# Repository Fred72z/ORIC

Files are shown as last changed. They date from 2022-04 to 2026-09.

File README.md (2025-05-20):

# BUS ORIC

Ensemble de platines pouvant se connecter sur un boitier principal connecté au port EXPANSION de l'oric.

# EXP CARTOUCHE
Extension permettant de remplacer la ROM interne par une cartouche ROM externe

# TELESTRAT II et TELESTRAT III

Nouvelles machines TELESTRAT.
(Dans la série si vous ne pouvez pas la trouver, faites la vous-même :)).

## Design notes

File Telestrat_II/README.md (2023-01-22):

# TELESTRAT II

Le TELESTRAT II est un TELESTRAT au format mini-ITX qui prend place dans un boîtier HTPC.
En plus des caractéristiques du TELESTRAT, la machine dispose en interne d'une horloge RTC, de 512Ko de ROM et de 144Ko de RAM et d'un lecteur GOTEK.
La machine est un mix entre l'ORIC ATMOS et le TELESTRAT. Elle dispose de 8 modes de fonctionnement allant de l'ORIC1 au TELESTRAT.
Elle est parfaitement compatible avec ses prédécesseurs ORIC1/ATMOS et microdisc.

Mode ORIC1
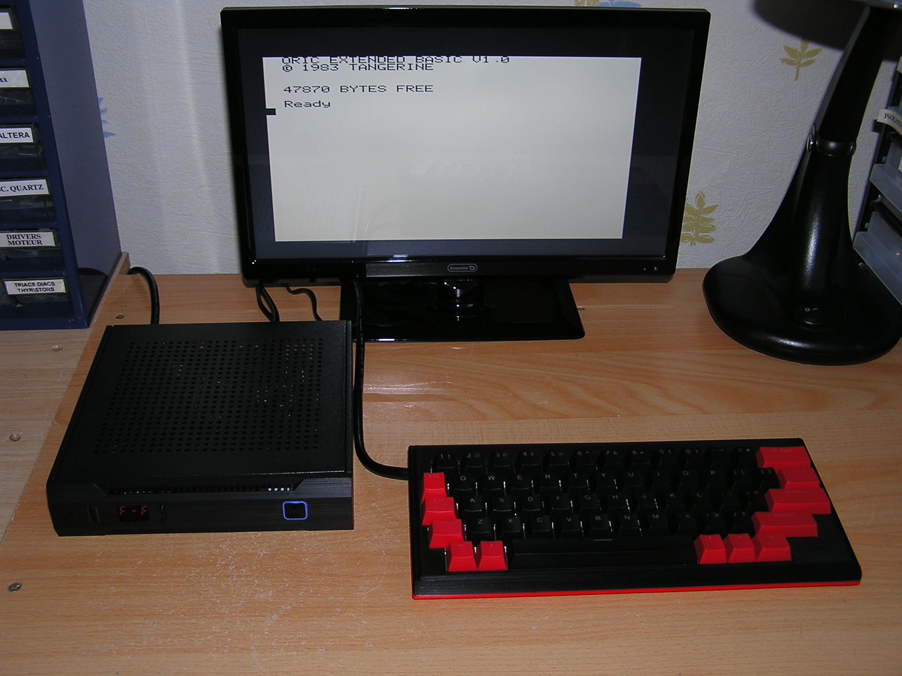
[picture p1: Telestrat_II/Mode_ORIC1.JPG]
Mode ORIC1 Optional Title


Mode ORIC ATMOS avec SEDORIC
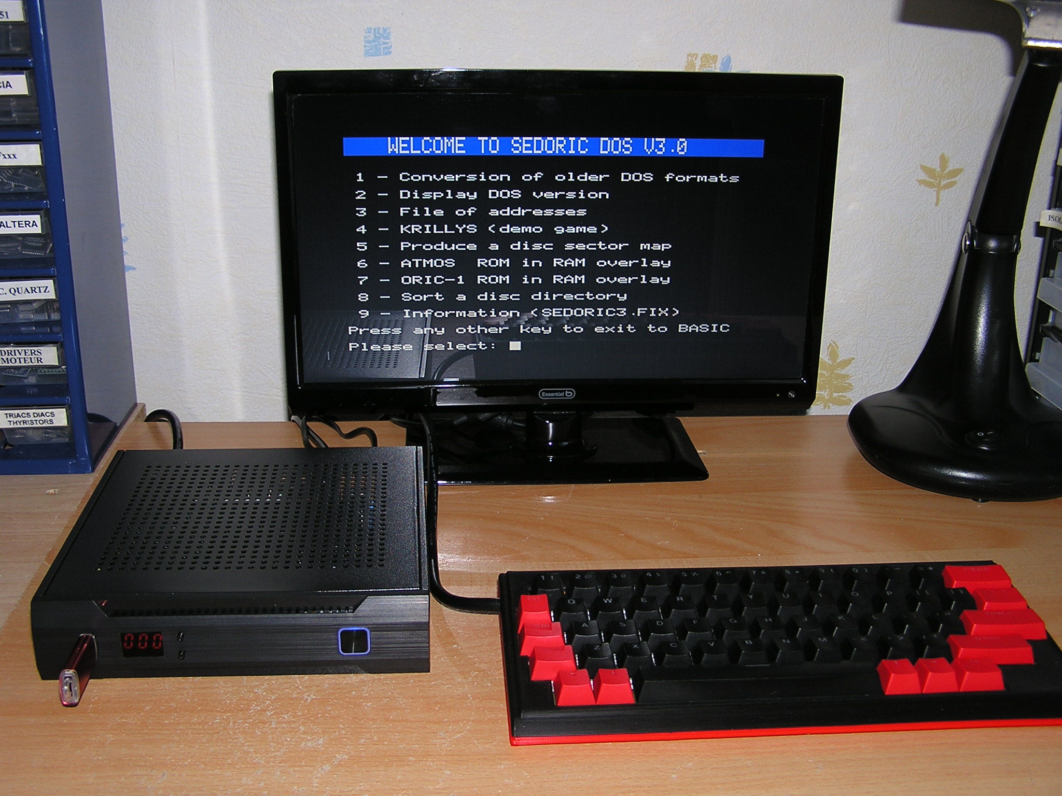
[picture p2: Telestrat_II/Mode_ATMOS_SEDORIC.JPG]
Mode ATMOS SEDORIC Optional Title


Mode TELESTRAT HYPERBASIC
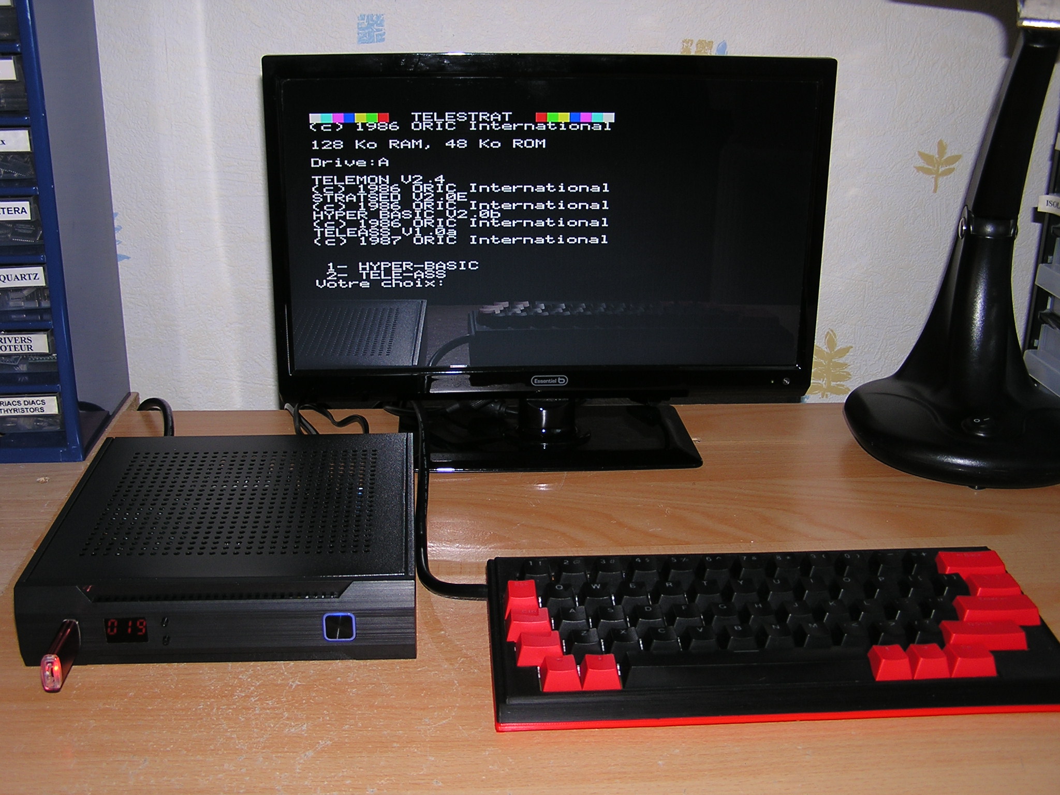
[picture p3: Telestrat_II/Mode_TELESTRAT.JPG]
Mode TELESTRAT HYPERBASIC Optional Title


Intérieur de la boîte
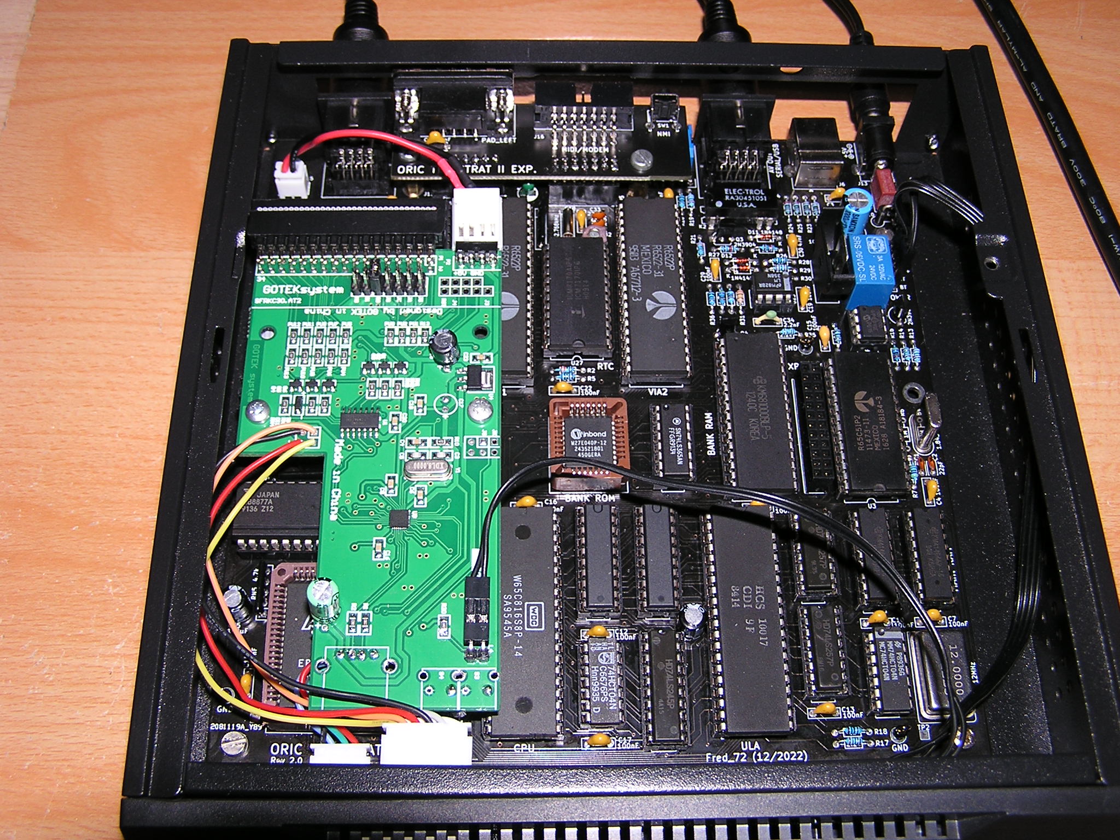
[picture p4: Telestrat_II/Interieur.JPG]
Intérieur Optional Title


Platine principale seule
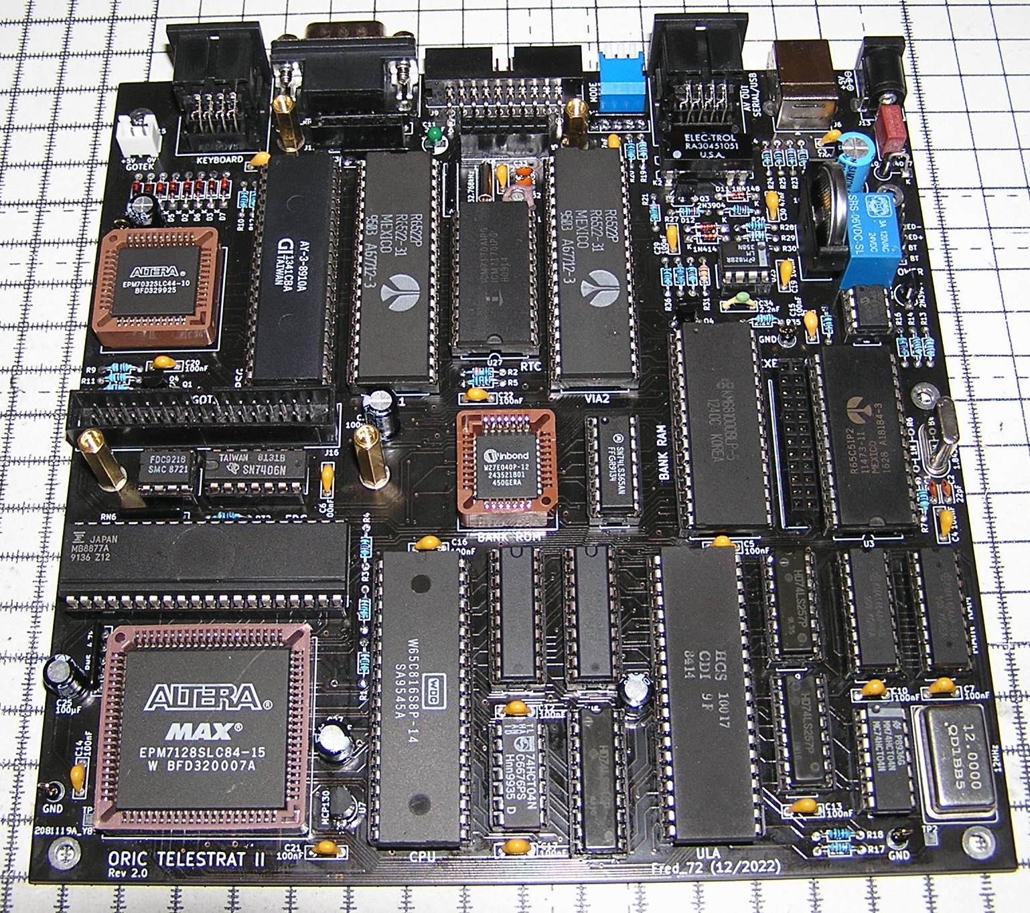
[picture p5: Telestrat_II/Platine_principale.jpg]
Platine principale Optional Title


# Connecteurs

Les connecteurs sont tous disposés à l'arrière de la machine à l'exception du port d'extension placé sur la carte mère.
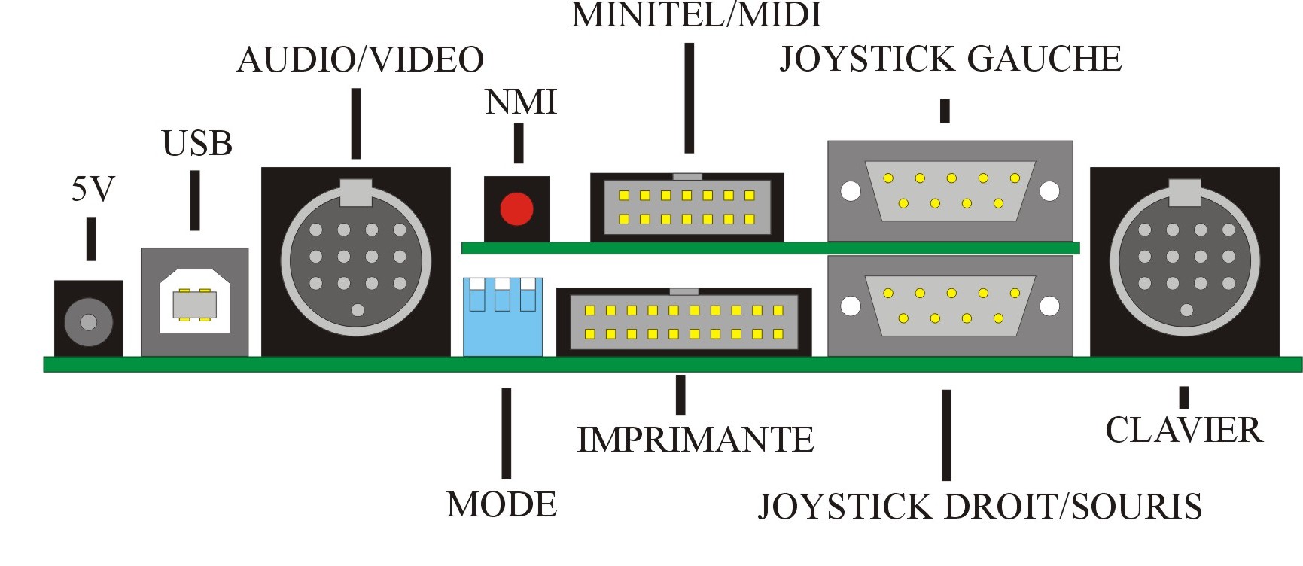
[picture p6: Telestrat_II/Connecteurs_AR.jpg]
Connecteurs Optional Title


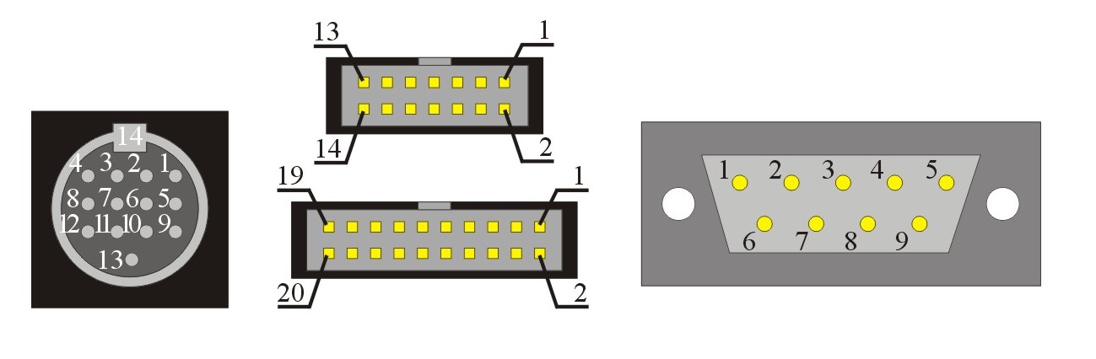
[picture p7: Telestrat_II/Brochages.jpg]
Brochages Optional Title


**AUDIO/VIDEO**

- 1 : REMOTE 
- 2 : +5V
- 3 : REMOTE 
- 4 : K7 IN
- 5 : K7 OUT
- 6 : NC
- 7 : SYNC
- 8 : ROUGE
- 9 : SOUND OUT
- 10 : GND
- 11 : VERT
- 12 : BLEU
- 13 : GND
- SHIELD : GND

**MINITEL/MIDI**

- 1  : GND
- 2  : BAUD_RATE
- 3  : PA3
- 4  : MINITEL_DATA_OUT
- 5  : PA6
- 6  : MINITEL_DATA_IN
- 7  : CB2
- 8  : CARRIER
- 9  : NC
- 10 : NC
- 11 : CA1
- 12 : CB1
- 13 : +5V
- 14 : GND

**IMPRIMANTE**

- 1  : /STB
- 3  : D0
- 5  : D1
 -7  : D2
 -9  : D3
- 11 : D4
- 13 : D5
- 15 : D6
- 17 : D7
- 19 : /ACK
- 2,4,...,20 : GND

**CLAVIER**

- 1  : COL0
- 2  : COL1
- 3  : COL2
- 4  : COL3
- 5  : COL7
- 6  : KBD2
- 7  : KBD1
- 8  : KBD0
- 9  : COL6
- 10 : COL5
- 11 : COL4
- 12 : KB
- 13 : +5V
- SHIELD : GND

**JOYSTICK GAUCHE**

- 1 : HAUT
- 2 : BAS
- 3 : GAUCHE
- 4 : DROIT
- 5 : NC
- 6 : TIR
- 7 : +5V
- 8 : GND
- 9 : NC

**JOYSTICK DROIT**

- 1 : HAUT
- 2 : BAS
- 3 : GAUCHE
- 4 : DROIT
- 5 : TIR2
- 6 : TIR
- 7 : +5V
- 8 : GND
- 9 : TIR3

**EXPANSION**
Un port d'extension est placé sur la carte principale. Il permet d'ajouter des périphériques en page 3 uniquement. Son brochage est le suivant:
[à venir]

# Modes de fonctionnement

Le Telestrat II dispose de 8 modes différents permettant de reproduire le fonctionnement de l'ORIC1, l'oric ATMOS ou l'oric TELESTRAT. Ces modes sont sélectionnés grace à 3 micro-interrupteurs "piano" accessibles à l'arrière de la machine.

4 modes sont réservés aux ORIC1/ATMOS et 4 modes sont réservés au TELESTRAT.

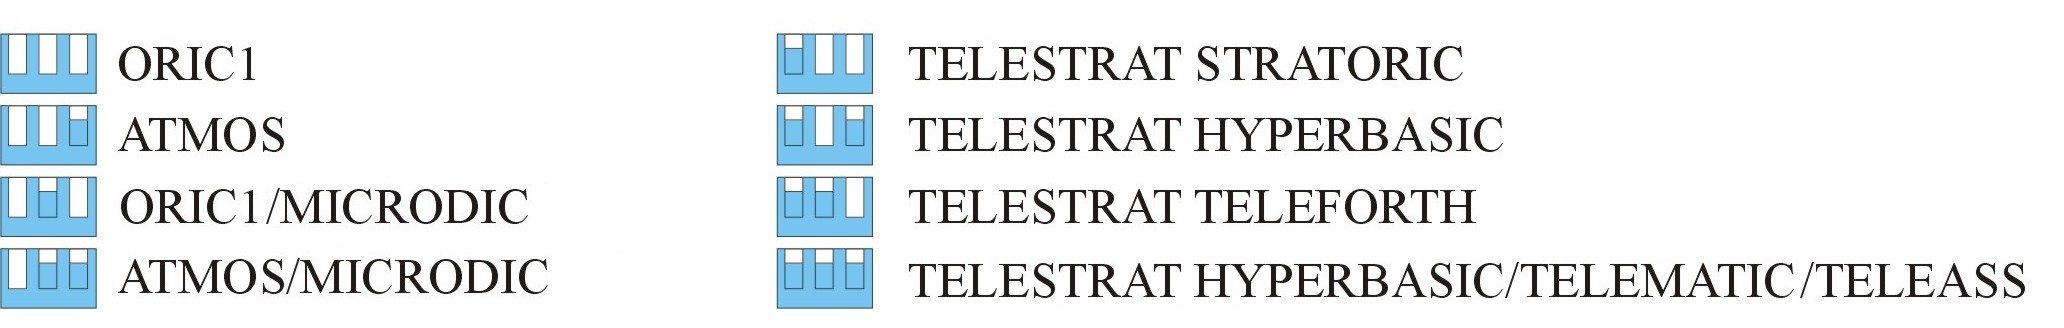
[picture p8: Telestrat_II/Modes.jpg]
Modes Optional Title


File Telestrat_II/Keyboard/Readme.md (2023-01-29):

# CLAVIER TELESTRAT II

[En attendant de trouver une solution plus élégante avc un mini clavier PC.]

Le clavier est constitué d'un circuit imprimé recevant des touches GATERON (rouge) avec des cabochons noirs et rouges (style ORIC oblige).
La barre d'espace reçoit 2 touches afin de l'équilibrer (une seule touche sur les photos). Les autres touches sont uniques.
Le boîtier est imprimé en 3D.

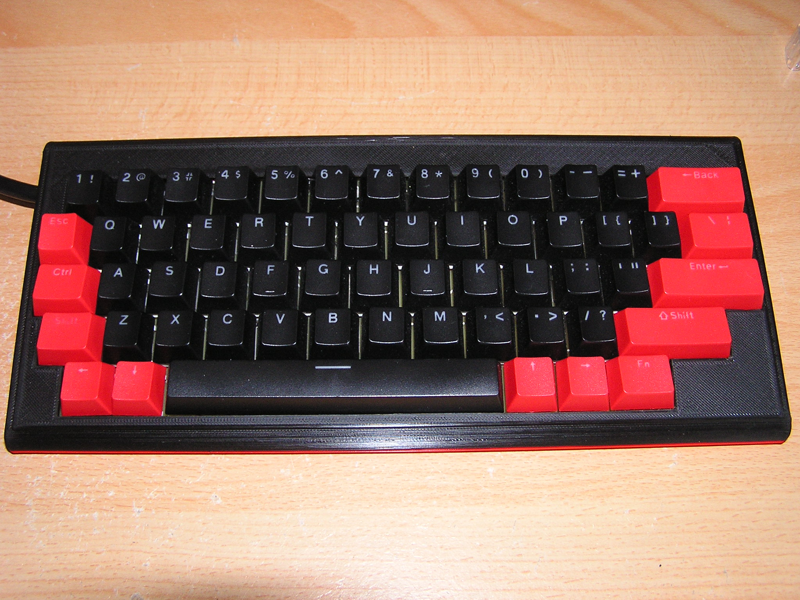
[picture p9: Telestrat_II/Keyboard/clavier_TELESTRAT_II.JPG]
Clavier TELESTRAT II Optional Title


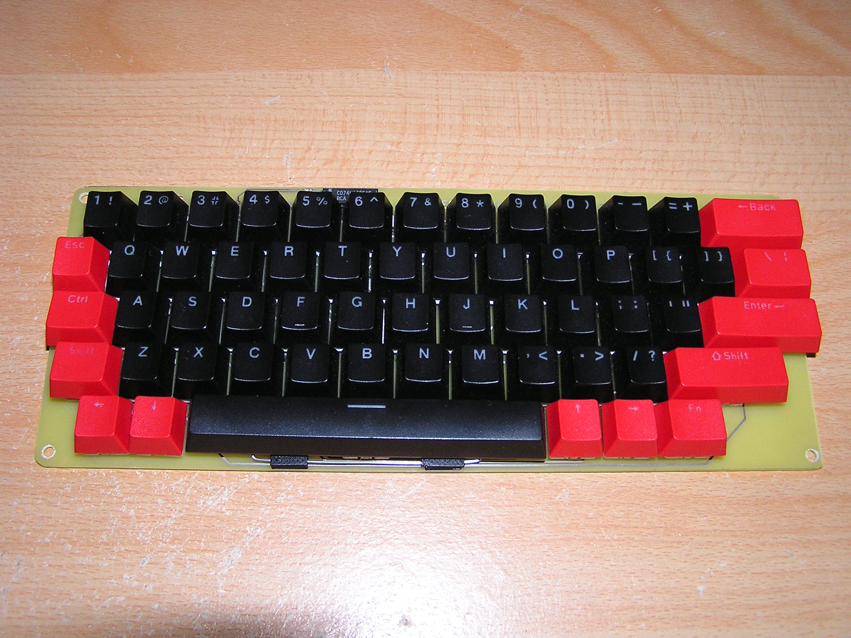
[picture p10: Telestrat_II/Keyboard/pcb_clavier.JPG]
Pcb Clavier Optional Title


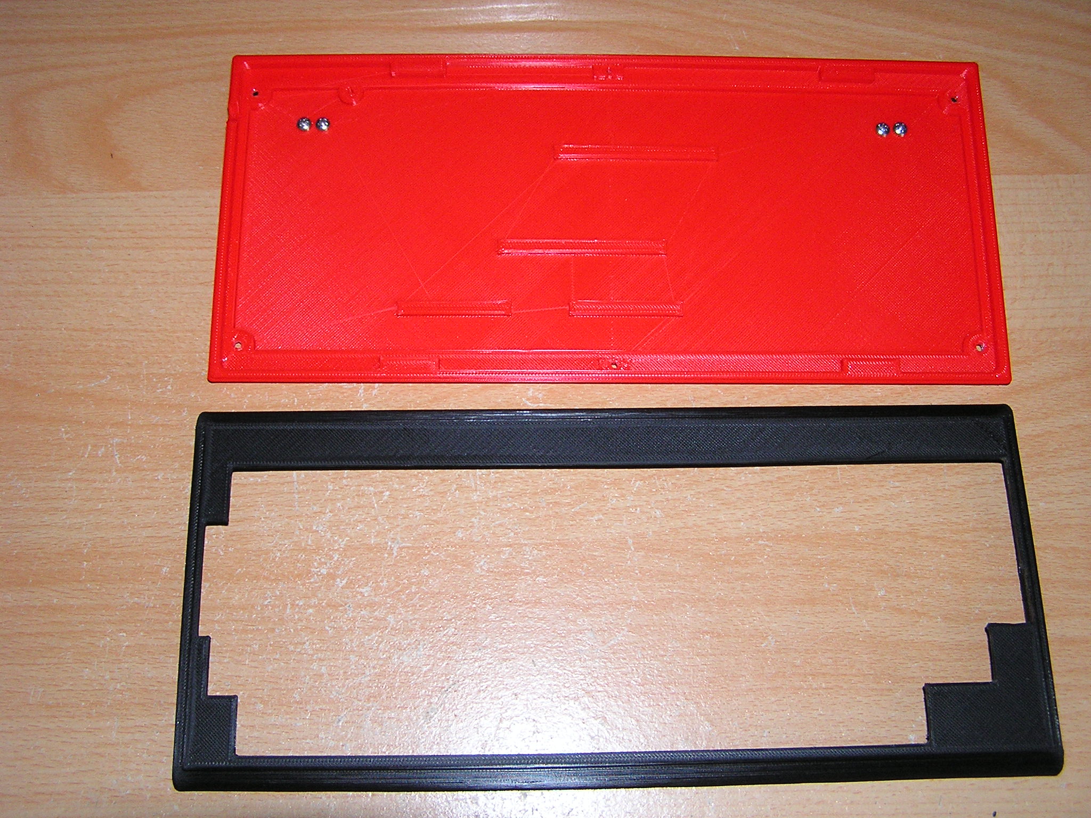
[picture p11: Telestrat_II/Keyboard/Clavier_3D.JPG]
Boîter 3D Optional Title


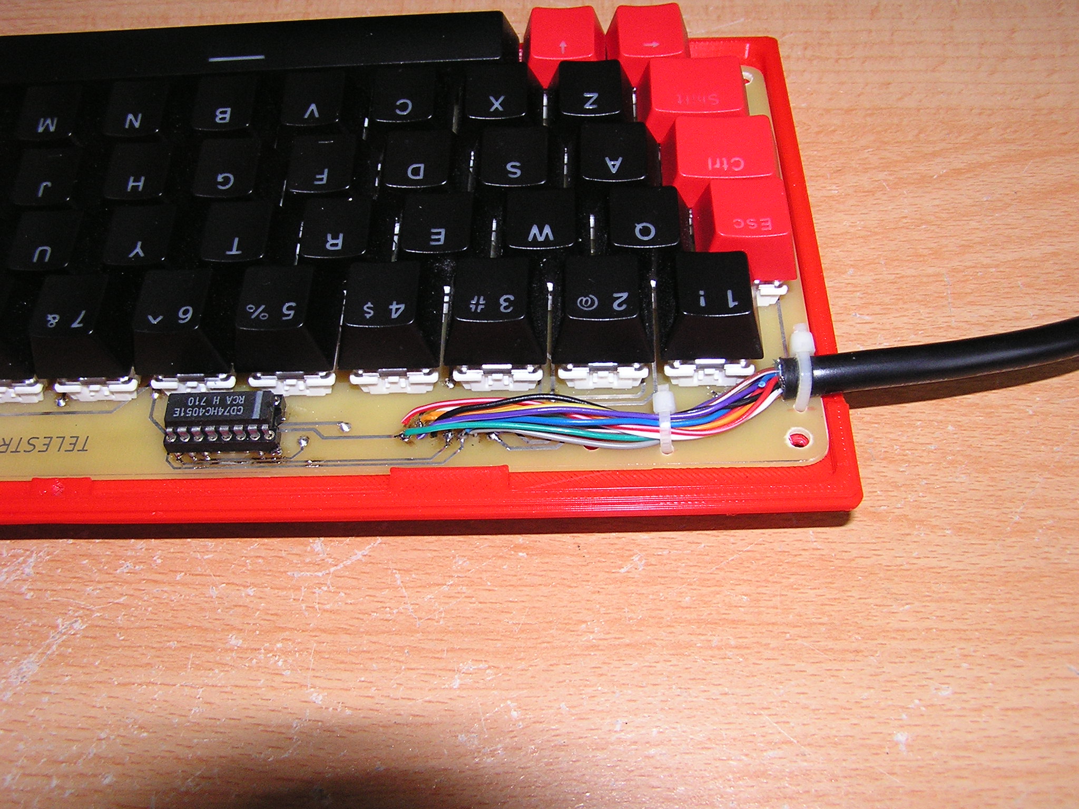
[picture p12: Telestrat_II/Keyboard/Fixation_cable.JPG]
Passage câble Optional Title


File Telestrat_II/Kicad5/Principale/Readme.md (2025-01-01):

# Platine principale

La dernière révision 2.2 adopte un circuit reset indépendant du CPLD et un connecteur IDC14 pour le clavier.
C'est la dernière version, il n'y en aura pas d'autres.

La platine connecteurs a été légérement modifiée et doit correspondre à cette version.
Le code CPLD est identique à la version 2.1.

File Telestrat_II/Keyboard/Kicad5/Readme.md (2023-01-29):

# CLAVIER TELESTRAT II

Les touches du clavier sont des CHERRY ou GATERON (rouge).
La barre d'espace reçoit 2 touches (préférable) ou une seule touche (ajout d'une barre pour l'équilibrer).
La vue 3D du PCB montre 3 touches pour la barre d'espace mais il ne faut en mettre qu'une ou deux.

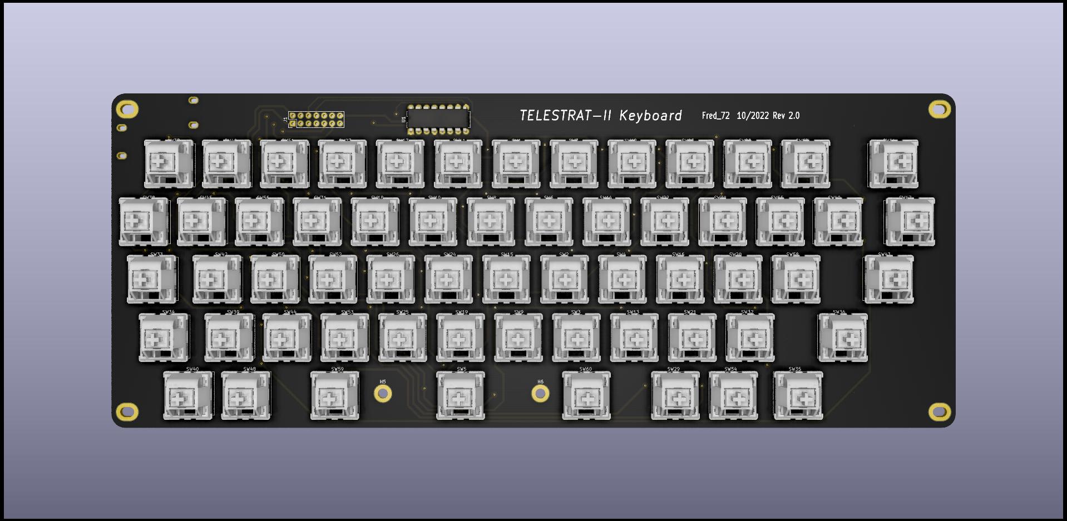
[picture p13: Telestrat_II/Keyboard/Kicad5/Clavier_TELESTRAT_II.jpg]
Clavier TELESTRAT II Optional Title


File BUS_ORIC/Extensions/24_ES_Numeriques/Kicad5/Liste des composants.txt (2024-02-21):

Liste des composants Carte E/S pour Oric

U1 : GAL 16V8
U2 : 82C55 ou 8255
C1 : 47µF /16V radial
C2 : 100nF pas 5mm
J1 : Connecteur IDC mâle 34 broches 90°
J2 : Connecteur IDC mâle 30 broches 90°

1x Support CI 40 broches/15.24mm
1x Support CI 20 broches/7.62mm

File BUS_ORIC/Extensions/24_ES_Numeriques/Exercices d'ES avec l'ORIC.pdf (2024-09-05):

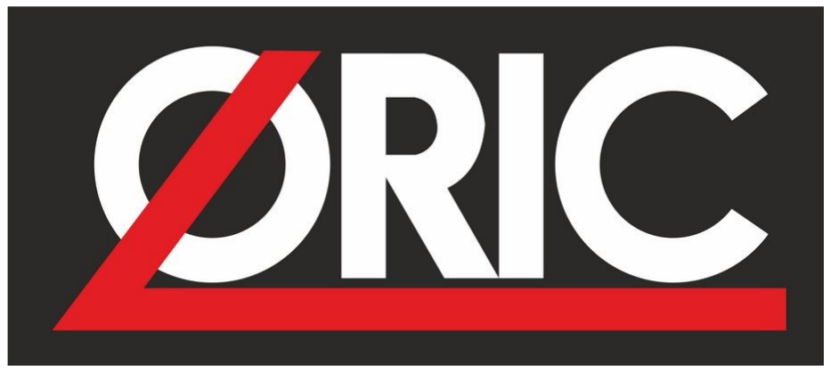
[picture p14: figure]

# ENTRÉES/SORTIES NUMÉRIQUES POUR ORIC

# EXERCICES APPLIQUÉS

Fred_72 | Version du 05/09/2024

## Sommaire

### Introduction

Ce document propose de vous initier à l’utilisation des entrées-sorties numériques avec votre ordinateur ORIC 1 ou ORIC ATMOS.
Vous serez guidé au fil des exemples d’application tout d’abord en BASIC puis progressivement en ASSEMBLEUR en commençant par des programmes simples puis de plus en plus compliqués vous permettant d’envisager des applications domotiques pilotées par votre ordinateur ORIC.
Ce document utilise l’extension 24 Entrées/Sorties pour ORIC présentée sur le forum system-cfg. Cette extension ajoute 24 E/S numériques [0V ou 5V] réparties sur 3 ports de 8 bits.
La correction des principaux exercices est dans le fichier « Exercice.dsk » associé.

### Brochage du connecteur E/S

La Figure 1 rappelle le brochage du connecteur IDC30 de cette extension.

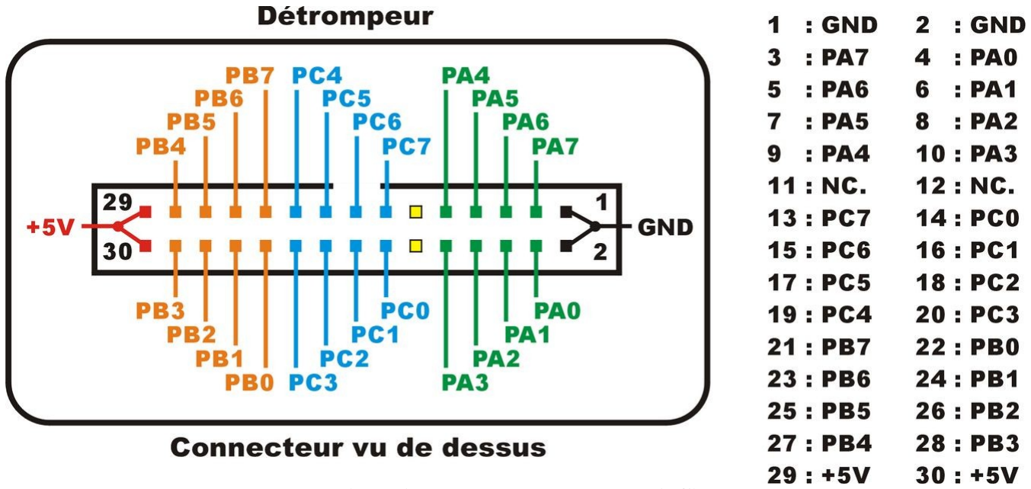
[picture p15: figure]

### Programmation

L’extension est accessible dans la mémoire principale de l’ORIC en page 3 [#300-#3FF] aux adresses #3FA à #3FD. Le circuit 8255 dispose de 4 registres accessibles aux adresses suivantes :

Adresse (hexadécimal) | Registre
#3FA | PORT A

#3FB | PORT B

#3FC | PORT C

#3FD | CONTROL

Tableau 1: Adresses des registres du circuit 8255

Figure 1: Brochage du connecteur d'E/S

### Registre de contrôle (#3FD)

Le registre de contrôle permet de définir le sens de fonctionnement des ports (entrée ou sortie). Il doit être défini au début du programme avant toute action sur les registres des ports.

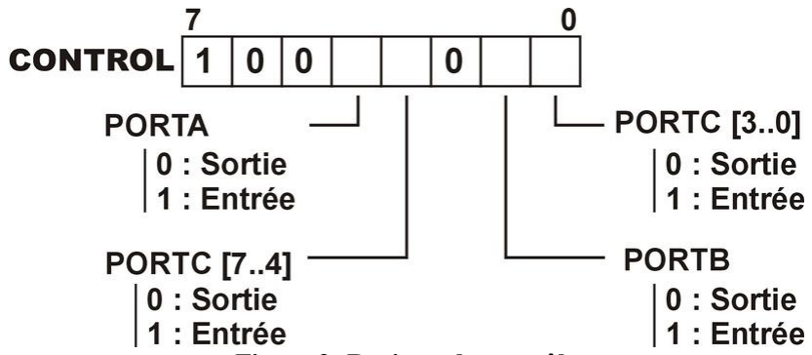
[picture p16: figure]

Le port C est coupé en deux blocs de 4 bits, le sens de fonctionnement des 4 bits de poids faibles et des bits de poids forts peut être défini indépendamment. Les autres ports peuvent seulement être tout en entrée ou tout en sortie.

Le Tableau 2 donne les valeurs du registre de configuration selon la direction des différents ports.

PORT A | PORT B | PORT C [7..4] | PORT C [3..0] | CONFIG (Hexa) | CONFIG (Décimal)
E | E | E | E | 9B | 155
E | E | E | S | 9A | 154
E | E | S | E | 93 | 147
E | E | S | S | 92 | 149
E | S | E | E | 99 | 153
E | S | E | S | 98 | 152
E | S | S | E | 91 | 148
E | S | S | S | 90 | 147
S | E | E | E | 8B | 139
S | E | E | S | 8A | 138
S | E | S | E | 83 | 131
S | E | S | S | 82 | 130
S | S | E | E | 89 | 137
S | S | E | S | 88 | 136
S | S | S | E | 81 | 129
S | S | S | S | 80 | 128

Tableau 2: Les différentes configurations possibles

Figure 2: Registre de contrôle

### Contrôle des ports

Le contrôle des ports d’entrées-sorties se fait à l’aide du code binaire traduisant les états ‘0’ ou ‘1’ de chaque bit de l’octet.

Chaque case (8 pour former un octet) correspond à un bit et le numéro placé au dessus indique sa position dans l’octet, c’est à dire sa pondération (2n
). Ainsi PA0 correspond au bit 0 du PORTA et PA7 au bit 7. Pour former une valeur numérique décimale plus compréhensible, il suffit d’ajouter toutes les valeurs des bits à 1 associées à leur pondération.

Valeur= PA0. 2 +PA1. 2 ⁰
1

+PA2. 2²

+PA3. 2³

+PA4. 2⁴

+PA5. 2⁵

+PA6 2⁶

+PA7. 2⁷
, soit en valeur
numérique : Valeur= PA0. 1 +PA1. 2 +PA2. 4 +PA3. 8 +PA4. 16 +PA5. 32 +PA6 64 +PA7. 128 Ce qui donne une plage de variation de 0 (tous les bits à 0) à 255 (tous les bits à 1).

Ainsi la valeur représentée sur la Figure 3 est : 1.1+1.2+1.16+1.64= 83 en décimal.

Figure 3: Octet en binaire

### Exercice 1 (Led)

But : Faire clignoter deux leds
Les 2 leds sont connectées sur les broches PA0 et PA1 du PORTA selon les branchements de la Figure 4 (la patte la plus longue de la led est le +). Une résistance de limitation de 220 ohms est câblée en série avec chaque led. Elle est indispensable pour ne pas endommager les leds.

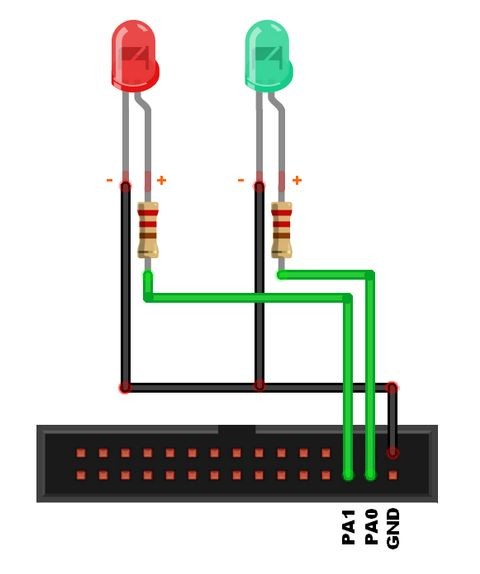
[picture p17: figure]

Ce Programme BASIC permet de faire clignoter les 2 leds simultanément.

### 10 CLS 20 PRINT "COMMANDE DES LEDS DU PORT A" 30 POKE #3FD,139 40 POKE #3FA,3 50 GOSUB 100 60 POKE #3FA,0 70 GOSUB 100 80 GOTO 40

100 REM TEMPORISATION
110 FOR I=1 TO 400
120 NEXT I
130 RETURN

Figure 4: Leds clignotantes

La ligne 30 place le PORTA en sortie. Les PORTB et PORTC sont laissés en entrée. La valeur 139 est obtenue à l’aide du Tableau 2.
La ligne 40 met les bits PA0 et PA1 à 1, les autres (PA2 à PA7) sont à 0. Cela allume les 2 leds.
La ligne 60 met tous les bits du PORTA à 0 et éteint les 2 leds.

La temporisation appelée par les lignes 50 et 70 permet de ralentir le rythme du clignotement.

### Modification

Le programme précédent fait clignoter les leds simultanément. En modifiant les valeurs écrites sur le PORTA (lignes 40 et 60), il est possible de faire clignoter les leds alternativement.

Les nouvelles lignes sont :

### 40 POKE #3FA,1 60 POKE #3FA,2

Cela correspond aux nouvelles valeurs binaires suivantes :

Question

Comment faut-il modifier le programme pour accélérer ou ralentir le rythme du clignotement ?

Figure 5: Allumage/Extinction des leds

Figure 6: Clignotement alterné des LEDs

### Exercice 2 (Led et BP)

But : Commander l’allumage des leds avec un bouton poussoir
Comme l’exercice précédent, les 2 leds sont connectées sur les broches PA0 et PA1 du PORTA selon les branchements de la Figure 7. Elles sont accompagnées d’un bouton poussoir et d’une résistance de 4.7 kilo-ohms connectés sur la broche PB0.

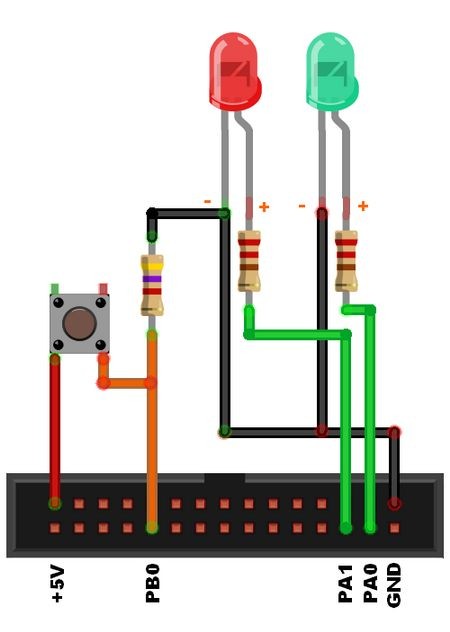
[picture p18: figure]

La résistance de 4.7 kilo-ohms permet de maintenir un état ‘0’ lorsque le bouton poussoir est relâché. Sans cette résistance, la tension sur la broche PB0 est flottante ce qui se traduit par une lecture aléatoire de ‘1’ et de ‘0’ sur cette entrée.
Ce programme BASIC permet d’allumer la led verte lorsque le bouton poussoir est appuyé et la led rouge lorsqu’il est relâché.

### 10 CLS 20 PRINT "COMMANDE PAR BP DES LEDS DU PORT A" 30 POKE #3FD,139 40 A=2 50 IF (PEEK(#3FB) AND 1) <>0 THEN A=1 60 POKE #3FA,A 70 GOTO 40

L’écriture des valeurs vers le PORTA se fait de la même façon que précédemment avec les valeurs 1 et 2 permettant d’allumer la seule led verte ou la seule led rouge.
La lecture fait appel à la commande PEEK(#3FB) permettant au BASIC de récupérer la valeur lue sur le PORTB.
Le bouton poussoir n’est raccordé qu’à la broche PB0, il convient donc de filtrer la valeur lue pour n’avoir que l’information relative à l’état logique du bouton poussoir (bit 0).

Figure 7: Commande par BP

Pour cela le programme utilise l’opérateur AND (ET logique). Cet opérateur binaire agit de la façon suivante (A et B sont les valeurs d’entrées, S est la sortie) :

A | B | S
0 | 0 | 0
0 | 1 | 0
1 | 0 | 0
1 | 1 | 1

Tableau 3: Opérateur AND
Pour obtenir un 1 logique, il faut que les 2 entrées A et B soient à 1.
Dans le programme, la même opération est effectuée pour chaque bit de l’octet. Cela conduit à :

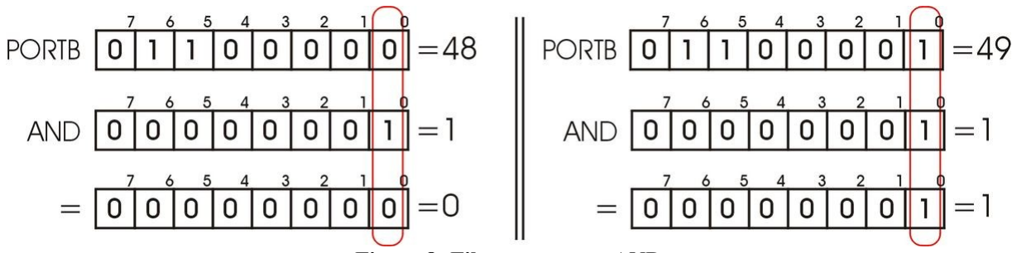
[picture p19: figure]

Sur cette figure, les bits 5 et 6 sont à 1 traduisant des états indésirables ou issus d’autres boutons poussoirs. Le masque associé à l’opérateur AND vaut 1 ce qui permet de ne sélectionner que le bit PB0 du PORTB. Il en ressort une valeur numérique qui vaut soit 0 (BP relâché) soit 1 (BP appuyé). Le programme fait cette opération en ligne 50 puis modifie ou non la valeur contenue dans A en fonction de l’état logique du bouton poussoir. Il ne reste plus qu’à écrire la valeur A sur le PORTA pour allumer la led correspondante.

Figure 8: Filtrage avec un AND

S=A AND B

### Modification

On ajoute un 2ème bouton poussoir connecté à PB1.

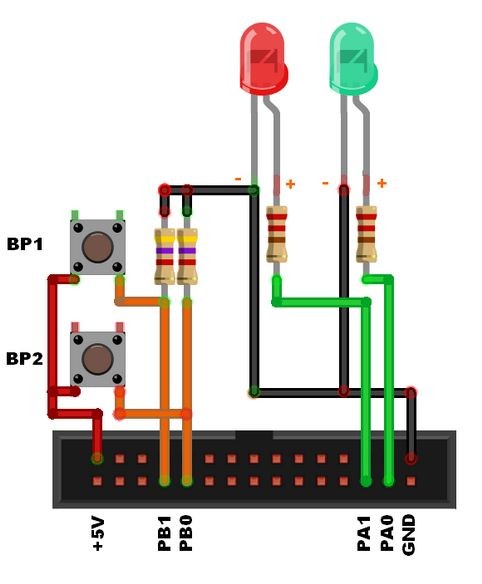
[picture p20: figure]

Ce nouveau programme BASIC permet d’allumer la led rouge lorsque le bouton poussoir BP1 est appuyé et la led verte lorsque le bouton poussoir BP2 est appuyé. Enfin, les 2 leds sont allumées si les 2 boutons poussoirs sont appuyés simultanément.

### 10 CLS 20 PRINT "COMMANDE PAR 2 BPS DES LEDS DU PORT A" 30 POKE #3FD,139 40 A=0 50 IF (PEEK(#3FB) AND 1) <>0 THEN A=1 60 B=0 70 IF (PEEK(#3FB) AND 2) <>0 THEN B=2 80 POKE #3FA, A OR B 90 GOTO 40

La lecture fait toujours appel à la routine READ suivie de la commande PEEK associée à l’opérateur AND, mais cette fois les valeurs 1 et 2 sont utilisées pour tester les 2 boutons poussoirs.

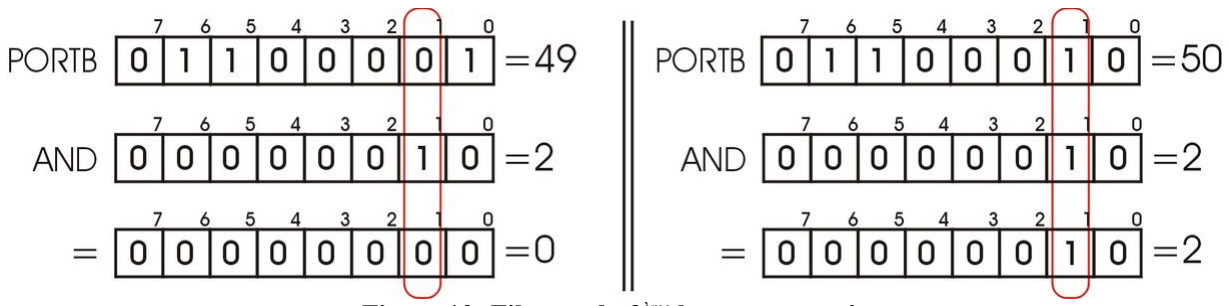
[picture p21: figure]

Pour BP2, le résultat de l’opération vaut 0 ou 2. C’est la raison pour laquelle le programme utilise le test <> 0 plutôt qu’un test d’égalité.

Figure 9: Commande par 2 BPs

Figure 10: Filtrage du 2ème bouton poussoir

Le programme utilise 2 variables A et B pour avoir 2 valeurs de commande du PORTA. La modification du port se fait par une écriture unique qui va combiner les 2 variables pour former une seule valeur finale à l’aide de l’opérateur OR (OU logique).

Cet opérateur binaire agit de la façon suivante (A et B sont les valeurs d’entrées, S est la sortie) :

A | B | S
0 | 0 | 0
0 | 1 | 1
1 | 0 | 1
1 | 1 | 1

Tableau 4: Opérateur OR
Pour obtenir un 1 logique, il suffit qu’une des 2 entrées (A ou B) soit à 1.
Dans le programme, cette opération est utilisée avec les variables A et B. Cela conduit à :

Remarque : Il est possible d’utiliser l’opérateur addition (+) pour arriver au même résultat dans le cas de variables distinctes (c’est à dire qui n’utilise pas les mêmes bits). C’est le cas ici car A utilise le bit 0 tandis que B utilise le bit 1 (c’est pour cela que dans le programme il est écrit B=2).

Question
Comment faut-il modifier le programme si BP2 est connecté sur la broche PB4 ?

S=A OR B

Figure 11: Association des variables A et B du programme

### Exercice 3 (Led et LDR)

But : Commander l’allumage de la led selon la luminosité
La led est associée à une photorésistance (LDR). La photorésistance est un composant dont la résistance varie selon la lumière. Une résistance de 15 kilo-ohms forme un diviseur de tension avec la photorésistance afin d’obtenir une tension dépendant de la luminosité. Si le composant est exposé à une lumière vive, sa résistance est faible et la tension en PB1 est élevée (proche de 5V). Si le composant est maintenu dans l’obscurité, sa résistance est grande et la tension en PB1 est faible (proche de 0V). L’entrée PB1 ne peut pas directement mesurer une tension (il faudrait un convertisseur analogique/numérique pour cela) mais elle réagit à partir d’un certain niveau (environ 2V) au dessus duquel elle voit un niveau ‘1’ sinon elle voit un niveau ‘0’.

Question

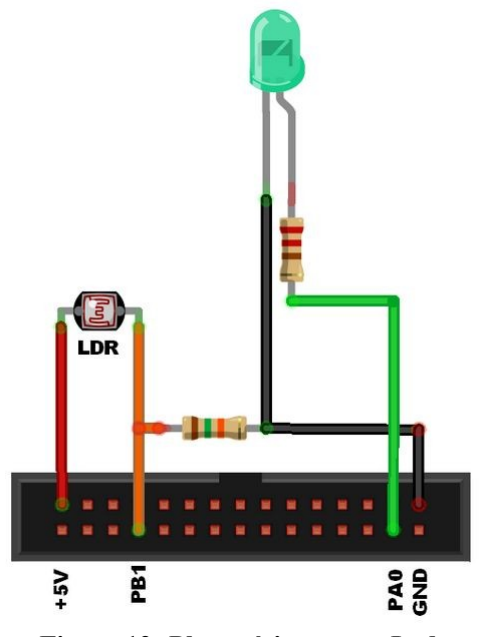
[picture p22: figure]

Le but est ici de créer un interrupteur crépusculaire. Le jour (lorsque le capteur est éclairé), la led est éteinte et la nuit (lorsque le capteur est dans l’obscurité), la led est allumée. Comment faut-il modifier le programme de l’exercice précédent pour obtenir le fonctionnement désiré ?

Figure 12: Photorésistance et Led

### Modification

On ajoute à présent un détecteur de mouvement (PIR) sur l’entrée PB0.

Question

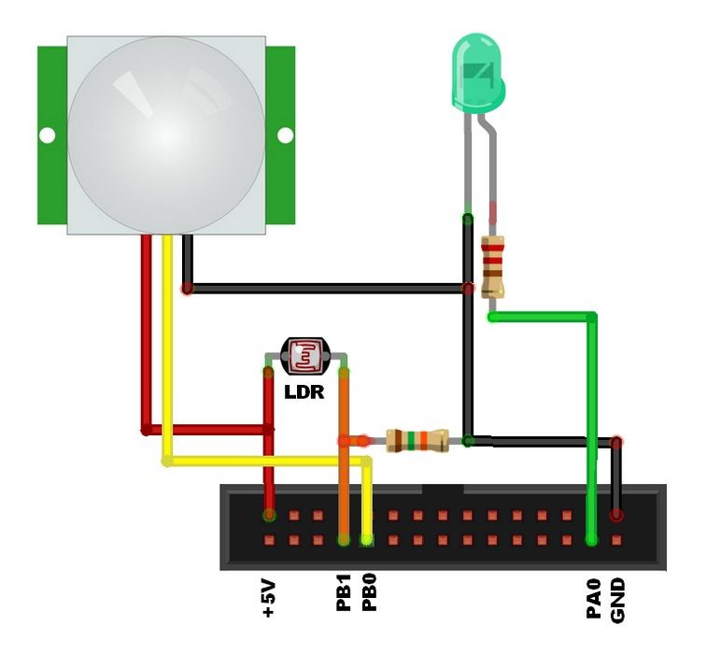
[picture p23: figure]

Le but est maintenant de créer un interrupteur crépusculaire à détection de mouvement. Le jour, lorsque le capteur est éclairé, la led est éteinte et la nuit, lorsque le capteur est dans l’obscurité et qu’un mouvement est détecté, la led s’allume pendant 10 secondes. Comment faut-il modifier le programme pour obtenir le fonctionnement désiré ?

Figure 13: Interrupteur crépusculaire 2

### Exercice 4 (Chenillard à Leds)

But : Faire un chenillard avec 8 leds
Les 8 leds sont connectées sur les broches PA0 à PA7 du PORTA selon les branchements de la Figure 14. Une seule led est allumée à la fois dans une séquence de défilement de la droite vers la gauche ou de la gauche vers la droite.

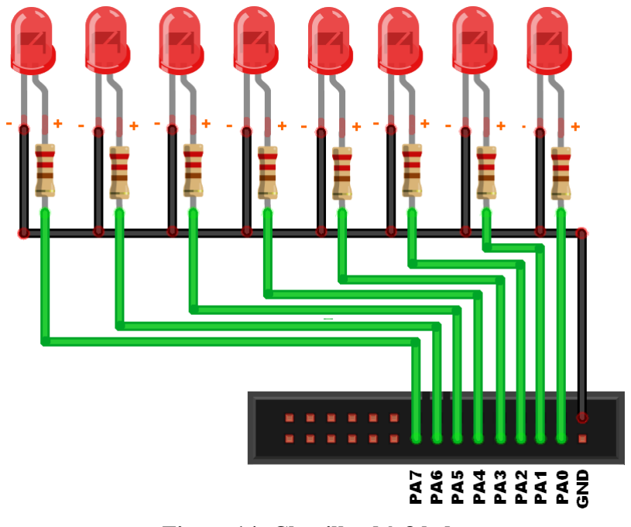
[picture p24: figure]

Ce programme BASIC permet de faire défiler une led allumée parmi les 8 en la faisant glisser de la droite vers la gauche au rythme de la temporisation.

### 10 CLS 20 PRINT "CHENILLARD SUR LE PORT A" 30 POKE #3FD,139 40 A=1 50 FOR K=1 TO 8 60 POKE #3FA, A 70 GOSUB 200 80 A=A*2 90 NEXT K 95 GOTO 40

200 REM TEMPORISATION
210 FOR I=1 TO 200
220 NEXT I
230 RETURN

### Modifications

Comment faut-il modifier le programme pour obtenir un défilement de la gauche vers la droite ? Comment faut-il modifier le programme pour obtenir un défilement dans les 2 sens (style K2000) ?

Figure 14: Chenillard à 8 leds

### Exercice 5 (7 segments)

But : Commander un afficheur 7 segments
Cet exercice fait appel à un afficheur 7 segments pour afficher les chiffres de 0 à 9. Dans cet exercice l’afficheur utilisé est un HS-5161A à cathodes communes. Il est bien sûr possible d’utiliser n’importe quel afficheur à cathodes communes mais il faudra adapter le câblage selon son brochage. Le terme cathodes communes signifie que la cathode (le -) des leds constituant les 7 segments de l’afficheur sont raccordées ensemble à l’intérieur de l’afficheur. Cela permet de réduire le nombre de broches nécessaires à seulement 9 pour 7 segments + le point décimal.
Pour allumer un segment, il faut mettre à ‘1’ (+5V) la broche concernée. Comme pour les exercices précédents, le courant dans les leds doit être limité par une résistance de 470 ohms en série avec chaque led.


Figure 15: Commande d'un afficheur 7 segments

### Codage des chiffres

L’afficheur est constitué de 7 segments (le point décimal n’est pas utilisé) placés judicieusement pour former un chiffre. Les segments sont nommés ‘A’ à ‘G’ selon la disposition de la figure.
Pour avoir un affichage cohérent, il faut coder l’information numérique (0 à 9) en une valeur permettant d’allumer les segments pour former un chiffre sur l’afficheur. Ce codage est réalisé par le programme à l’aide d’un tableau de 10 cases contenant les valeurs de commande de l’afficheur. Il suffit d’indexer le tableau avec la valeur numérique pour obtenir la valeur de commande de l’afficheur. Le Tableau 5 donne le codage des chiffres de 0 à 9.


Chiffre | G | F | E | D | C | B | A | Valeur décimale
0 | 0 | 1 | 1 | 1 | 1 | 1 | 1 | 63
1 | 0 | 0 | 0 | 0 | 1 | 1 | 0 | 6
2 | 1 | 0 | 1 | 1 | 0 | 1 | 1 | 91
3 | 1 | 0 | 0 | 1 | 1 | 1 | 1 | 79
4 | 1 | 1 | 0 | 0 | 1 | 1 | 0 | 102
5 | 1 | 1 | 0 | 1 | 1 | 0 | 1 | 109
6 | 1 | 1 | 1 | 1 | 1 | 0 | 1 | 125
7 | 0 | 0 | 0 | 0 | 1 | 1 | 1 | 7
8 | 1 | 1 | 1 | 1 | 1 | 1 | 1 | 127
9 | 1 | 1 | 0 | 1 | 1 | 1 | 1 | 111

Tableau 5: Codage des chiffres sur un afficheur 7 segments

Ce Programme BASIC permet de compter de 0 à 9 sur l’afficheur.

### 10 CLS 15 GOSUB 1000 20 PRINT "COMPTAGE SUR UN AFFICHEUR" 30 POKE #3FD,139 40 FOR N=0 TO 9 50 POKE #3FA, A (N) 60 GOSUB 100 70 NEXT N 80 GOTO 40

100 REM TEMPORISATION
110 FOR I=1 TO 400
120 NEXT I
130 RETURN

1000 REM CHARGEMENT DES CODES 7 SEGMENTS 1010 DIM A(10)
1020 FOR I=0 TO 9
1030 READ A(I)
1040 NEXT I
1050 RETURN
1060 DATA 63,6,91,79,102,109,125,7,127,111

La 1ère partie du programme appelle le sous-programme placé à partir de la ligne 1000 pour remplir les cases du tableau A avec les 10 valeurs permettant de visualiser des chiffres compréhensibles sur l’afficheur 7 segments (valeurs placées dans la ligne DATA en 1060).
Les lignes 40 à 70 mettent en place une boucle de comptage FOR-NEXT durant laquelle N parcourt les valeurs 0 à 9.
La ligne 50 envoie sur le PORTA la valeur correspondant au chiffre N en utilisant le tableau A pour transformer cette valeur numérique en code ‘7 segments’.
Le sous-programme placé à partir de la ligne 100 est une temporisation permettant de ralentir le programme.

### Exercice 6 (7 segments + 4511)

But : Commander un afficheur 7 segments avec un CI décodeur

Cet exercice fait toujours appel à un afficheur 7 segments pour afficher les chiffres de 0 à 9 mais cette fois utilise un circuit intégré décodeur HEF4511. L’utilisation de ce circuit permet de n’utiliser que 4 bits de commande et permet de se passer du programme de codage.
Il suffit d’envoyer la valeur numérique sur la partie basse du port (PA[0..3]) pour obtenir l’affichage du chiffre souhaité. Toutefois le CI décodeur ne peut afficher que les chiffres de 0 à 9.


Ce Programme BASIC permet de compter de 0 à 9 sur l’afficheur.

### 10 CLS 20 PRINT "COMPTAGE SUR UN AFFICHEUR" 30 POKE #3FD,139 40 FOR N=0 TO 9 50 POKE #3FA, N 60 GOSUB 100 70 NEXT N 80 GOTO 40

100 REM TEMPORISATION
110 FOR I=1 TO 400
120 NEXT I
130 RETURN

Figure 16: Commande d'un afficheur 7 segments avec un CI décodeur

### Exercice 7 (7 segments + Clavier)


But : Lire un clavier à matrice
Cet exercice fait appel à un afficheur 7 segments et un clavier à 16 touches. Le but de l’exercice est de visualiser la touche appuyée sur l’afficheur 7 segments.

### Clavier

Le clavier est constitué de 16 touches réparties en 4 colonnes de 4 rangées (soit 4x4 touches). Cette façon de faire économise des fils mais nécessite une lecture active du clavier.

Figure 17: Clavier et afficheur 7 segments

Figure 18: Matrice du clavier 16 touches

Pour lire le clavier, il faut disposer de 4 entrées et 4 sorties. Le principe consiste à alimenter une seule rangée à la fois puis à lire les 4 colonnes. La lecture du clavier nécessite donc 4 cycles. Il reste ensuite à identifier la touche pressée.
Sur le schéma, il y a des résistances de tirage à ‘0’ (4.7kilo-ohms) et des diodes (1N4148). Les résistances permettent de maintenir un état ‘0’ en l’absence d’action sur les touches du clavier (même principe que pour un bouton poussoir). Les diodes permettent de séparer les sorties. Si 2 touches sont appuyées simultanément, 2 sorties peuvent être en court-circuit (l’une est à ‘1’ et l’autre à ‘0’). Les diodes ne laissant passer le courant que dans un seul sens interdisent ce cas de figure. Elles ne sont pas nécessaires si l’utilisateur appuie sur une seule touche à la fois.
Sur le clavier, les caractères # et * sont remplacés par les lettres ‘E’ et ‘F’.

### Codage des lettres

Les chiffres ont déjà été codés dans l’exercice 5 mais il reste les lettres ‘A’ à ‘F’. Le Tableau 6 donne les valeurs associées à ces nouveaux caractères.

Caractère | G | F | E | D | C | B | A | Valeur décimale
A | 1 | 1 | 1 | 0 | 1 | 1 | 1 | 119
B | 1 | 1 | 1 | 1 | 1 | 0 | 0 | 124
C | 0 | 1 | 1 | 1 | 0 | 0 | 1 | 57
D | 1 | 0 | 1 | 1 | 1 | 1 | 0 | 94
E | 1 | 1 | 1 | 1 | 0 | 0 | 1 | 121
F | 1 | 1 | 1 | 0 | 0 | 0 | 1 | 113

Tableau 6: Codage des caractères supplémentaires

Ce programme BASIC permet de lire le clavier et d’afficher le caractère de la touche pressée sur l’afficheur. Il est supposé que l’utilisateur appuie sur une seule touche à la fois.

### 10 CLS 15 GOSUB 1000 20 PRINT "LECTURE CLAVIER 16 TOUCHES" 30 POKE #3FD,131

100 REM PROGRAMME PRINCIPAL
110 GOSUB 200
115 PRINT @2,4;KB;" "
120 IF KB<>255 THEN POKE #3FA,A(KB) 130 IF KB=255 THEN POKE #3FA,0
140 GOTO 110

200 REM LECTURE CLAVIER
210 POKE #3FC,16
220 R1=PEEK(#3FB) AND 15
230 POKE #3FC,32
240 R2=PEEK(#3FB) AND 15
250 POKE #3FC,64
260 R3=PEEK(#3FB) AND 15
270 POKE #3FC,128
280 R4=PEEK(#3FB) AND 15
290 B=0
300 IF R1+R2+R3+R4=0 THEN KB=255:GOTO 350 310 IF R1>0 THEN B=R1:GOSUB 400: KB=C1(B) 320 IF R2>0 THEN B=R2:GOSUB 400: KB=C2(B) 330 IF R3>0 THEN B=R3:GOSUB 400: KB=C3(B) 340 IF R4>0 THEN B=R4:GOSUB 400: KB=C4(B) 350 RETURN

400 REM CONVERSION
410 IF B=4 THEN B=3
420 IF B=8 THEN B=4
430 RETURN

1000 REM VARIABLES POUR LE CLAVIER 1010 DIM A(16),C1(5),C2(5),C3(5),C4(5) 1020 FOR V=0 TO 15
1030 READ A(V)
1040 NEXT V
1050 FOR V=1 TO 4
1060 READ C1(V),C2(V),C3(V),C4(V)
1070 NEXT V
1080 DATA 63,6,91,79,102,109,125,7,127,111,119,124,57,94,121,113 1090 DATA 1,4,7,14,2,5,8,15,3,6,9,0,10,11,12,13
1100 RETURN

Le sous programme à partir de la ligne 1000 initialise le tableau A avec les codes ‘7 segments’ des caractères et les tableaux C1 à C4 avec les valeurs correspondant aux 4 colonnes du clavier.
Le sous-programme placé à partir de la ligne 200 permet de lire le clavier. Pour cela, chaque rangée est mise à ‘1’ à tour de rôle puis les 4 bits correspondants aux 4 rangées sont lus et stockés dans les variables R1 à R4. Les valeurs lues sont filtrées par un opérateur AND afin de ne garder que les 4 bits de poids faible.
Si aucune touche n’est appuyée, les variables R1 à R4 contiennent toutes la valeur 0.
Selon la touche appuyée les valeurs dans les variables R1 à R4 peuvent prendre les valeurs 1, 2, 4 ou 8. Cette valeur est ramenée à 1, 2, 3 ou 4 par le petit sous-programme commençant à la ligne 400 afin d’aligner cette valeur sur les cases des tableaux C1 à C4.

### Question

Comment faut-il modifier le programme pour s’assurer que l’utilisateur n’appuie que sur une seule touche à la fois ?

### Exercice 8 (SR04)

But : Mesurer la distance avec un radar à ultrasons SR04
Cet exercice permet de mesurer la distance d’un objet à l’aide d’un module SR04.

Principe de la mesure


A la réception de l’impulsion de commande TRIG, le module émet une salve d’impulsions sonores (ultrasons à 40kHz). L’onde sonore va se réfléchir sur l’obstacle puis revenir vers le module. La mesure du temps entre l’émission et la réception permet de déduire la distance séparant le module de l’obstacle. Le module ne retourne pas directement la distance mais donne une impulsion dont la durée correspond au temps de vol (c’est à dire le temps nécessaire pour faire l’aller-retour).

Figure 19: Mesure de distance


Figure 20: SR04 - Principe de la mesure

La commande et la mesure nécessitent des temps très brefs, donc cette partie est assurée par un programme assembleur appelé par le programme BASIC à l’aide de la commande CALL.

5 HIMEM #7FFF 10 CLS 20 FOR A=#8000 TO #8050 30 READ V 40 POKE A,V 50 NEXT A 60 DATA 169,139,141,253,3,120,169,1,141,250,3,169,0,169,0,169,0,169,0,169 70 DATA 0,141,250,3,162,0,232,240,50,173,252,3,41,1,240,246,169,0,141 80 DATA 0,129,141,1,129,141,2,129,173,0,129,24,105,1,141,0,129 90 DATA 173,1,129,105,0,141,1,129,173,2,129,105,0,141,2,129 95 DATA 173,252,3,41,1,208,224,88,96

100 PRINT "CONTROLE D'UN SONAR SR04"
110 PRINT "AVEC LA CARTE 24 ENTREES SORTIES"
115 PRINT
120 PRINT "PLACEZ VOTRE MAIN AU DESSUS DU RADAR" 130 CALL #8000
150 D=DEEK(#8100)
160 PRINT @8,8;"DISTANCE= ",D
170 GOTO 130

Le code assembleur contenu dans les lignes DATA est le suivant :

.ORG $8000

; PORTA en sortie, PORTC en entrée
LDA #$8B
STA $3FD
SEI

; envoie une impulsion sur le trigger (13µs) LDA #1
STA $3FA
LDA #0
LDA #0
LDA #0
LDA #0
LDA #0
STA $3FA
LDX #0
; attente du signal à l’état haut WHA
INX
BEQ CDST2 ; Timeout

LDA $3FC
AND #1
BEQ WHA

LDA #0
STA CMPT

STA CMPT+1
STA CMPT+2

; compte le temps
CDST
LDA CMPT
CLC
ADC #1
STA CMPT
LDA CMPT+1
ADC #0
STA CMPT+1
LDA CMPT+2
ADC #0
STA CMPT+2

; attente du signal à l'état bas CDST1
LDA $3FC
AND #1
BNE CDST
CDST2
CLI
RTS

.ORG $8100
CMPT
DB 0,0,0

Le programme commence par réserver la mémoire puis met en place le programme assembleur. Le programme principal situé à partir de la ligne 100 appelle le programme de mesure et affiche le résultat sur l’écran.
La mesure commence par l’envoi d’une impulsion sur la broche TRIG. Le programme attend ensuite que la sortie ECHO passe à ‘1’. Un compteur de timeout permet d’éviter de bloquer le programme si le module ne répond pas. Ensuite un compteur 24 bits compte le temps puis stocke le résultat en mémoire.
Les interruptions sont désactivées pendant la mesure afin de ne pas fausser le comptage. C’est le rôle des instructions SEI (interdit les interruptions) et CLI (autorise les interruptions) placées au début et à la fin du programme.

### Exercice 9 (LCD)

But : Piloter un afficheur LCD
Cet exercice présente la méthode pour contrôler un afficheur LCD (2 lignes de 16 caractères). L’afficheur est connecté au PORTA. Le PORTC permet de piloter les signaux de contrôle de l’afficheur. Une résistance de 100 ohms est placée en série avec l’alimentation du rétroéclairage (broches 15 et 16) et une résistance ajustable de 5 kilo-ohms assure le réglage du contraste.


### Réglage du contraste

A la mise sous tension, la ligne supérieure de l’afficheur doit être intégralement allumée tandis que la ligne inférieure doit être éteinte. Si rien n’est visible, il faut ajuster le contraste pour la faire apparaître en tournant la vis de réglage de la résistance variable. Après la séquence d’initialisation, cette ligne foncée disparaîtra et la luminosité sera homogène sur tout l’afficheur.

Figure 21: Contrôle d'un afficheur LCD

Les signaux de contrôle permettant de piloter l’afficheur sont : RS, R/W et E. Dans cette application, R/W est maintenu à 0 (écriture uniquement).
RS (PC0) permet de sélectionner le registre d’instructions (RS=0) ou le transfert des données vers l’affichage (RS=1).
E (PC1) est le signal d’activation. Les données envoyées sont validées par une impulsion sur cette broche.
Le programme est composé d’une partie en BASIC et d’une partie en assembleur s’occupant du transfert des commandes.

### 5 HIMEM #7FFF 10 CLS 20 PRINT "CONTROLE D'UN AFFICHEUR LCD" 30 GOSUB 1000

100 REM PROGRAMME PRINCIPAL
105 GOSUB 300
110 A$="BONJOUR LE MONDE"
120 B$="ORIC"
125 REM AFFICHAGE LIGNE1
130 POKE #8001,1
135 CALL #8000
140 T$=A$
150 GOSUB 200
155 REM AFFICHAGE LIGNE2
160 POKE #8001,192
165 CALL #8000
170 T$=B$
180 GOSUB 200
190 END

200 REM ENVOI D’UNE CHAINE DE CARACTERES 210 FOR I=1 TO LEN (T$)
220 POKE #8001,ASC(MID$(T$,I,1))
230 CALL #8023
240 NEXT I
250 RETURN

300 REM INIT AFFICHEUR
310 POKE #3FD,138
320 POKE #8001,56
330 CALL #8000
340 POKE #8001,12
350 CALL #8000
360 RETURN

1000 REM ROUTINES LM
1010 FOR I=#8000 TO #802D
1020 READ N
1030 POKE I,N
1040 NEXT I
1050 RETURN
1060 DATA 169,0,141,250,3,169,0,141,252,3,9,2,141,252,3,169,0,141,252,3 1070 DATA 162,255,234,234,202,208,251,162,255,234,234,202,208,251,96 1080 DATA 173,1,128,141,250,3,169,1,76,7,128

Le code assembleur contenu dans les lignes DATA est le suivant :

.ORG $8000

; Envoi d’une commande
Send_Com
LDA #0 ; valeur
STA $3FA
LDA #0

Continue
STA $3FA
ORA #2
STA $3FA
LDA #0
STA $3FA

LDX #$FF
Tempo
NOP
NOP
DEX
BNE Tempo

LDX #$FF
Tempo1
NOP
NOP
DEX
BNE Tempo1
RTS

; Envoi d’un caractère
Send_DATA | ; $8023
LDA $8001
STA $3FA
LDA #1
JMP Continue

Le programme principal commence à la ligne 100. Il permet d’afficher un message sur les 2 lignes de l’afficheur.
Le sous-programme placé à partir de la ligne 200 assure l’envoi caractère par caractère de la chaîne de caractères T$ par le biais de la routine Send_DATA.
Le sous-programme placé à partir de la ligne 300 assure l’initialisation de l’afficheur en le plaçant en mode 8 bits, 2 lignes, affichage ON à l’aide de la routine Send_COM.
Les lignes 130-135 permettent d’effacer l’écran tandis que les lignes 160-165 placent le curseur sur la 2ème ligne.

### Exercice 10 (SERVOMOTEUR)

But : Piloter un servomoteur
Cet exercice présente la méthode pour piloter un servomoteur en faisant varier sa position. La sortie 5V de la carte 24 E/S ne peut pas fournir assez de courant pour alimenter le servomoteur qui devra être alimenté en 5V par une source externe (chargeur USB par exemple).


Le servomoteur est un dispositif électromécanique dont l’axe de sortie peut prendre n’importe quelle position sur un demi cercle (soit une variation totale de 180°). La commande de la position du servomoteur se fait à l’aide d’une impulsion de durée calibrée répétée au rythme de 50 fois par seconde (20ms). La durée de l’impulsion va de 1ms à 2ms. 1ms correspond à un angle de 0° tandis que 2ms correspond à un angle de 180°. La variation est linéaire sur toute la plage d’utilisation.


La commande du servomoteur nécessite des impulsions courtes et précises à intervalle régulier. Le programme va donc utiliser les interruptions déclenchées toutes les 10ms par le VIA de l’Oric. Le vecteur d’interruption est situé dans la mémoire RAM aux adresses $245-246 pour l’ATMOS et $238-239 pour l’ORIC 1. Il sera détourné vers le programme de commande du servomoteur. Ainsi le programme sera exécuté en tâche de fond et le programme BASIC va simplement mettre à jour la

Figure 22: Commande d'un servomoteur

Figure 23: Commande d'un servomoteur analogique valeur de commande située à l’adresse #800D. Ce programme ne fonctionne que sur ORIC ATMOS. La version ORIC 1 est donnée sur la page suivante.

### 1 REM VERSION ORIC ATMOS 5 HIMEM #7FFF 10 CLS 15 GOSUB 1000 20 PRINT "CONTROLE D'UN SERVOMOTEUR" 30 POKE #3FD,139 40 CALL #8000

100 REM PROGRAMME PRINCIPAL
110 INPUT "VALEUR [0-255] :";V 120 POKE #800D,V
130 GOTO 110

1000 REM ROUTINES LM
1010 FOR I=#8000 TO #803A
1020 READ N
1030 POKE I,N
1040 NEXT I
1050 RETURN
1060 DATA 120,169,128,141,70,2,169,14,141,69,2,88,96,0,72,8,138,72,238 1070 DATA 58,128,173,58,128,41,1,240,18,169,1,141,250,3,162,100,202 1080 DATA 208,253,174,13,128,232, 202,234,208,252,169,0,141,250,3,104 1090 DATA 170,40,104,76,34,238,0

Le code assembleur contenu dans les lignes DATA est le suivant :

.ORG $8000

; Détourne les interruptions
Set_INT
SEI
LDA # NewINT/256
STA $246
LDA # NewINT%256
STA $245
CLI
RTS

VAL
.BYTE 0

NewINT
PHA
PHP
TXA
PHA

; Pour exécuter le pgm 1/2 INC FP
LDA FP
AND #1
BEQ FIN

; PA0 à 1 (début de l’impulsion)

LDA #1
STA $3FA
LDX #100 ; valeur#1ms
PTEMPO
DEX
BNE PTEMPO
LDX VAL | ; valeur angle
INX
TEMPO
NOP
DEX
BNE TEMPO

; PA0 à 0 (fin de l’impulsion) FIN
LDA #0
STA $3FA
PLA
TAX
PLP
PLA

; saut routine INT
JMP $EE22 | ; ATMOS
FP
.BYTE 0

La 1ère partie du programme assembleur détourne les interruptions vers la nouvelle routine permettant de générer l’impulsion de commande du servomoteur. Une fois en place, l’ORIC exécute cette routine à chaque appel d’interruption.
La routine commence par sauvegarder les différents registres A, P et X puis incrémente une variable FP. A chaque incrémentation, le bit 0 de FP change d’état, cela permet d’exécuter le programme générateur une fois sur deux, soit toutes les 20ms. La génération de l’impulsion commence par mettre à ‘1’ la sortie PA0. Ensuite une 1ère temporisation de 1ms assure la partie fixe de l’impulsion puis une 2ème temporisation prend en compte la valeur de consigne VAL pour augmenter la durée de l’impulsion jusqu’à 2ms. Enfin la sortie PA0 est remise à ‘0’ puis le programme continue avec la routine initiale de gestion des interruptions.
Remarque : Selon le modèle de servomoteur, il faut ajuster la plage de variation de la largeur de l’impulsion. Le programme est adapté à un servomoteur miniature de type SG90 (0.5 à 2ms).

### Version ORIC1

Pour l’Oric 1, le programme précédent doit être modifié car le vecteur d’interruption est différent. Ces modifications ne concernent que la partie assembleur du programme.
Le code assembleur pour la version ORIC1 est le suivant :

.ORG $8000

; Détourne les interruptions
Set_INT
SEI
LDA # NewINT/256
STA $22A
LDA # NewINT%256
STA $229
CLI
RTS

VAL
.byte 0

NewINT
PHA
PHP
TXA
PHA

; PA0 à 1 (début de l’impulsion) LDA #1
STA $3FA

LDX #197 ; valeur=1ms
PTEMPO
DEX
BNE PTEMPO
LDX VAL | ; valeur angle
INX
TEMPO
NOP
DEX
BNE TEMPO

; PA0 à 0 (fin de l’impulsion) LDA #0
STA $3FA

PLA
TAX
PLP
PLA

; saut routine INT
JMP $EC03 ; ORIC 1

Cela donne les lignes DATA suivantes :

### 1 REM VERSION ORIC 1

…..
1060 DATA 120,169,128,141,42,2,169,14,141,40,2,88,96,0,72,8,138,72,169,1 1070 DATA 141,250,3,162,197,202,208,253,174,13,128,232
1080 DATA 202,234,208,252,169,0,141,250,3,104,170,40,104,76,3,236

### Exercice 11 (MATRICE DE LEDS)

But : Piloter une matrice de leds
Cet exercice présente la méthode pour piloter une matrice de 8x8 leds équipée du circuit MAX7219. Ce module consomme beaucoup de courant, il faut donc faire appel à une source d’alimentation externe (un chargeur USB par exemple).


Figure 24: Contrôle d'une matrice de leds


Figure 25: Signaux de contrôle de la matrice

Le contrôle de l’affichage est assuré par un circuit spécialisé (MAX7219) qui communique à l’aide de 3 fils avec la carte d’E/S. Les chronogrammes de la Figure 25 montrent les signaux à utiliser. La communication se fait en série par blocs de 16 bits, le 1er octet désigne le registre destination tandis que le 2ème octet constitue la donnée.
Le but du programme est d’afficher ‘HELLO’ sur la matrice caractère par caractère. Chaque caractère va être codé puis stocké dans un tableau avant l’affichage.


Le codage de chaque caractère se fait à l’aide de 8 octets (8x8 bits=64 bits soit 64 leds).


Chaque octet contrôle une colonne, chaque bit de l’octet est affecté à une led. La Figure 27 indique le codage de la lettre ‘H’. Les valeurs nécessaires sont donc : 0,255,8,8,8,8,255,0. Il suffit de procéder de la même façon pour coder les autres caractères.
Le programme est composé d’une partie en BASIC et d’une partie en assembleur.

### 5 HIMEM #7FFF 10 DIM C(40) 20 CLS 30 GOSUB 1000 40 PRINT "CONTROLE D'UNE MATRICE 8x8" 50 POKE #3FD,137 60 GOSUB 400 70 GOSUB 300

100 REM PROGRAMME PRINCIPAL 105 K=0
110 FOR J=0 TO 7
115 POKE #8062+J,C(K)
116 K=K+1
120 NEXT J
130 CALL #8033
140 GOSUB 200
145 GOSUB 400
150 IF K<39 THEN 110
160 GOSUB 200
170 GOSUB 200
180 GOTO 105

Figure 26: Message à visualiser

Figure 27: Codage d'un caractère

200 REM TEMPORISATION
210 FOR I=1 TO 500
220 NEXT I
230 RETURN

300 REM INITIALISATION
310 POKE #8060,9: POKE #8061,0: CALL #8000 320 POKE #8060,12: POKE #8061,1: CALL #8000 330 POKE #8060,10: POKE #8061,8: CALL #8000 340 POKE #8060,11: POKE #8061,7: CALL #8000 350 RETURN

400 REM CLS
410 FOR I=0 TO 7
420 POKE #8062+I,0
430 NEXT I
440 CALL #8033
450 RETURN

1000 REM ROUTINES LM
1010 FOR I=#8000 TO #804A
1020 READ N
1030 POKE I,N
1040 NEXT I
1060 DATA 169,0,141,250,3,173,96,128,32,26,128,173,97,128,32,26,128 1070 DATA 169,1,141,250,3,140,250,3,96,162,8,160,0,10,144,1,200 1080 DATA 140,251,3,160,2,140,250,3,160,0,140,250,3,202,208,234 1090 DATA 96,162,1,142,96,128,189,97,128,141,97,128,138,72,32,0 1095 DATA 128,104,170,232,224,9,208,235,96

1100 REM CARACTERES
1110 FOR I=0 TO 39
1120 READ C(I)
1130 NEXT I
1140 DATA 0,255,8,8,8,8,255,0,0,255,137,137,137,137,129 1150 DATA 0,0,255,128,128,128,128,128,0,0,255,128,128,128 1160 DATA 128,128,0,0,126,129,129,129,129,126,0
1170 RETURN

Le programme commence par réserver la mémoire puis appelle le sous programme situé à partir de la ligne 1000 pour mettre en place les routines en assembleur puis remplir le tableau avec les différents caractères du message.
Le programme appelle ensuite un sous-programme (ligne 400) permettant de vider l’affichage (CLS). Enfin le sous-programme situé à partir de la ligne 300 configure les différents registres du circuit intégré d’affichage (MAX7219).
Le programme principal envoie ensuite les valeurs codant les caractères par bloc de 8 en faisant une pause puis efface brièvement l’affichage entre chaque caractère. Une fois la séquence terminée, le programme fait une pause un peu plus longue puis recommence l’affichage.

Le code assembleur contenu dans les lignes DATA est le suivant :

.ORG $8000

; Envoi d’une commande vers le MAX7219
Send_Com
LDA #0
STA $3FA
LDA REG
JSR Send8
LDA DATA
JSR Send8
LDA #1
STA $3FA
STY $3FA
RTS

; envoie 8 bits
Send8
LDX #8
SC1
LDY #0
ASL A
BCC SC2
INY
SC2
STY $3FB
LDY #2
STY $3FA
LDY #0
STY $3FA
DEX

BNE SC1
RTS

; Envoi d’un bloc de 8 octets [REG : 1-8] Send_Bloc
LDX #1
SB1
STX REG
LDA BLOC-1,X
STA DATA
TXA
PHA
JSR Send_Com
PLA
TAX
INX
CPX #9
BNE SB1
RTS

.ORG $8060
REG
.byte 0
DATA
.byte 0
BLOC
.byte 0,0,0,0,0,0,0,0

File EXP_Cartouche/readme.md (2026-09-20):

# Extension cartouche pour ORIC #

Cette extension ajoute un port cartouche à l'Oric.

Chargement de l'Aigle d'Or

Elle utilise des cartouches ROM de 128Ko à 1Mo qui se logent à la place de la ROM interne de l'Oric [$C000-$FFFF]. La mémoire de la cartouche est donc découpée en pages de 16Ko (8 à 64 pages).

Boîtier d'extension

* Tous les signaux du bus sont tamponnés afin d'éviter d'endommager l'Oric en cas de fausse manoeuvre. Un port d'extension placé à l'arrière du boîtier permet de brancher les extensions classiques. Toutefois, les contrôleurs de disques comme Microdisc, LOCI ou l'Erebus sont incompatibles car ils remplacent la ROM interne.
* Une prise JACK d'alimentation placée à l'arrière du boîtier permet d'alimenter tout le système à l'aide d'une source 5V (2A). Dans ce cas, il ne faut pas alimenter l'Oric.
* Enfin, un bouton RESET est placé sur le côté du boîtier.

Les cartouches peuvent recevoir des mémoires de 128K à 1M. la configuration se fait par 2 ponts de soudure. Elle sont équipées en option d'une mémoire EEPROM permettant de sauvegarder les parties pour les jeux d'aventure.

Cartouche

**Utilisation**

L'interface se branche simplement sur le bus d'extension de l'Oric.

*Attention*: Si le boîtier est alimenté (5V/2A), il ne faut pas alimenter l'Oric.

* Sans cartouche, l'Oric démarre normalement sur sa ROM interne.

* Avec une cartouche, la ROM interne de l'Oric est désactivée. Il démarre donc sur la ROM externe avec une version modifiée du BASIC. Au prompt, il suffit de taper START pour lancer le jeux ou le menu de sélection.

*Attention*: les cartouches se branchent et se débranchent ORIC éteint!

**Cartouches**

Pour l'instant, il y a 12 cartouches disponibles pour un total de 41 programmes.

Cartouches disponibles

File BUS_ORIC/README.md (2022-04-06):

# BUS_ORIC
Platine d'extension de bus pour l'ORIC
Cette platine se branche derrière l'ORIC avec une petite nappe et reprend le principe de la carte mère MX4 sur CPC.
Elle permet d'ajouter 4 slots d'extensions à la machine tout en proposant un report du bus à l'arrière pour brancher le contrôleur microdisc.

Platine d'extension Optional Title

Les extensions peuvent être alimentées à partir de l'alimentation de l'ORIC ou à partir d'une alimentation externe. Le choix se fait par un cavalier à 2 positions.
La platine possède un bouton RESET sur le côté.
Les extensions sont placées en page 3 et sont compatibles avec le contrôleur microdisc.
Les extensions à venir sont:

Synthèse vocale à MEA8000

Liaison Série ACIA

8 entrées analogiques

8 E/S numériques

16 E/S PIA

16 E/S VIA

Erebus

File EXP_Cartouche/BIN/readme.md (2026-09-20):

# Liste des cartouches #

- L'aigle d'Or
- Le secret du tombeau
- Le diamant de l’île maudite (*)
- Citadelle (*)
- Tyrann (*)
- Xenon (1, 2 et 3)
- Genius/Kikekankoi : Le manoir du Dr Genius, le retour du Dr Genius, le mystère de Kikekankoi (*)
- Compilation Loriciels : Super Jeep, Doggy, Star, Stanley, Flipper, 3D Munch, Sorvivor, 3D Fongus, Frelon
- Compilation 2 : Super meteors, styx, manic miner, ghost gobbler, acherons rage , zebbie, hopper, centipede, mushroom mania, ultra , le trésor de Tarakunda
- Tansoft : Ultima zone, Defence force, zebbie, welcome to oric, the hobbit, rat splat
- Egypte : Le diamant de Kheops,  , le masque d'or, anubis (*)
- Homebrew : Stormlord, oricium, impossible mission (*)

Les cartouches marquées (*) comportent une petite EEPROM permettant de sauvegarder l'avancée du jeu dans la cartouche pour le reprendre plus tard.

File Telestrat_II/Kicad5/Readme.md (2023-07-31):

# Platine principale

Platine principale Optional Title

# Platine connecteurs

Platine connecteurs Optional Title

# Front USB
Cette platine reprend les composants de l'afficheur du GOTEK et un connecteur USB du boitier. Il reste à ajouter 2 boutons 6x6x8mm.

Front USB Optional Title

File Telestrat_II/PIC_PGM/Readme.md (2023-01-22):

# Commande de l'alimentation

L'alimentation de la machine est obtenue à l'aide du bouton ON/OFF du boîtier. La commande est assurée par un relais piloté par un microcontroleur PIC 10F200.
Cela permet d'utiliser le même bouton pour produire le signal RESET.
* La mise sous tension se fait en appuyant sur le bouton.
* Une pression courte (>0.5s et <2s) produit un RESET.
* Une pression longue (>2s) éteint la machine.

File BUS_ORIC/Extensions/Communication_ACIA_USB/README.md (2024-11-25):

# Carte-ACIA_USB

Cette platine se branche sur la platine d'extension de bus et permet d'ajouter une liaison USB (émulation port série de 50 à 19200 bauds) à l'ORIC. 
Elle occupe les mêmes adresses que l'ACIA du telestrat soit 31C-31F

Platine d'extension Optional Title

# Programme de test

    10 POKE#31F,30:POKE#31E,11
    15 REM EMISSION
    20 A$="HELLO"
    30 FOR I=1 TO LEN(A$)
    40 IF (PEEK(#31D) AND 16)<>16 THEN 40
    50 POKE #31C,ASC(MID$(A$,I,1))
    60 NEXT
    70 REM RECEPTION
    80 IF (PEEK(#31D) AND 8)<>8 THEN 80
    90 PRINT CHR$(PEEK(#31C));
    100 GOTO 80

Ce programme s'utilise avec l'hyperterminal ou la console série Arduino. Les paramètres sont 9600 bauds, 8 bits, 1 bit de stop, pas de parité et sans contrôle de flux.
La partie Emission envoie le message "HELLO" vers le PC.
La partie Reception affiche les caractères envoyés par le PC sur l'écran de l'Oric.

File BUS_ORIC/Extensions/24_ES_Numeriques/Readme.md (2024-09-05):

# 24-E-S-Numeriques
Carte 24 E/S NUM pour ORIC

Cette platine se branche sur la platine d'extension de bus ou sur l'ORIC via une nappe 34 conducteurs et permet d'ajouter 24 entrées/sorties à l'ORIC.
Elle utilise un 82C55 doté de 3 ports de 8 bits.
Elle occupe les adresses 3FA à 3FD.

Platine d'extension Optional Title

__Exemple de programme:__

10 REM Place les PORTS A, B et C en sortie

15 POKE #3FD,128

20 REM envoi 85 sur le PORTA

25 POKE #3FA,85

Un document donne une dizaine d'exercices à faire avec cette carte.

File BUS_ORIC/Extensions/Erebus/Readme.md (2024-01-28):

# Erebus pour ORIC
__Carte EREBUS pour le bus Oric__

Cette platine se branche sur la platine d'extension de bus et permet d'ajouter l'Erebus à l'ORIC.
C'est la version pour Bus ORIC de l'interface conçue par kenneth pour lire des fichiers Tap directement depuis une carte SD.

Platine d'extension Optional Title

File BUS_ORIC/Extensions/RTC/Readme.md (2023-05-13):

# Horloge RTC-pour-ORIC
__Carte RTC pour l'oric__

Cette platine se branche sur la platine d'extension de bus et permet d'ajouter une horloge RTC à l'ORIC.
Elle donne les informations : Heures, Minutes et secondes ainsi que la date.
Elle occupe les adresses 360-371.

Platine d'extension Optional Title

__Utilisation:__

Les registres de l'horloge sont accessibles à l'aide des commandes PEEK et POKE.
Afin d'éviter un décalage lors de la lecture de l'heure, le circuit possède un LATCH qui fige les données lues à la lecture du registre des 1/100e de secondes (adresse 360). Les données contenues dans les autres registres ne changent pas jusqu'à la prochaine lecture de l'adresse 360. Bien entendu cela n'affecte pas l'horloge qui continue son comptage.

**Exemples de programmes**

```
5 REM Ecriture dans l'horloge (dimanche 19/03/2023 à 10h35)
6 REM Arret du comptage
10 POKE#371,4
15 REM Ecriture des valeurs
20 POKE#366,23
30 POKE#367,0
40 POKE#365,19
50 POKE#364,3
60 POKE#361,10
70 POKE#362,35
80 POKE#363,0
90 POKE#360,0
95 REM Reprise du comptage
100 POKE#371,12
```

```
5 REM lecture de l'horloge
6 REM permet de figer les valeurs
10 SC=PEEK(#360)
15 REM lecture des valeurs
20 H=PEEK(#361)
30 M=PEEK(#362)
40 S=PEEK(#363)
50 MO=PEEK(#364)
60 DA=PEEK(#365)
70 AN=PEEK(#366)
80 JO=PEEK(#367)
```

Le répertoire PGM contient des programmes permettant de modifier/lire l'horloge RTC (format tap, dsk et hfe).

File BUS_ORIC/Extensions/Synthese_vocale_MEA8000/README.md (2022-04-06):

# Carte-MEA8000

Cette carte permet d'ajouter la synthèse vocale à l'ORIC. Elle se branche sur la platine d'extension de bus.
La sortie audio se fait sur un jack car le son n'est pas mélangé avec le son de l'ORIC.
La carte est placée aux adresses 3FE-3FF. Elle est compatible avec le logiciel Synthoric et les programmes du livre "Paroles et micro".

Carte MEA8000 Optional Title

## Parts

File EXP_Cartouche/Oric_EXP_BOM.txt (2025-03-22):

Référence		valeur
C1		10µF	CMS 1206
C2,C3	100nF	céramique pas 5mm
R1		100R	CMS 0805
R2,R3	3.3k	CMS 0805
D1		1N4148
Q1		BC847	SOT23
U1,U2	74HCT541	CMS SOIC20W
U3		GAL20V8B	DIP24
U4		74HCT273	DIP20
U5		74HCT08		SOIC14
U6		74LVC1G125	SOT23-5
J1,J3	Connecteur IDC mâle 2x17 90° pas 2.54mm
J2		Connecteur pcb edge 36br pas 2.54mm
J4		Connecteur jack alimentation 2.1mm
SW1		Bouton tactile 90° 6x6x7mm (la tige dépasse de 3.5mm)
H5,H6	2 vis tôle 2.9x9.5mm
1x		Support CI 20br
1x 		Support CI 24br étroit

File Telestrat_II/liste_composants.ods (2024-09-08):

Platine principale
Référence | Qte | Valeur
BT1 | 1 | Support pile CR2032 Vertical + Pile CR2032
C1,C2,C32,C34 | 4 | Condensateur céramique 22pF pas 2.5mm
C11 | 1 | Condensateur électrochimique 2.2µF/25V pas 2.5mm
C15 | 1 | Condensateur 1µF pas 5mm
C23 C25 C26 C27 C28 | 5 | Condensateur électrochimique 100µF/16V pas 2.5mm
C3 C4 C5 C6 C7 C10 C12 C13 C14 C16 C17 C18 C19 C20 C21 C22 C29 C35 C36 | 19 | Condensateur 100nF pas 5mm
C24 C30 | 2 | Condensateur 47nF pas 5mm
C31 | 1 | Condensateur variable 50pF type TZ03F
C34 | 1 | Condensateur 2.2nF pas 5mm
C8 | 1 | Condensateur 10nF pas 5mm
C9 | 1 | Condensateur électrochimique 1000µF/10V pas 2.5mm
D10 | 1 | Diode 1N4007
D1 D2 D3 D4 D5 D6 D7 D8 D9 D11 D12 D13 | 12 | Diode 1N4148
F1 | 1 | Fusible Littelfuse 2A fusion lente (T)
Q1 Q2 Q3 Q4 | 4 | Transistor 2N3904 (TO92)
R13 R19 R29 | 3 | Résistance 1/8W 22kΩ
R15 | 1 | Résistance 1/8W 100 Ω
R16 R30 R32 R34 | 4 | Résistance 1/8W 4.7kΩ
R10 R12 R18 R20 R28 R36 | 6 | Résistance 1/8W 1kΩ
R2 R21 | 2 | Résistance 1/8W 3.3kΩ
R22 R23 R24 R25 | 4 | Résistance 1/8W 220Ω
R4 R5 R26 R27 R33 | 5 | Résistance 1/8W 10kΩ
R1 R3 R14 R17 R35 | 5 | Résistance 1/8W 2.2kΩ
R31 | 1 | Résistance 1/8W 100kΩ
R6 | 1 | Résistance 1/8W 1MΩ
R7 | 1 | Résistance 1/8W 470Ω
R8 R9 R11 | 3 | Résistance 1/8W 47kΩ
RN1 | 1 | Réseau de résistances 10kΩ (4R+C) 5 broches
RN2 | 1 | Réseau de résistances 22kΩ (7R+C) 8 broches
RN3 | 1 | Réseau de résistances 22kΩ (5R+C) 6 broches
RN4 RN5 | 2 | Réseau de résistances 4.7kΩ (4R+C) 5 broches
RN6 | 1 | Réseau de résistances 220Ω (4R+C) 5 broches
SW1 | 1 | Micro interrupteurs DIP 3 voies type piano
U1 U17 | 2 | 74HCT04 (DIP14)
U10 | 1 | EPM7032SLC (PLCC44)
U11 | 1 | AY3-8910A (DIP40)
U13 | 1 | PIC10F200 (DIP8)
U14 | 1 | HCS10017 (ULA ORIC DIP40)
U15 | 1 | 74LS365 (DIP16)
U16 | 1 | EPM7128SLC (PLCC84)
U18 | 1 | 27C040 (PLCC32)
U19 U20 | 2 | 74HCT257 (DIP16)
U21 | 1 | KM681000 (DIP32)
U22 | 1 | 74LS06 (DIP14)
U23 | 1 | LM358 (DIP8)
U24 U25 | 2 | 41464 (DIP18)
U26 | 1 | MB8877A (DIP40)
U27 | 1 | ICM7170 (DIP24)
U28 | 1 | FDC9216B (DIP8)
U3 | 1 | 6551 ou 65C51 (DIP24)
U4 | 1 | W65C816SxP (DIP40)
U5 | 1 | 74LS245 (DIP20)
U2 U6 | 2 | 6522 ou 65C22N (DIP40)
U7 | 1 | MCP130-450D (TO92)
U8 U12 | 2 | 74HCT541 (DIP20)
U9 | 1 | CH340G (SOIC16)
X1 | 1 | Oscillateur 12MHz (DIP14)
Y1 | 1 | Quartz 1.8432MHz HC49U
Y2 | 1 | Quartz horloger 32.768kHz
K1 | 1 | Relais 6V 1T 3A SRS 06VDC
K2 | 1 | Relais REED 5V 1T
J1 J2 J3 J4 | 0 | Point test de mesure (pastille sur la face composants)
J5 | 1 | Barrette femelle 2x7 broches pas 2.54mm
J6 | 1 | Connecteur USB type B
J7 | 1 | Barrette mâle 4 broches pas 2.54mm
J8 | 1 | Socle DIN Femelle 13 broches pour PCB
J9 | 1 | Connecteur IDC 2x10 broches mâle 90°coudé
J10 | 1 | Barrette femelle 2x12 broches pas 2.54mm
J11 | 1 | Barrette femelle 7 broches pas 2.54mm
J12 | 1 | DSUB E 9 broches mâle PCB
J13 | 1 | Jack alimentation 5.5x2.5mm ou 5.5x2.1mm
J14 | 1 | Socle DIN Femelle 13 broches pour PCB
J15 | 1 | Connecteur JST 2 broches mâle vertical pas 2.50mm ou 2 fils soudés
J16 | 1 | Connecteur IDC 2x17 broches mâle droit
H1 H2 | 2 | Entretoise femelle taraudée M3 13mm
H3 H4 | 2 | Entretoise femelle taraudée M3 17mm
 | 1 | Boîtier HTPC (Par exemple Tx01) | https://fr.aliexpress.com/item/4001114642510.html?curPageLogUid=dMOxQv7RKwR1
 | 1 | Alimentation 5V 3A 5.5x2.5mm (ou 5.5x2.1mm) + au centre
 | 1 | Lecteur GOTEK Firmware HxC ou FF
Platine connecteurs
Référence | Qte | Valeur
C1 | 1 | Condensateur 100nF pas 5mm
J13 | 1 | Barrette mâle 2x7 broches pas 2.54mm
J14 | 1 | Barrette mâle 7 broches pas 2.54mm
J15 | 1 | DSUB E 9 broches mâle PCB
J16 | 1 | Connecteur IDC 2x7 broches mâle 90°
SW1 | 1 | bouton tactile 6x6x5 coudé 90°
Platine Front_end
Référence | Qte | Valeur

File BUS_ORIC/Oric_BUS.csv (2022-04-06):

Reference | Value | Footprint | Datasheet
J1 | EXPANSION ORIC | Connector_IDC:IDC-Header_2x17_P2.54mm_Vertical | ~
J3 | SLOT2 | Connector_PinSocket_2.54mm:PinSocket_2x17_P2.54mm_Vertical | ~
J5 | REPORT BUS | Connector_IDC:IDC-Header_2x17_P2.54mm_Vertical | ~
H1 | MountingHole | MountingHole:MountingHole_3.2mm_M3 | ~
H2 | MountingHole | MountingHole:MountingHole_3.2mm_M3 | ~
H3 | MountingHole | MountingHole:MountingHole_3.2mm_M3 | ~
C1 | 47µF | Capacitor_THT:CP_Radial_D5.0mm_P2.00mm_Horizontal | ~
C2 | 47µF | Capacitor_THT:CP_Radial_D5.0mm_P2.00mm_Horizontal | ~
SW1 | SW_Push | Button_Switch_THT:SW_Tactile_SPST_Angled_PTS645Vx39-2LFS | ~
J6 | 5V | Connector_BarrelJack:BarrelJack_Horizontal | ~
JP1 | Jumper_3_Open | Connector_PinHeader_2.54mm:PinHeader_1x03_P2.54mm_Vertical | ~
H4 | MountingHole | MountingHole:MountingHole_3.2mm_M3 | ~
J2 | SLOT1 | Connector_PinSocket_2.54mm:PinSocket_2x17_P2.54mm_Vertical | ~
J4 | SLOT3 | Connector_PinSocket_2.54mm:PinSocket_2x17_P2.54mm_Vertical | ~
J7 | SLOT4 | Connector_PinSocket_2.54mm:PinSocket_2x17_P2.54mm_Vertical | ~
C3 | 47µF | Capacitor_THT:CP_Radial_D5.0mm_P2.00mm_Horizontal | ~
C4 | 47µF | Capacitor_THT:CP_Radial_D5.0mm_P2.00mm_Horizontal | ~

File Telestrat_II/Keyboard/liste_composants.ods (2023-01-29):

Platine clavier
Référence | Qte | Valeur
U1 | 1 | CD 4051 (DIP16)
SW1-SW60 | 58 ou 59 | Touches clavier type CHERRY ou GATERON rouge
H7..H10 | 2 | Collier de frettage 2mm
 | 1m | Câble blindé 14 conducteurs
 | 1 | Fiche DIN 13 broches mâle
 | 1 | Boîtier imprimé en 3D (4 pièces)
Vis tôle 2,9x6,5mm tête bombée | 4 | Fixation des pieds sur le boîtier
Vis tôle 2,9x9,5mm tête fraisée | 4 | Fixation des 2 parties du clavier
Vis tôle 2,2x9,5mm tête fraisée | 2 | Fixation des 2 parties du clavier

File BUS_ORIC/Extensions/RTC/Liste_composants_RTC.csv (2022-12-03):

Reference | Quantity | Value | Footprint | Datasheet
BT1 | 1 | CR1220 | Battery:BatteryHolder_BC501SM | ~
C1 | 1 | 47µF | Capacitor_THT:CP_Radial_D5.0mm_P2.00mm | ~
C2 | 1 | 100nF | Capacitor_THT:C_Rect_L7.0mm_W2.5mm_P5.00mm | ~
C3 C6 | 2 | 22pF | Capacitor_THT:C_Disc_D4.3mm_W1.9mm_P5.00mm | ~
C5 | 1 | 50pF | Capacitor_THT:Trimmer_Cap_TZ03F | ~
D1 | 1 | 1N4148 | Diode_THT:D_DO-35_SOD27_P7.62mm_Horizontal | https://assets.nexperia.com/documents/data-sheet/1N4148_1N4448.pdf
J1 | 1 | SLOT1 | Connector_IDC:IDC-Header_2x17_P2.54mm_Horizontal | ~
JP1 | 1 | IRQ_RTC | Connector_PinHeader_2.54mm:PinHeader_1x02_P2.54mm_Vertical | ~
R1 | 1 | 2.2k | Resistor_THT:R_Axial_DIN0204_L3.6mm_D1.6mm_P7.62mm_Horizontal | ~
RN1 | 1 | 10K | Resistor_THT:R_Array_SIP5 | http://www.vishay.com/docs/31509/csc.pdf
RN2 | 1 | 22k | Resistor_THT:R_Array_SIP9 | http://www.vishay.com/docs/31509/csc.pdf
U1 | 1 | ICM7170 | Package_DIP:DIP-24_W15.24mm_LongPads
U2 | 1 | GAL16V8 | Package_DIP:DIP-20_W7.62mm_LongPads
Y1 | 1 | 32.768kHz | Crystal:Crystal_AT310_D3.0mm_L10.0mm_Horizontal_1EP_style2 | ~

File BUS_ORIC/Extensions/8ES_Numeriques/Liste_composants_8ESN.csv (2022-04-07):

Reference | Value | Footprint | Datasheet
C1 | 47µF | Capacitor_THT:CP_Radial_D5.0mm_P2.00mm | ~
J1 | SLOT1 | Connector_IDC:IDC-Header_2x17_P2.54mm_Horizontal | ~
D1 | 1N4148 | Diode_THT:D_DO-35_SOD27_P7.62mm_Horizontal | ~
J2 | E/S | Connector_PinHeader_2.54mm:PinHeader_1x10_P2.54mm_Horizontal | ~
U4 | 74LS374 | Package_DIP:DIP-20_W7.62mm_LongPads | http://www.ti.com/lit/gpn/sn74LS374
U5 | 74LS244 | Package_DIP:DIP-20_W7.62mm_LongPads | http://www.ti.com/lit/ds/symlink/sn74ls244.pdf
U6 | ULN2803A | Package_DIP:DIP-18_W7.62mm_LongPads | http://www.ti.com/lit/ds/symlink/uln2803a.pdf
D2 | Q0 | LED_SMD:LED_0805_2012Metric | ~
D3 | Q1 | LED_SMD:LED_0805_2012Metric | ~
D4 | Q2 | LED_SMD:LED_0805_2012Metric | ~
D5 | Q3 | LED_SMD:LED_0805_2012Metric | ~
D6 | Q4 | LED_SMD:LED_0805_2012Metric | ~
D7 | Q5 | LED_SMD:LED_0805_2012Metric | ~
D8 | Q6 | LED_SMD:LED_0805_2012Metric | ~
D9 | Q7 | LED_SMD:LED_0805_2012Metric | ~
D10 | D0 | LED_SMD:LED_0805_2012Metric | ~
RN1 | 1K | Resistor_THT:R_Array_SIP9 | http://www.vishay.com/docs/31509/csc.pdf
D11 | D1 | LED_SMD:LED_0805_2012Metric | ~
D12 | D2 | LED_SMD:LED_0805_2012Metric | ~
D13 | D3 | LED_SMD:LED_0805_2012Metric | ~
D14 | D4 | LED_SMD:LED_0805_2012Metric | ~
D15 | D5 | LED_SMD:LED_0805_2012Metric | ~
D16 | D6 | LED_SMD:LED_0805_2012Metric | ~
D17 | D7 | LED_SMD:LED_0805_2012Metric | ~
R1 | 1K | Resistor_THT:R_Axial_DIN0204_L3.6mm_D1.6mm_P2.54mm_Vertical | ~
R2 | 1K | Resistor_THT:R_Axial_DIN0204_L3.6mm_D1.6mm_P2.54mm_Vertical | ~
R3 | 1K | Resistor_THT:R_Axial_DIN0204_L3.6mm_D1.6mm_P2.54mm_Vertical | ~
R4 | 1K | Resistor_THT:R_Axial_DIN0204_L3.6mm_D1.6mm_P2.54mm_Vertical | ~
R5 | 1K | Resistor_THT:R_Axial_DIN0204_L3.6mm_D1.6mm_P2.54mm_Vertical | ~
R6 | 1K | Resistor_THT:R_Axial_DIN0204_L3.6mm_D1.6mm_P2.54mm_Vertical | ~
R7 | 1K | Resistor_THT:R_Axial_DIN0204_L3.6mm_D1.6mm_P2.54mm_Vertical | ~
R8 | 1K | Resistor_THT:R_Axial_DIN0204_L3.6mm_D1.6mm_P2.54mm_Vertical | ~
J3 | E/S | Connector_PinHeader_2.54mm:PinHeader_1x10_P2.54mm_Horizontal | ~
U1 | GAL16V8 | Package_DIP:DIP-20_W7.62mm_LongPads
SW1 | 3FA/3FB | Button_Switch_THT:SW_DIP_SPSTx01_Slide_6.7x4.1mm_W7.62mm_P2.54mm_LowProfile | ~
R9 | 1K | Resistor_THT:R_Axial_DIN0204_L3.6mm_D1.6mm_P7.62mm_Horizontal | ~
RN2 | 1K | Resistor_THT:R_Array_SIP9 | http://www.vishay.com/docs/31509/csc.pdf

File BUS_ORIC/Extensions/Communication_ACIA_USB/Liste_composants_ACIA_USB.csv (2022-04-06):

Reference | Value | Footprint | Datasheet
C1 | 47µF | Capacitor_THT:CP_Radial_D5.0mm_P2.00mm | ~
U3 | 74LS30 | Package_DIP:DIP-14_W7.62mm_LongPads | http://www.ti.com/lit/gpn/sn74LS30
C3 | 100nF | Capacitor_THT:C_Rect_L7.0mm_W2.0mm_P5.00mm | ~
C2 | 100nF | Capacitor_THT:C_Rect_L7.0mm_W2.0mm_P5.00mm | ~
J1 | SLOT1 | Connector_IDC:IDC-Header_2x17_P2.54mm_Horizontal | ~
U2 | 74LS04 | Package_DIP:DIP-14_W7.62mm_LongPads | http://www.ti.com/lit/gpn/sn74LS04
D1 | 1N4148 | Diode_THT:D_DO-35_SOD27_P7.62mm_Horizontal | ~
U1 | 65C51 | Package_DIP:DIP-28_W15.24mm_LongPads | http://www.6502.org/documents/datasheets/mos/mos_6551_acia.pdf
C5 | 100nF | Capacitor_SMD:C_0805_2012Metric | ~
C8 | 22pF | Capacitor_THT:C_Disc_D3.4mm_W2.1mm_P2.50mm | ~
Y1 | 1.8432MHz | Crystal:Crystal_HC49-U_Horizontal | ~
R1 | 1M | Resistor_THT:R_Axial_DIN0207_L6.3mm_D2.5mm_P10.16mm_Horizontal | ~
U4 | CH340G | Package_SO:SOIC-16_3.9x9.9mm_P1.27mm | http://www.datasheet5.com/pdf-local-2195953
J2 | USB_B | Connector_USB:USB_B_Lumberg_2411_02_Horizontal | ~
Y2 | 12MHz | Crystal:Crystal_HC49-U_Vertical | ~
C4 | 22pF | Capacitor_THT:C_Disc_D3.8mm_W2.6mm_P2.50mm | ~
C6 | 22pF | Capacitor_THT:C_Disc_D3.8mm_W2.6mm_P2.50mm | ~
C7 | 100nF | Capacitor_THT:C_Rect_L7.0mm_W2.5mm_P5.00mm | ~

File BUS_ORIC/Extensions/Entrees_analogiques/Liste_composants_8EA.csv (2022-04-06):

Reference | Value | Footprint | Datasheet
C1 | 47µF | Capacitor_THT:CP_Radial_D5.0mm_P2.00mm | ~
C4 | 47nF | Capacitor_THT:C_Rect_L7.0mm_W2.0mm_P5.00mm | ~
R1 | 10 | Resistor_THT:R_Axial_DIN0207_L6.3mm_D2.5mm_P10.16mm_Horizontal | ~
U3 | 74LS30 | Package_DIP:DIP-14_W7.62mm_LongPads | http://www.ti.com/lit/gpn/sn74LS30
C2 | 100nF | Capacitor_THT:C_Rect_L7.0mm_W2.0mm_P5.00mm | ~
J1 | SLOT1 | Connector_IDC:IDC-Header_2x17_P2.54mm_Horizontal | ~
U2 | 74LS04 | Package_DIP:DIP-14_W7.62mm_LongPads | http://www.ti.com/lit/gpn/sn74LS04
D1 | 1N4148 | Diode_THT:D_DO-35_SOD27_P7.62mm_Horizontal | ~
U4 | ADC0809 | Package_DIP:DIP-28_W15.24mm_LongPads
U1 | 74LS32 | Package_DIP:DIP-14_W7.62mm_LongPads | http://www.ti.com/lit/gpn/sn74LS32
R2 | 1k | Resistor_THT:R_Axial_DIN0207_L6.3mm_D2.5mm_P10.16mm_Horizontal | ~
C5 | 1nF | Capacitor_THT:C_Rect_L7.0mm_W2.0mm_P5.00mm | ~
R3 | 1k | Resistor_THT:R_Axial_DIN0207_L6.3mm_D2.5mm_P10.16mm_Horizontal | ~
C6 | 1nF | Capacitor_THT:C_Rect_L7.0mm_W2.0mm_P5.00mm | ~
R4 | 1k | Resistor_THT:R_Axial_DIN0207_L6.3mm_D2.5mm_P10.16mm_Horizontal | ~
C7 | 1nF | Capacitor_THT:C_Rect_L7.0mm_W2.0mm_P5.00mm | ~
R5 | 1k | Resistor_THT:R_Axial_DIN0207_L6.3mm_D2.5mm_P10.16mm_Horizontal | ~
C8 | 1nF | Capacitor_THT:C_Rect_L7.0mm_W2.0mm_P5.00mm | ~
R6 | 1k | Resistor_THT:R_Axial_DIN0207_L6.3mm_D2.5mm_P10.16mm_Horizontal | ~
C9 | 1nF | Capacitor_THT:C_Rect_L7.0mm_W2.0mm_P5.00mm | ~
R7 | 1k | Resistor_THT:R_Axial_DIN0207_L6.3mm_D2.5mm_P10.16mm_Horizontal | ~
C10 | 1nF | Capacitor_THT:C_Rect_L7.0mm_W2.0mm_P5.00mm | ~
R8 | 1k | Resistor_THT:R_Axial_DIN0207_L6.3mm_D2.5mm_P10.16mm_Horizontal | ~
C11 | 1nF | Capacitor_THT:C_Rect_L7.0mm_W2.0mm_P5.00mm | ~
R9 | 1k | Resistor_THT:R_Axial_DIN0207_L6.3mm_D2.5mm_P10.16mm_Horizontal | ~
C12 | 1nF | Capacitor_THT:C_Rect_L7.0mm_W2.0mm_P5.00mm | ~
J2 | E/S | Connector_PinHeader_2.54mm:PinHeader_1x10_P2.54mm_Horizontal | ~
R10 | 2.2k | Resistor_THT:R_Axial_DIN0207_L6.3mm_D2.5mm_P10.16mm_Horizontal | ~
C13 | 330pF | Capacitor_THT:C_Disc_D3.4mm_W2.1mm_P2.50mm | ~
JP1 | Addr | Connector_PinHeader_2.54mm:PinHeader_1x03_P2.54mm_Vertical | ~

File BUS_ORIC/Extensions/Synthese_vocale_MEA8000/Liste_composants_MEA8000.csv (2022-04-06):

Reference | Value | Footprint | Datasheet
C7 | 47µF | Capacitor_THT:CP_Radial_D5.0mm_P2.00mm | ~
R3 | 470 | Resistor_THT:R_Axial_DIN0207_L6.3mm_D2.5mm_P10.16mm_Horizontal | ~
C4 | 10nF | Capacitor_THT:C_Rect_L7.0mm_W2.0mm_P5.00mm | ~
R5 | 47 | Resistor_THT:R_Axial_DIN0207_L6.3mm_D2.5mm_P10.16mm_Horizontal | ~
R2 | 22k | Resistor_THT:R_Axial_DIN0207_L6.3mm_D2.5mm_P10.16mm_Horizontal | ~
C5 | 22nF | Capacitor_THT:C_Rect_L7.0mm_W2.0mm_P5.00mm | ~
R4 | 1.5k | Resistor_THT:R_Axial_DIN0207_L6.3mm_D2.5mm_P10.16mm_Horizontal | ~
R6 | 470 | Resistor_THT:R_Axial_DIN0207_L6.3mm_D2.5mm_P10.16mm_Horizontal | ~
C6 | 100nF | Capacitor_THT:C_Rect_L7.0mm_W2.0mm_P5.00mm | ~
R7 | 10k | Resistor_THT:R_Axial_DIN0207_L6.3mm_D2.5mm_P10.16mm_Horizontal | ~
R8 | 10k | Resistor_THT:R_Axial_DIN0207_L6.3mm_D2.5mm_P10.16mm_Horizontal | ~
C9 | 22nF | Capacitor_THT:C_Rect_L7.0mm_W2.0mm_P5.00mm | ~
C8 | 47µF | Capacitor_THT:CP_Radial_D5.0mm_P2.00mm | ~
U2 | 74LS30 | Package_DIP:DIP-14_W7.62mm_LongPads | http://www.ti.com/lit/gpn/sn74LS30
U3 | MEA8000 | Package_DIP:DIP-24_W15.24mm_LongPads
Q1 | P2N2907 | Package_TO_SOT_THT:TO-92 | ~
C2 | 100nF | Capacitor_THT:C_Rect_L7.0mm_W2.0mm_P5.00mm | ~
C1 | 100nF | Capacitor_THT:C_Rect_L7.0mm_W2.0mm_P5.00mm | ~
J2 | AUDIO | Connector_Audio:Jack_3.5mm_PJ-307_Horizontal | ~
J1 | SLOT1 | Connector_IDC:IDC-Header_2x17_P2.54mm_Horizontal | ~
U1 | 74LS04 | Package_DIP:DIP-14_W7.62mm_LongPads | http://www.ti.com/lit/gpn/sn74LS04
D1 | 1N4148 | Diode_THT:D_DO-35_SOD27_P7.62mm_Horizontal | ~
Y1 | 4MHz | Crystal:Crystal_HC49-U_Vertical | ~
R1 | 1M | Resistor_THT:R_Axial_DIN0207_L6.3mm_D2.5mm_P10.16mm_Horizontal | ~
C3 | 47pF | Capacitor_THT:C_Rect_L7.0mm_W2.0mm_P5.00mm | ~

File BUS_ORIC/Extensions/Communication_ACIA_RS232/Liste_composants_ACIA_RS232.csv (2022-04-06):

Reference | Value | Footprint | Datasheet
C1 | 47µF | Capacitor_THT:CP_Radial_D5.0mm_P2.00mm | ~
U3 | 74LS30 | Package_DIP:DIP-14_W7.62mm_LongPads | http://www.ti.com/lit/gpn/sn74LS30
C3 | 100nF | Capacitor_THT:C_Rect_L7.0mm_W2.0mm_P5.00mm | ~
C2 | 100nF | Capacitor_THT:C_Rect_L7.0mm_W2.0mm_P5.00mm | ~
J1 | SLOT1 | Connector_IDC:IDC-Header_2x17_P2.54mm_Horizontal | ~
U2 | 74LS04 | Package_DIP:DIP-14_W7.62mm_LongPads | http://www.ti.com/lit/gpn/sn74LS04
D1 | 1N4148 | Diode_THT:D_DO-35_SOD27_P7.62mm_Horizontal | ~
U1 | 6551 | Package_DIP:DIP-28_W15.24mm_LongPads | http://www.6502.org/documents/datasheets/mos/mos_6551_acia.pdf
U4 | MAX232 | Package_DIP:DIP-16_W7.62mm_LongPads | http://www.ti.com/lit/ds/symlink/max232.pdf
C4 | 1µF | Capacitor_THT:CP_Radial_D5.0mm_P2.00mm | ~
C5 | 1µF | Capacitor_THT:CP_Radial_D5.0mm_P2.00mm | ~
C6 | 1µF | Capacitor_THT:CP_Radial_D5.0mm_P2.00mm | ~
C7 | 1µF | Capacitor_THT:CP_Radial_D5.0mm_P2.00mm | ~
J2 | RS232 | Connector_Dsub:DSUB-9_Male_Horizontal_P2.77x2.84mm | ~
C8 | 22pF | Capacitor_THT:C_Disc_D3.4mm_W2.1mm_P2.50mm | ~
Y1 | 1.8432MHz | Crystal:Crystal_HC49-U_Horizontal | ~
R1 | 1M | Resistor_THT:R_Axial_DIN0207_L6.3mm_D2.5mm_P10.16mm_Horizontal | ~

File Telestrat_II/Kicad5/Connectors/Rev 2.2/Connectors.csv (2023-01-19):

Reference | Quantity | Value | Footprint | Datasheet
C1 | 1 | 100nF | Capacitor_THT:C_Disc_D5.0mm_W2.5mm_P5.00mm | ~
H1 H2 | 2 | EXT | MountingHole:MountingHole_3.2mm_M3_DIN965_Pad | ~
J13 | 1 | MIDI/MODEM | Connector_PinHeader_2.54mm:PinHeader_2x07_P2.54mm_Vertical | ~
J14 | 1 | PAD_LEFT | Connector_PinHeader_2.54mm:PinHeader_1x07_P2.54mm_Vertical | ~
J15 | 1 | PAD_LEFT | Connector_Dsub:DSUB-9_Male_Horizontal_P2.77x2.84mm_EdgePinOffset8mm_Housed_MountingHolesOffset9.2mm | ~
J16 | 1 | MIDI/MODEM | Connector_IDC:IDC-Header_2x07_P2.54mm_Horizontal | ~
SW1 | 1 | NMI | Button_Switch_THT:SW_Tactile_SPST_Angled_PTS645Vx58-2LFS | ~

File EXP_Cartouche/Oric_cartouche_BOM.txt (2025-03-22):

Référence		valeur
C1		1µF		CMS 1206
R1,R2	10k		CMS 0805
U1		W27C010, W27C020,W27C040,27C080 (EPROM ou EEPROM 128Kx8 à 1Mx8)
U2		AT24C64	SOIC8
1x 		Support CI DIP 32br large

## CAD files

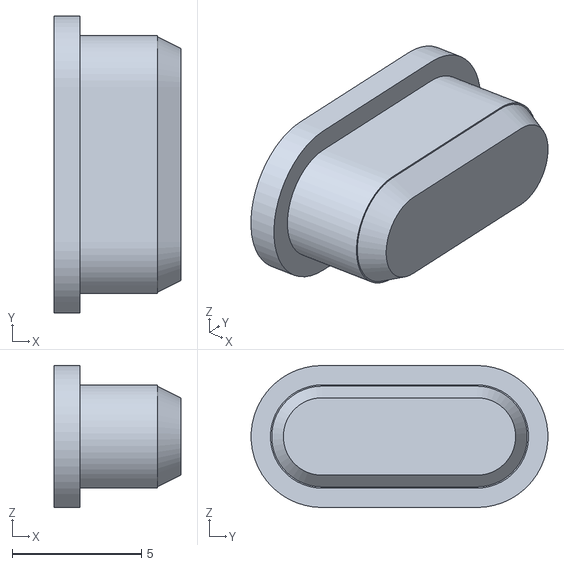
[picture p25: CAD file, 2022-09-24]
BUS_ORIC/3D/bp.stl
4.90 x 11.5 x 5.50

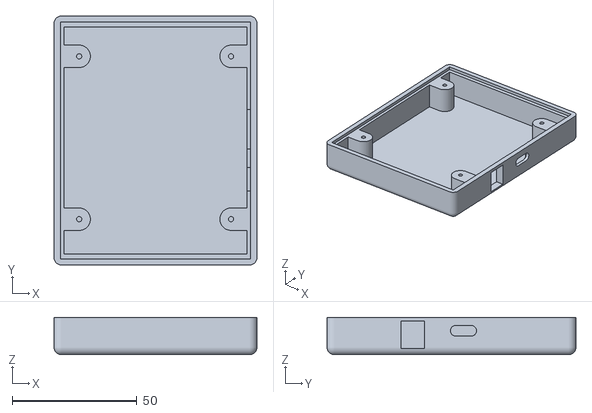
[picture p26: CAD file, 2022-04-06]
BUS_ORIC/Platine_bus.stl
81.5 x 100.0 x 15.0

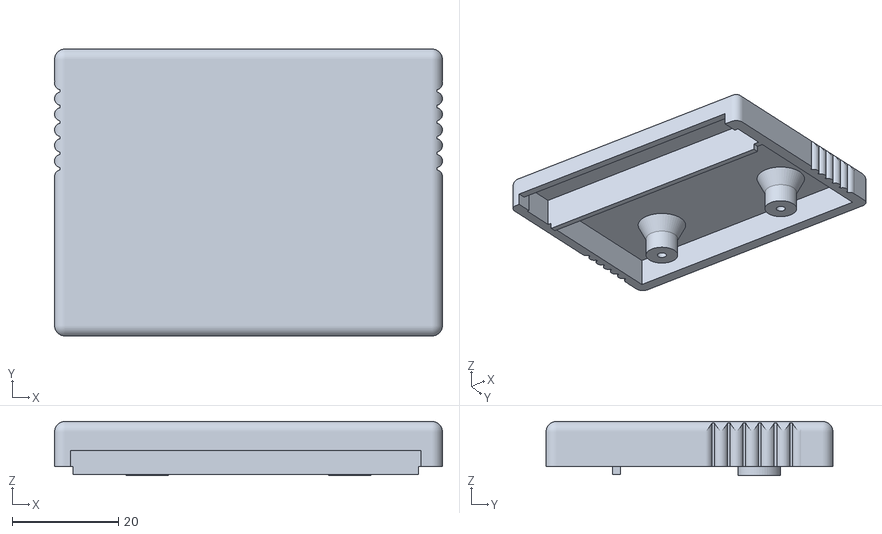
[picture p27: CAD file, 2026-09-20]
EXP_Cartouche/3D/Cartouche_ORIC2M_sup.stl
73.0 x 54.0 x 10.2

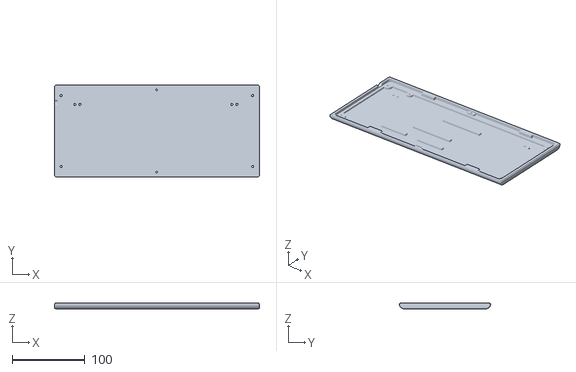
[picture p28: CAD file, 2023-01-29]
Telestrat_II/Keyboard/3D/clavier_inf_nopads.stl
282.0 x 126.0 x 8.00

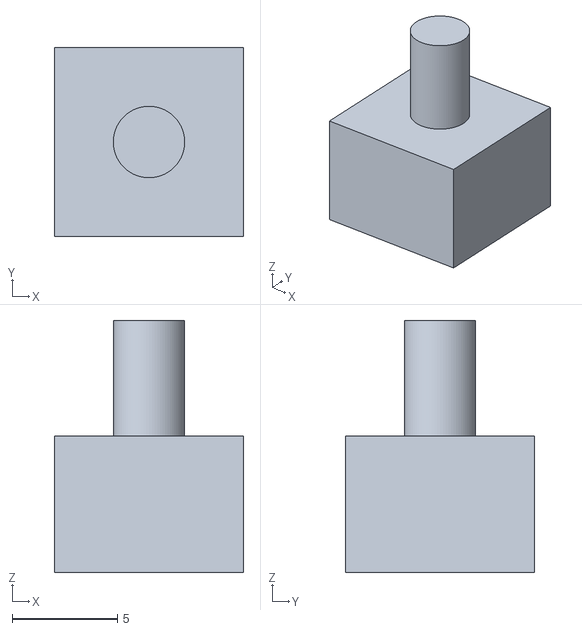
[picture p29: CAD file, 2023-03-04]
Telestrat_II/Kicad5/Front_USB/3D/Bouton.stl
9.00 x 9.00 x 12.0

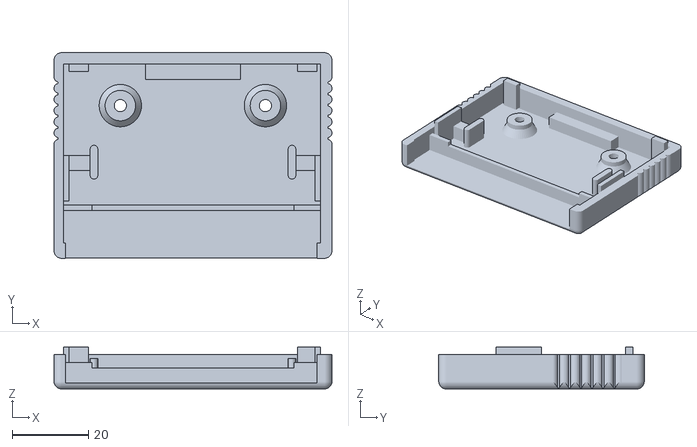
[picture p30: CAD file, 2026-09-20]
EXP_Cartouche/3D/Cartouche_ORIC_inf.stl
73.0 x 54.0 x 11.0

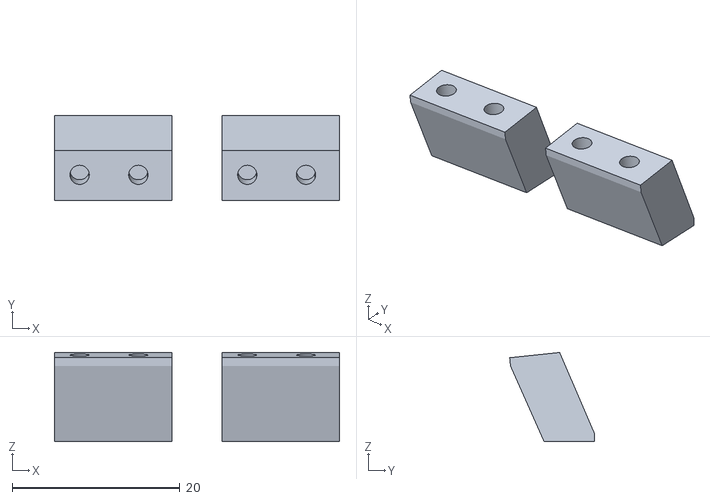
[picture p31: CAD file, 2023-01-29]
Telestrat_II/Keyboard/3D/clavier_pieds.stl
34.0 x 10.1 x 10.6

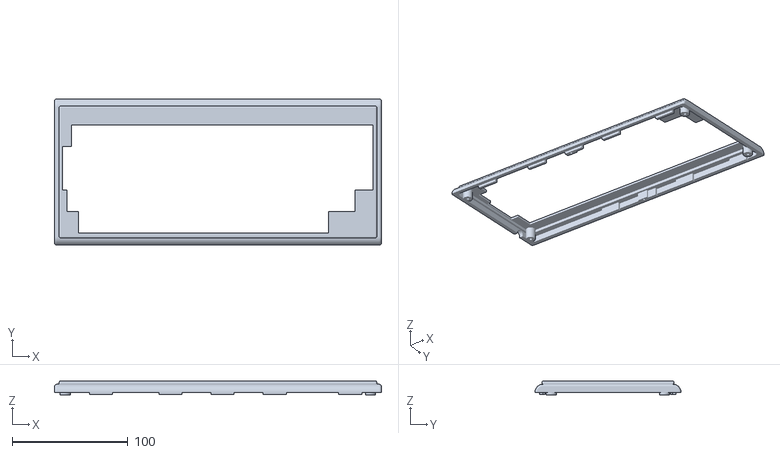
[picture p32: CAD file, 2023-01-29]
Telestrat_II/Keyboard/3D/clavier_sup.stl
282.0 x 126.0 x 12.5

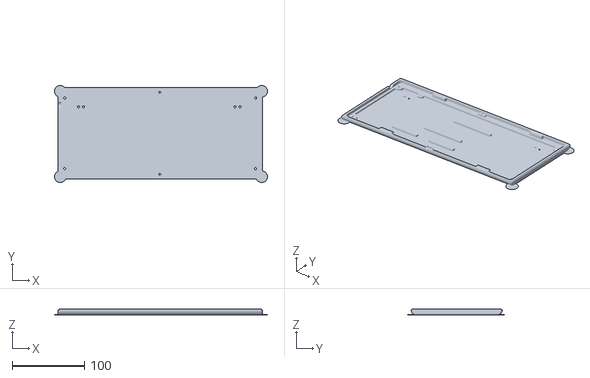
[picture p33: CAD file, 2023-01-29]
Telestrat_II/Keyboard/3D/clavier_inf_pads.stl
294.0 x 134.0 x 8.00

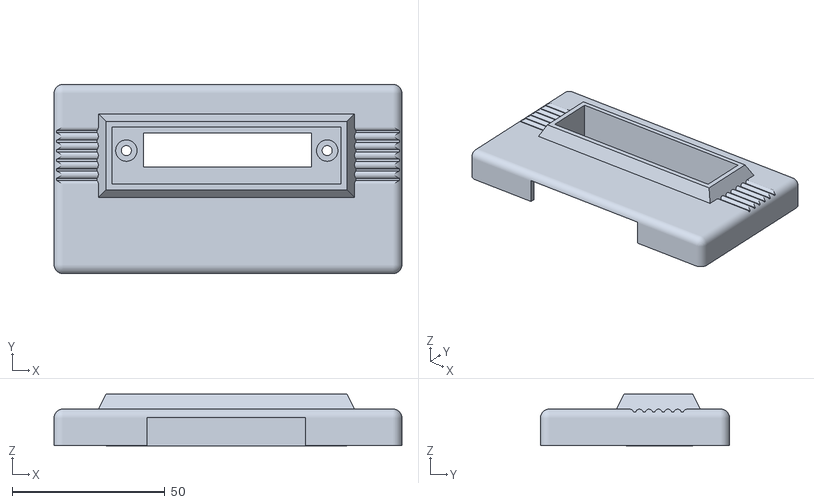
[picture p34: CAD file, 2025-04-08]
EXP_Cartouche/3D/Oric_EXP_sup.stl
114.0 x 62.0 x 17.0

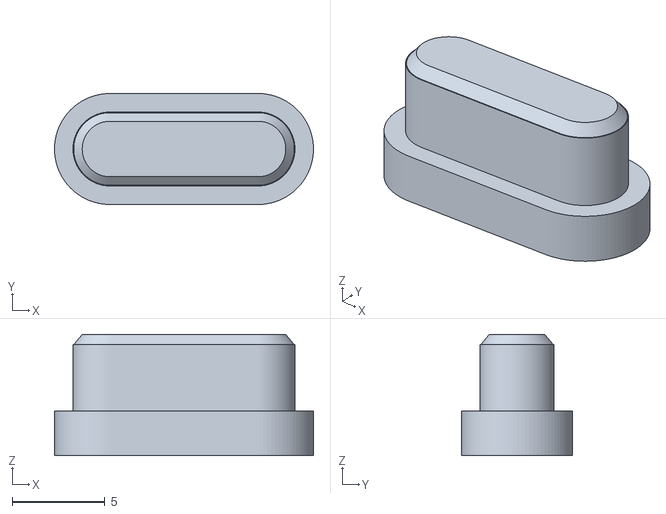
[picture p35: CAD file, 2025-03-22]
EXP_Cartouche/3D/BP.stl
14.0 x 6.00 x 6.55

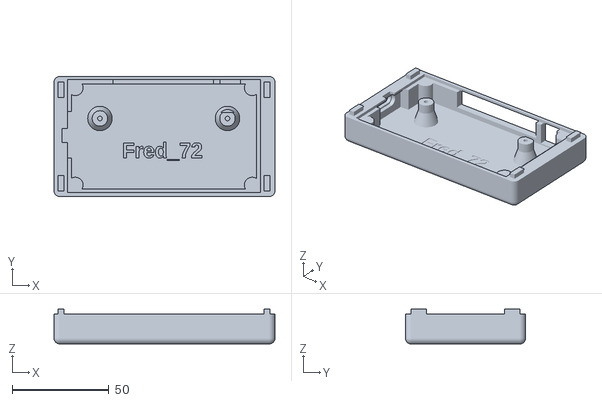
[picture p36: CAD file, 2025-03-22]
EXP_Cartouche/3D/Oric_EXP_inf.stl
114.0 x 62.0 x 18.0

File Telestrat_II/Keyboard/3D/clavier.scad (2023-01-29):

$fn=80;


plot_imp=true;

*color ("cyan") rotate ([6,0,0])translate ([4,9,4])  pcb();
*color ("red") rotate ([6,0,0])coque_inf();
*color ("grey") rotate ([6,0,0])translate ([0,0,9])  coque_sup();

*translate ([25,100,0])  color ("red") pied();
*translate ([240,100,0]) color ("red") pied();



// Pour l'impression
coque_inf();
*translate ([0,0,9]) coque_sup();
*translate ([4,9,4])  pcb();
*translate ([0,0,0]) pied();
*translate ([20,0,0]) pied();

module pied()
{
    difference()
    {
    hull()
    {
  translate ([0,-4,9]) rotate ([6,0,0]) cube ([14,6,1]);  
  cube ([14,6,1]);  
    }
    
     translate ([3,-0.5,5]) rotate ([6,0,0]) cylinder (d=2.3,h=10);
    
     translate ([10,-0.5,5]) rotate ([6,0,0]) cylinder (d=2.3,h=10);
}
}



module coque_sup()
{
    difference()
    {
    union()
    {
difference()
    {
  union()
        {translate ([0,0,6]) mirror ([0,0,1]) box1 (282,126,7,14,2);   
         translate ([4,6,9]) mirror ([0,0,-1]) box (274,114,3,1.5);
            
      }
  translate ([4,4.2,-6.5]) plaque(273.6,117,11,4);
  translate ([6,11,-4]) plaque(269.6,103.8,11,6);
        
  translate ([20.5,10.5,0]) cube ([216,20,20]); 
  translate ([10.7,29,0]) cube ([248.5,20,20]);       
  translate ([6.7,47.6,0]) cube ([268,20,20]);       
  translate ([6.7,66,0]) cube ([268,19,20]);   
  translate ([14.7,84.4,0]) cube ([259.95,19,20]);  
    
      
   
  // passage câble
   translate ([-5,102,0]) rotate ([0,90,0]) cylinder (d=8,h=15);
      
    }
  translate ([9.1,14.1,-3.5]) plot();
  translate ([9.1,112.8-1.1,-3.5]) plot();
  translate ([273.6-1.1,14.1,-3.5]) plot();
  translate ([273.6-1.1,112.8-1.1,-3.5]) plot();  

  
  translate ([30,4,-3]) cube ([20,3,8]);   
  translate ([90,4,-3]) cube ([20,3,8]);  
  translate ([135,4,-3]) cube ([20,3,8]);  
  translate ([180,4,-3]) cube ([20,3,8]);  
  translate ([245,4,-3]) cube ([20,3,8]);  

  translate ([135,4,-3]) cube ([11,4.6,8]);
  translate ([135,117,-3]) cube ([11,4.6,8]);
    
  translate ([90,118.6,-3]) cube ([20,3,8]);  
  translate ([135,118.6,-3]) cube ([20,3,8]);  
  translate ([180,118.6,-3]) cube ([20,3,8]);  
  translate ([245,118.6,-3]) cube ([20,3,8]);   
    }  
    
    translate ([140.5,6.5,-3.5]) cylinder (d=1.8,h=7); 
    translate ([140.5,119.5,-3.5]) cylinder (d=1.8,h=7);  
}
}


module plot()
{
   difference()
   {
      cylinder (d=9,h=12);
      translate ([0,0,-1]) cylinder (d=2.3,h=8);
      
   } 
    
}



module plot1()
{
   difference()
   {
      cylinder (d=7,h=8);
      translate ([0,0,-1]) cylinder (d=1.8,h=8);
      
   } 
    
}

module coque_inf()
{
difference()
{
    union()
    {
        box1 (282,126,7,14,2);
        translate ([1,1,6]) plaque(280,124,2,2);
    }      
        
   difference()
    {
     translate ([3.8,3.9,4]) plaque(274,118,6,4);
     translate ([60,117.3,4]) cube ([20,5,5]); 
     translate ([220,117.3,4]) cube ([20,5,5]);         
     translate ([60,3.7,4]) cube ([20,5,5]);   
     translate ([220,3.7,4]) cube ([20,5,5]);      
     translate ([135,3.7,4]) cube ([11,5,2]); 
     translate ([135,117,4]) cube ([11,5,2]); 
    }
    
  translate ([9.1,14.1,-0.1]) tete_vis();
  translate ([9.1,112.8-1.1,-0.1]) tete_vis();
  translate ([273.6-1.1,14.1,-0.1]) tete_vis();
  translate ([273.6-1.1,112.8-1.1,-0.1]) tete_vis();
   
  translate ([140.5,6.5,-0.1]) tete_vis1();  
  translate ([140.5,119.5,-0.1]) tete_vis1();  
           
difference()
    {
        translate ([7,12,1.5]) cube ([272.6-6,107.8-6,6]);
        translate ([9.1,14.1,-0.1]) cylinder (d=12,h=7);
        translate ([9.1,112.8-1.1,-0.1]) cylinder (d=12,h=7);
        translate ([273.6-1.1,14.1,-0.1]) cylinder (d=12,h=7);
        translate ([273.6-1.1,112.8-1.1,-0.1]) cylinder (d=12,h=7); 
        
    translate ([65,25,0]) cube ([40,5,30]);    
    translate ([125,25,1.5]) cube ([40,5,30]);
    translate ([100,48,1.5]) cube ([60,5,30]);
    translate ([120,85,1.5]) cube ([60,5,30]);    
        
  difference()
    {      
        translate ([44.9,111.75,0]) cylinder (d=9,h=7);
        translate ([44.9,111.75,1]) cylinder (d=2.3,h=7);
    }   
    }
   // passage câble
   translate ([-5,102,9]) rotate ([0,90,0]) cylinder (d=8,h=15);
    
  // fixation des pieds  

   translate ([28,99.5,-1]) cylinder (d=3,h=6);    
   translate ([35,99.5,-1]) cylinder (d=3,h=6); 
   translate ([244,99.5,-1]) cylinder (d=3,h=6);    
   translate ([251,99.5,-1]) cylinder (d=3,h=6);  
    
}

if (plot_imp==true)
        {
            translate ([3,3,0]) cylinder (d=16,h=0.6);
            translate ([3,121,0]) cylinder (d=16,h=0.6);
            translate ([281,3,0]) cylinder (d=16,h=0.6);
            translate ([281,121,0]) cylinder (d=16,h=0.6);
        }

}





module tete_vis()
{
    union()
    {
    cylinder (d=3,h=7);
    cylinder (d1=6.5,d2=3,h=2.5);
    }
}

module tete_vis1()
{
    union()
    {
    cylinder (d=2.5,h=7);
    cylinder (d1=5,d2=2.5,h=2);
    }
}

module pcb()
{
    difference()
    {
    plaque(272.6,107.8,1.7,4);
  
    translate ([5.1,5.1,-0.1]) cylinder (d=3,h=2);
    translate ([5.1,107.8-5.1,-0.1]) cylinder (d=3,h=2);
    translate ([40.9,102.75,-0.1]) cylinder (d=3,h=2);
        translate ([272.6-5.1,5.1,-0.1]) cylinder (d=3,h=2);
    translate ([272.6-5.1,107.8-5.1,-0.1]) cylinder (d=3,h=2);
        }
    
    translate ([17.3,2.16,0]) cube ([214.4,17.8,20]);
    translate ([7.25,20.6,0]) cube ([247.4,17.8,20]);
    translate ([3.43,39.1,0]) cube ([265.81,17.8,20]);
    translate ([3.18,57.4,0]) cube ([266.1,17.8,20]);
    translate ([11.18,75.8,0]) cube ([258.1,17.8,20]);
    
     #translate ([240,5,0]) cube ([10,10,13.7]);
}

module plaque (long,larg,haut,r)
{
    hull()
    {
    translate ([r,r,0]) cylinder (d=2*r,h=haut);
    translate ([r,larg-r,0]) cylinder (d=2*r,h=haut);
    translate ([long-r,r,0]) cylinder (d=2*r,h=haut);
    translate ([long-r,larg-r,0]) cylinder (d=2*r,h=haut);   
    }
}


module box(long,larg,haut,r)
{
    hull(){
    translate ([r,r,r]) sphere (r=r);
    translate ([r,r,r]) cylinder (r=r,h=haut-r);
    translate ([long-r,r,r]) sphere (r=r);
    translate ([long-r,r,r]) cylinder (r=r,h=haut-r);
    translate ([r,larg-r,r]) sphere (r=r);
    translate ([r,larg-r,r]) cylinder (r=r,h=haut-r);        
    translate ([long-r,larg-r,r]) sphere (r=r);    
     translate ([long-r,larg-r,r]) cylinder (r=r,h=haut-r);    
      
    }
}



module box1(long,larg,haut,d,r)
{
    difference()
    {
    hull(){
    translate ([r,r,0]) tore_V(d,r);
    translate ([r,larg-d+r,0]) tore_V(d,r);    
    translate ([long-r,r,0]) tore_V(d,r);         
    translate ([long-r,larg-d+r,0]) tore_V(d,r);            
    }
    
    translate ([-1,-1,haut]) cube ([long+2,larg+2,d]);    
}  
}

module tore_V (d,r)
{
    translate ([-d/2+r,d/2-r,d/2]) rotate ([0,90,0])  rotate_extrude(convexity = 10, $fn = 50)
        translate([d/2-r, d/2-r, 0])
            circle(r = r, $fn = 50);
    
    
}

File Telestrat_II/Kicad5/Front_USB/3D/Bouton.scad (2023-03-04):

$fn=80;

cylinder (d=3.4,h=12);
translate ([-4.5,-4.5,0]) cube ([9,9,6.5]);

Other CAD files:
Telestrat_II/Montage/Bouton.stl
BUS_ORIC/3D/boitier.stl
EXP_Cartouche/3D/Cartouche_ORIC2M_inf.stl
EXP_Cartouche/3D/Cartouche_ORIC_sup.stl

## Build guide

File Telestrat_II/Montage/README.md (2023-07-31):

# Modification du Gotek

Tout d'abord, il faut démonter le lecteur Gotek afin de récupérer la platine principale ainsi que le circuit afficheur.

Sur le circuit afficheur, il suffit de dessouder les composants pour récupérer le circuit intégré et l'afficheur.

Sur la platine principale, il faut dessouder le connecteur USB, les 2 boutons poussoirs et la led.
La led est remplacée par une barette de 2 contacts à 90° au pas de 2.54mm afin d'y connecter la led de la façade.

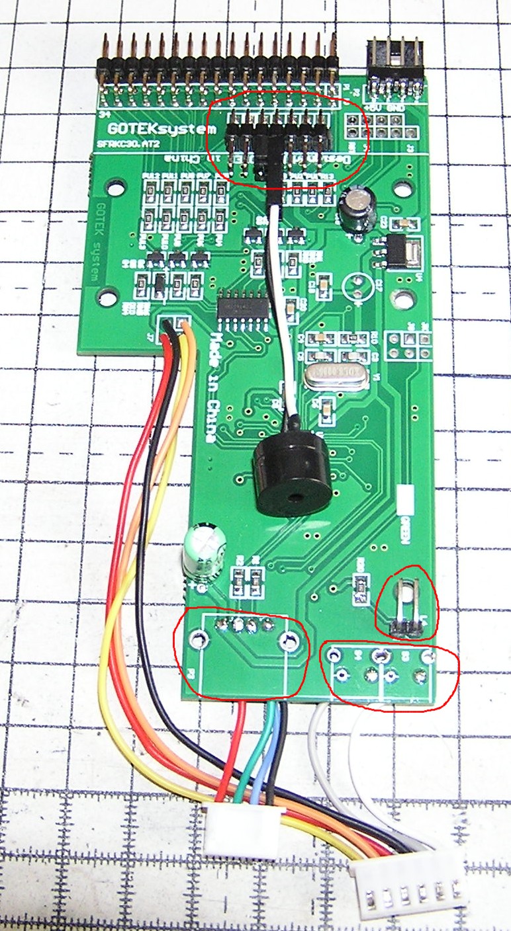
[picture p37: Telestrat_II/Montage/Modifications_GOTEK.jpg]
Modifications Gotek Optional Title


La barette de configuration du Gotek peut être laissée en place.  Dans ce cas il n'est pas possible de mettre la barre support des lecteurs 2.5". Comme elle ne sert pas, ce n'est pas grave.
Elle peut aussi être remplacée par une barette de contacts à 90°. Dans ce cas, la barre peut être mise en place et les contacts restent accessibles.

Seul le cavalier S0 (3 ème en partant de la gauche) doit être en place. Il est possible d'ajouter un buzzer sur les bornes JB (4 ème en partant de la gauche)

Les connexions vers la nouvelle platine d'affichage sont assurées par 2 connecteurs XH à 4 et 6 contacts (il est possible de souder directement les fils sur la platine sans utiliser de connecteur).
Les branchements sont indiqués sur la figure ci-dessous. La longeur des fils est également indiquée.

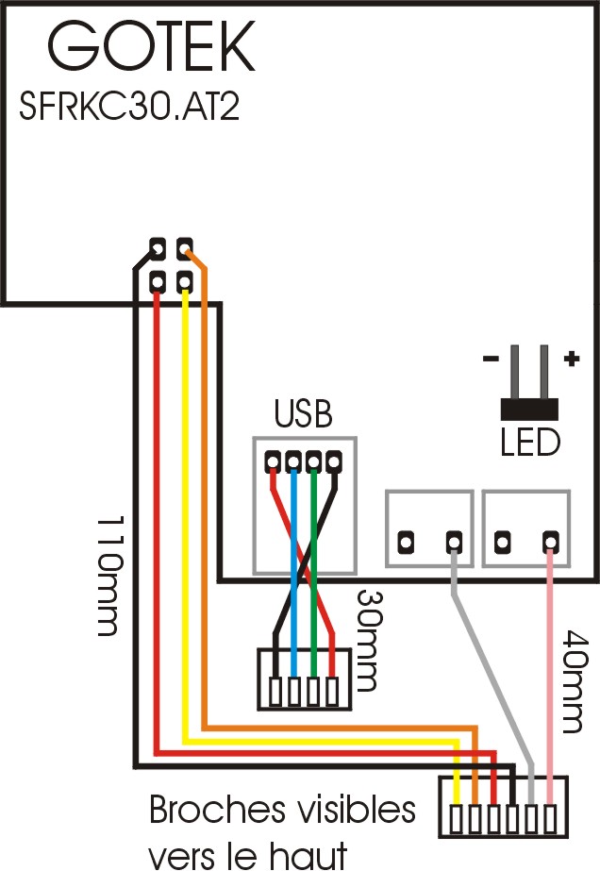
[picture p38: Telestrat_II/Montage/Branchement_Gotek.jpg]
Branchement Gotek Optional Title


# Platine d'affichage

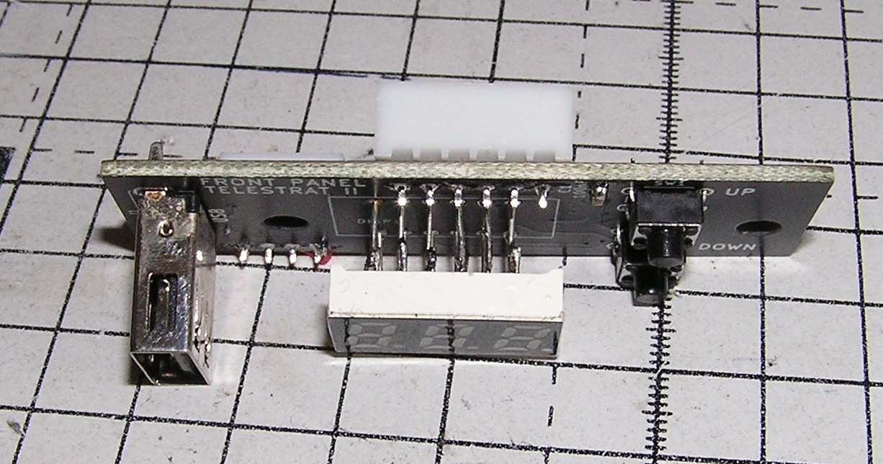
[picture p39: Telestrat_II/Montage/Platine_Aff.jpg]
Platine Affichage Optional Title


Les composants récupérés de la platine d'affichage du Gotek sont montés sur cette platine. L'afficheur doit être surélevé de 7mm (espace entre le pcb et le dessous de l'afficheur) par rapport au pcb à l'aide de petits morceaux de fil rigide.
La prise USB est récupérée de la platine USB du boîtier. Les boutons poussoirs sont des modèles 6x6mm avec une hauteur de 6mm.

# Modification du boîtier

La face arrière du boîtier doit être modifiée pour laisser passer les connecteurs. Pour cela, il faut faire une découpe à la lime de 3mm au niveau du connecteur DE9 et de 1mm au dessus du connecteur IDC14.
Une fois la découpe du connecteur DE9 effectuée, il suffit de mettre le pcb en place pour reporter les limites du connecteur IDC afin de faire sa découpe.

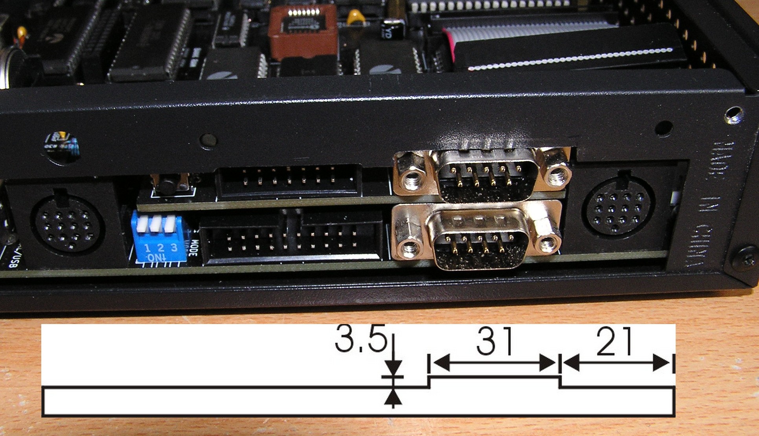
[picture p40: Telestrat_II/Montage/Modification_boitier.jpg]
Modification de la face arrière Optional Title


# Modification de la façade

La façade doit être modifiée pour accueillir la nouvelle platine d'affichage.
En partant du trou du connecteur USB de droite, il suffit d'élargir l'ouverture selon les dimensions indiquées puis de coller un petit morceau de plexiglass rouge.
L'ajustement des boutons poussoirs est facilité par une pièce 3D qui vient faire la jonction entre la façade et les boutons du pcb.

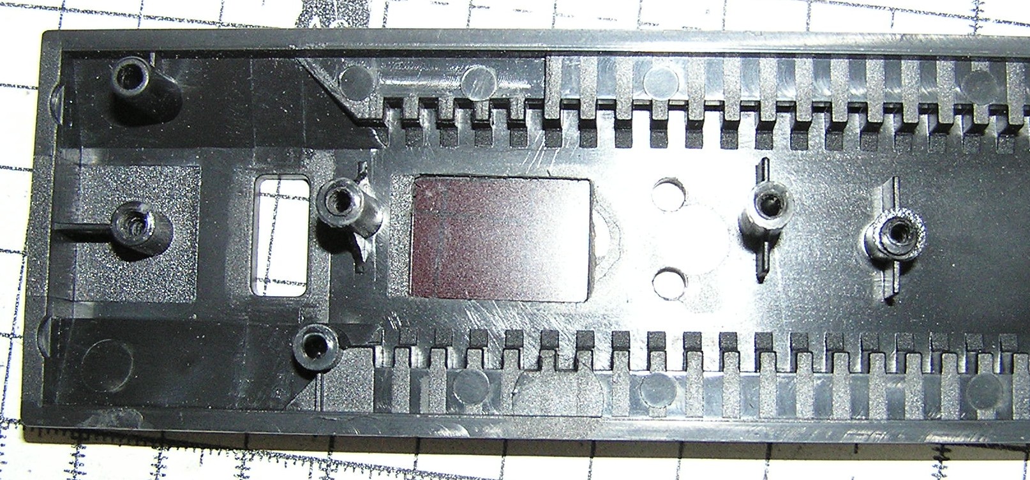
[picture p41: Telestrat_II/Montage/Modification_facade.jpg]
Modification de la façade Optional Title


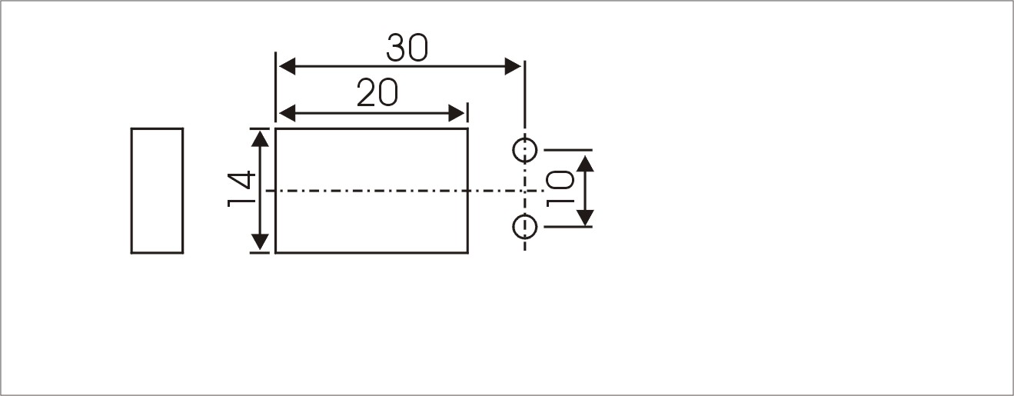
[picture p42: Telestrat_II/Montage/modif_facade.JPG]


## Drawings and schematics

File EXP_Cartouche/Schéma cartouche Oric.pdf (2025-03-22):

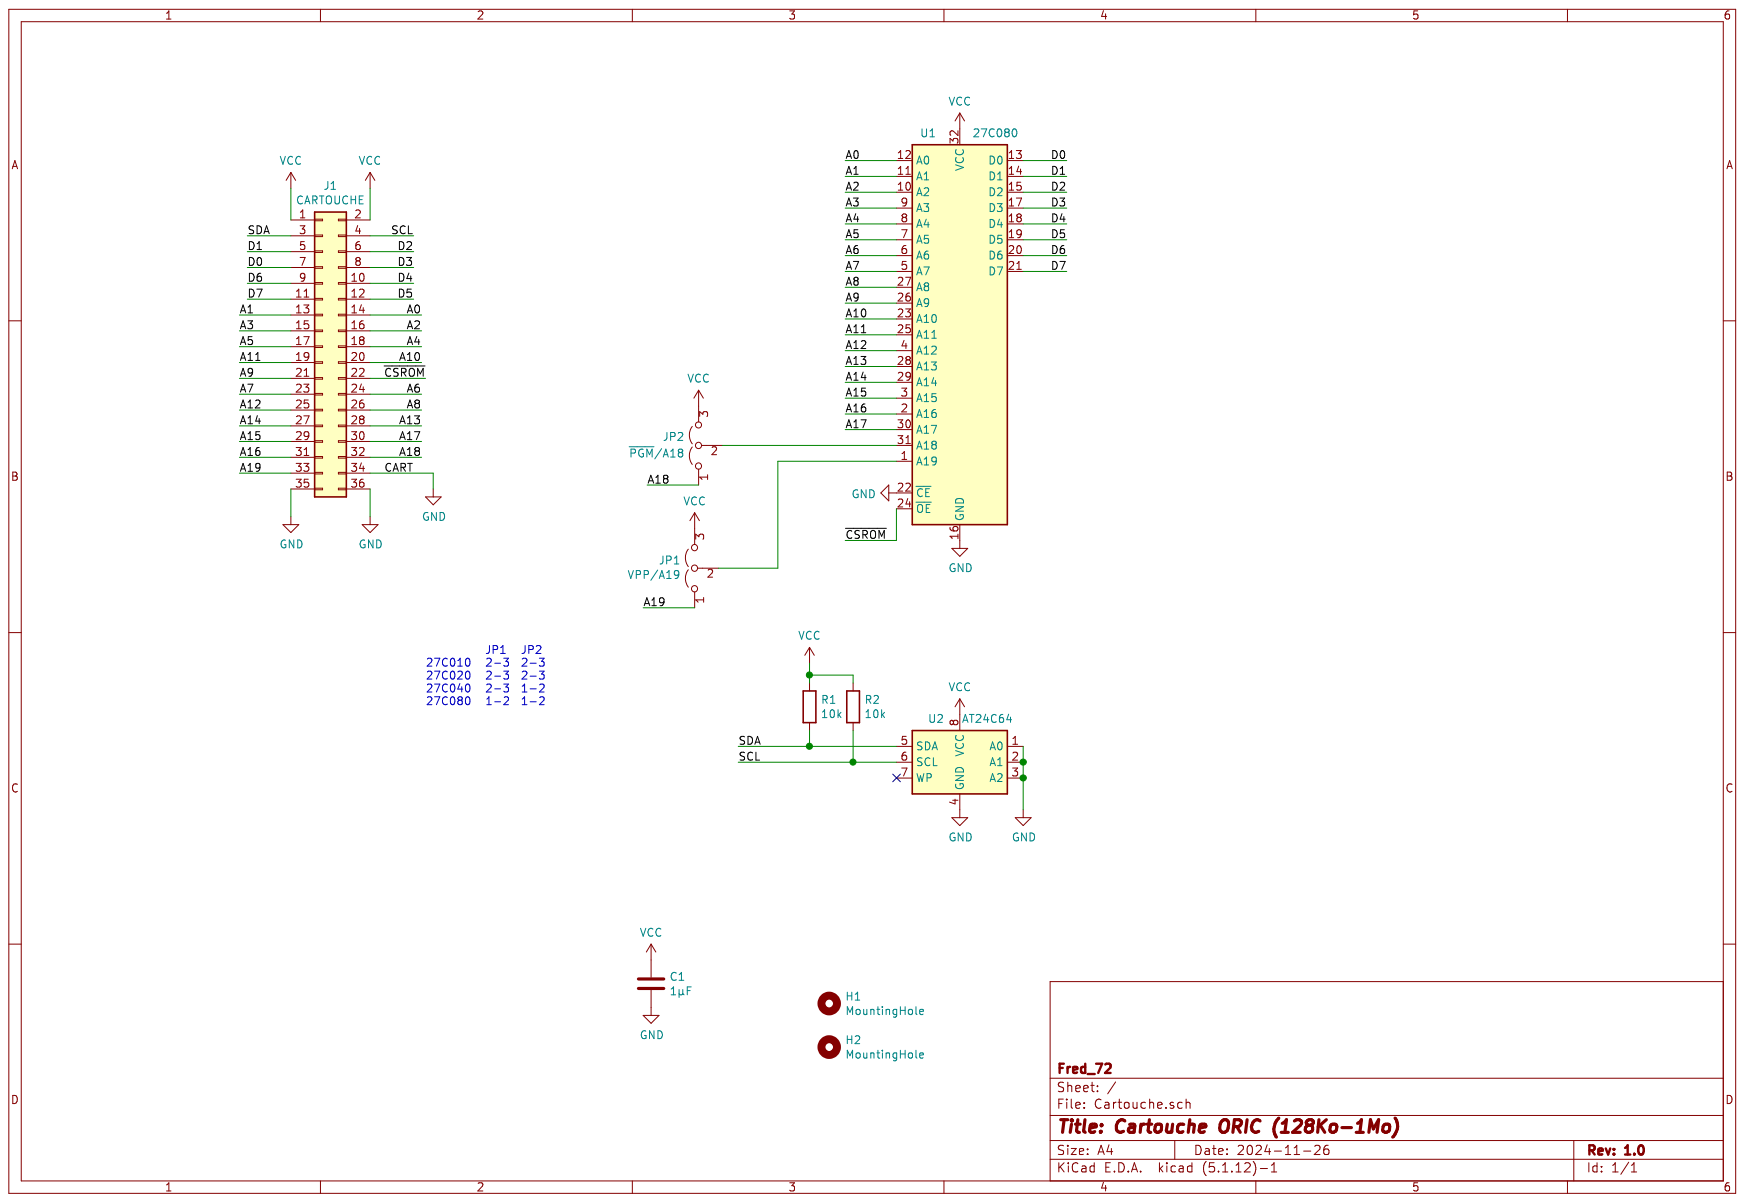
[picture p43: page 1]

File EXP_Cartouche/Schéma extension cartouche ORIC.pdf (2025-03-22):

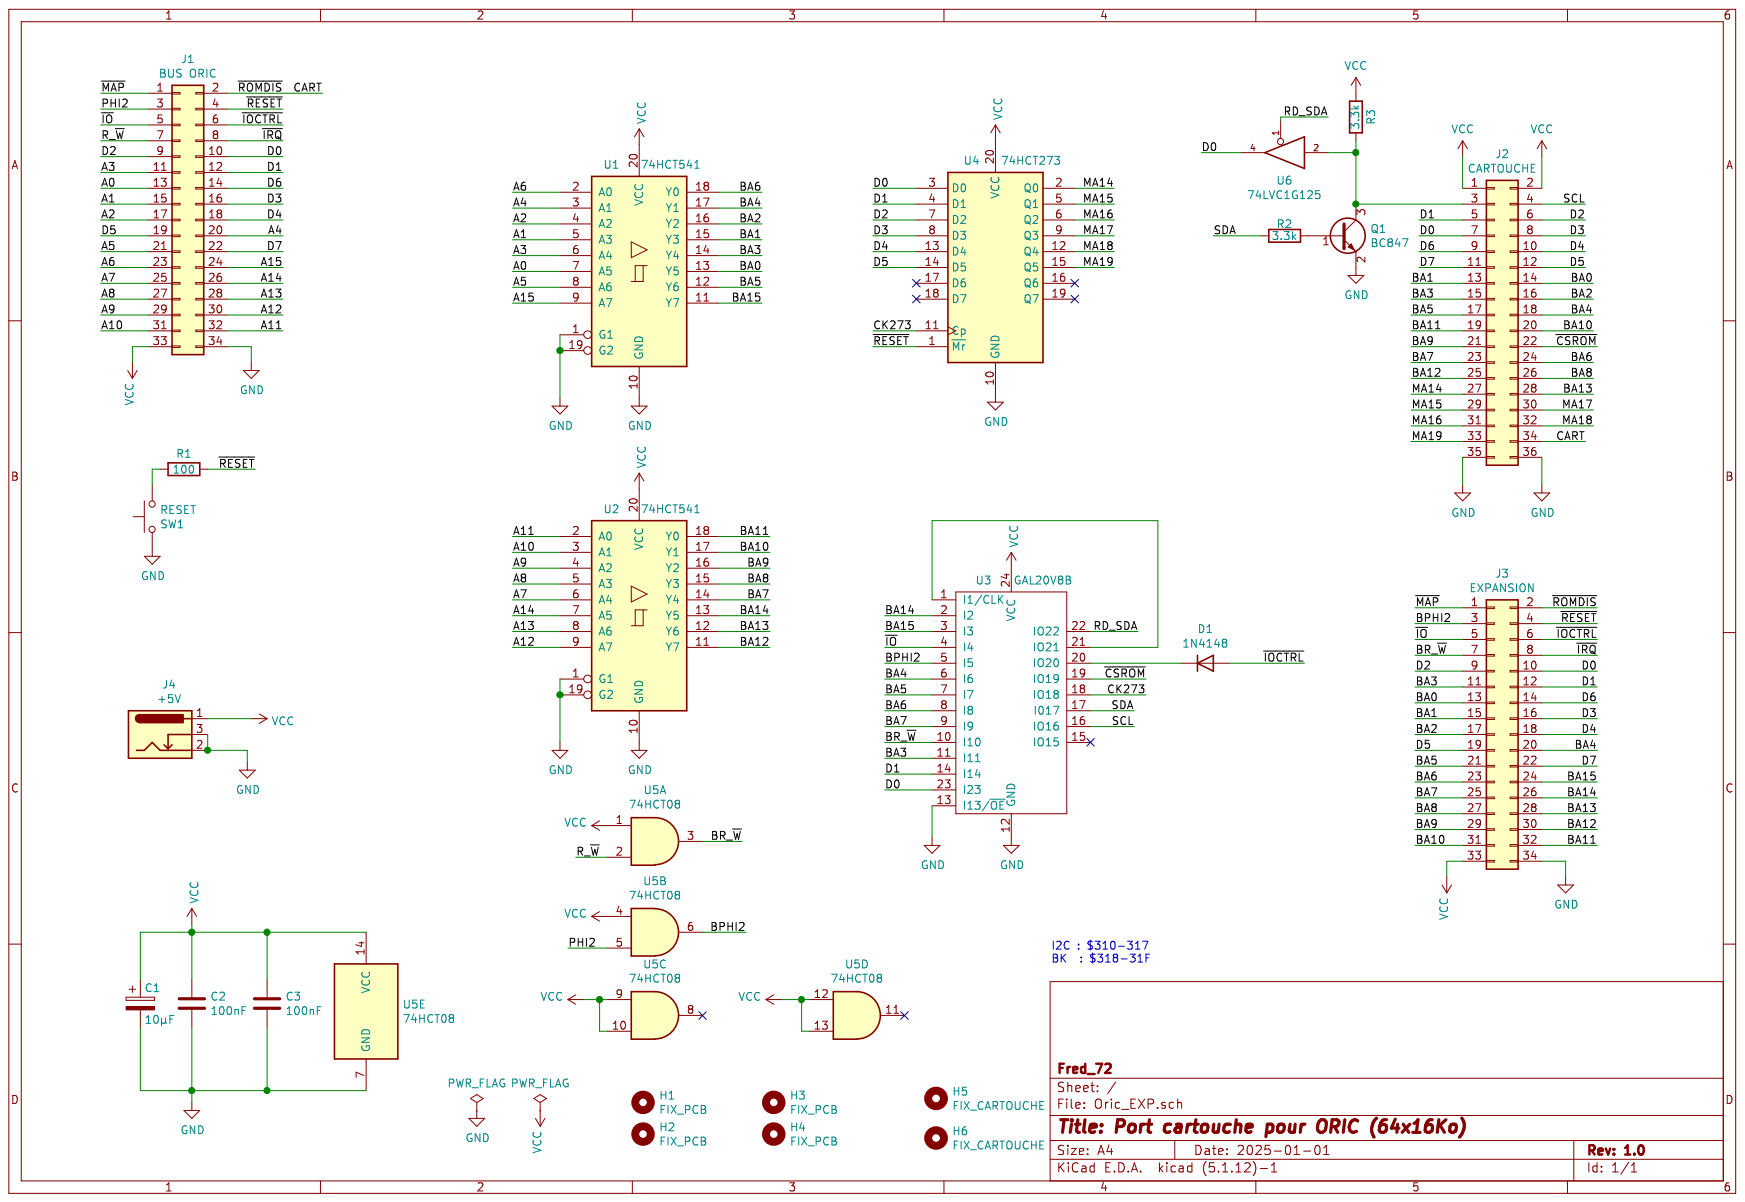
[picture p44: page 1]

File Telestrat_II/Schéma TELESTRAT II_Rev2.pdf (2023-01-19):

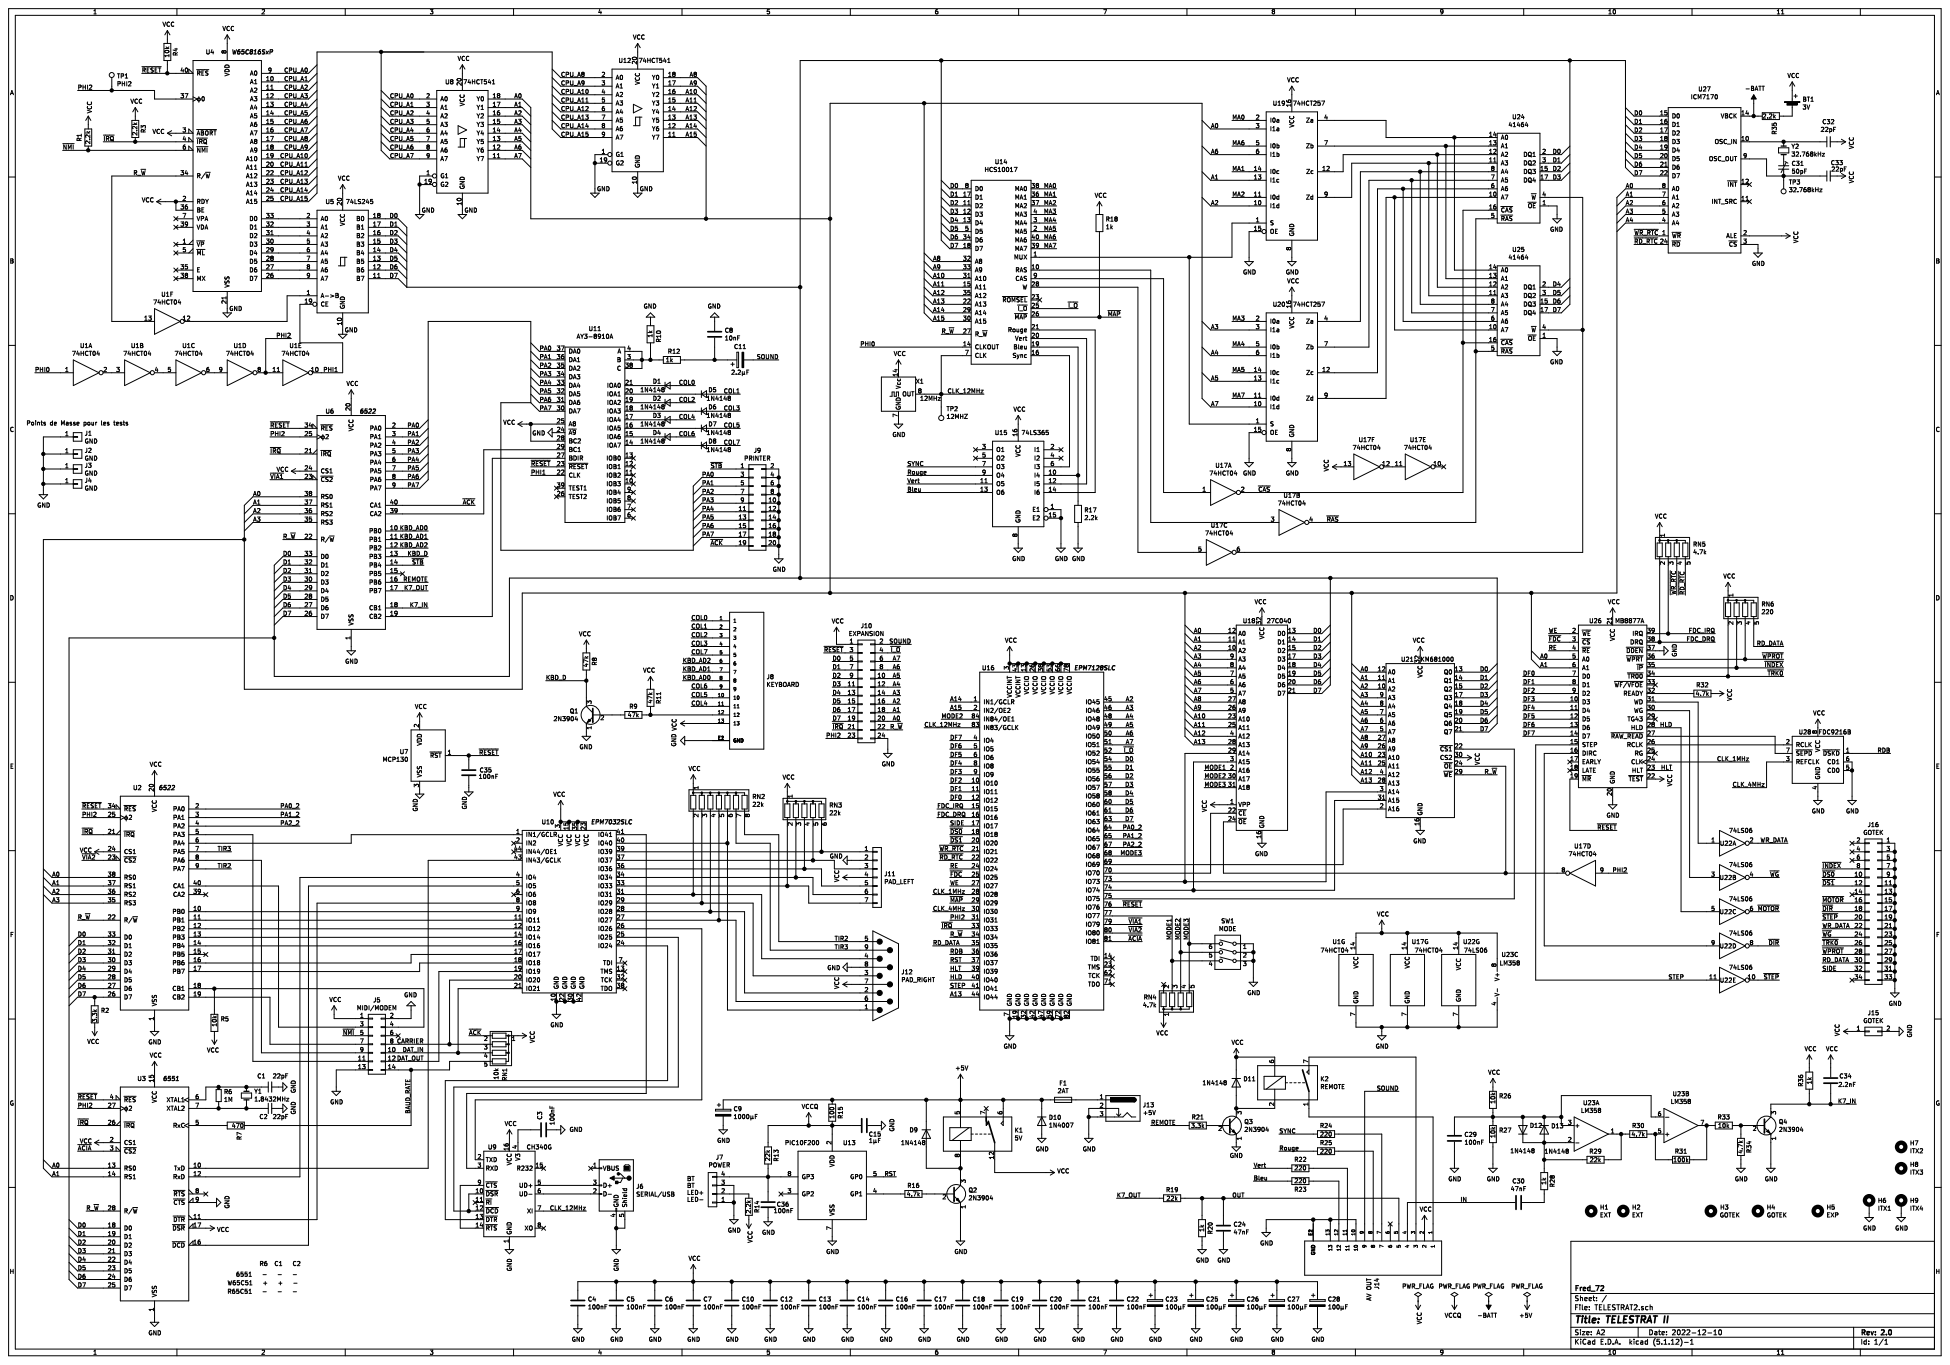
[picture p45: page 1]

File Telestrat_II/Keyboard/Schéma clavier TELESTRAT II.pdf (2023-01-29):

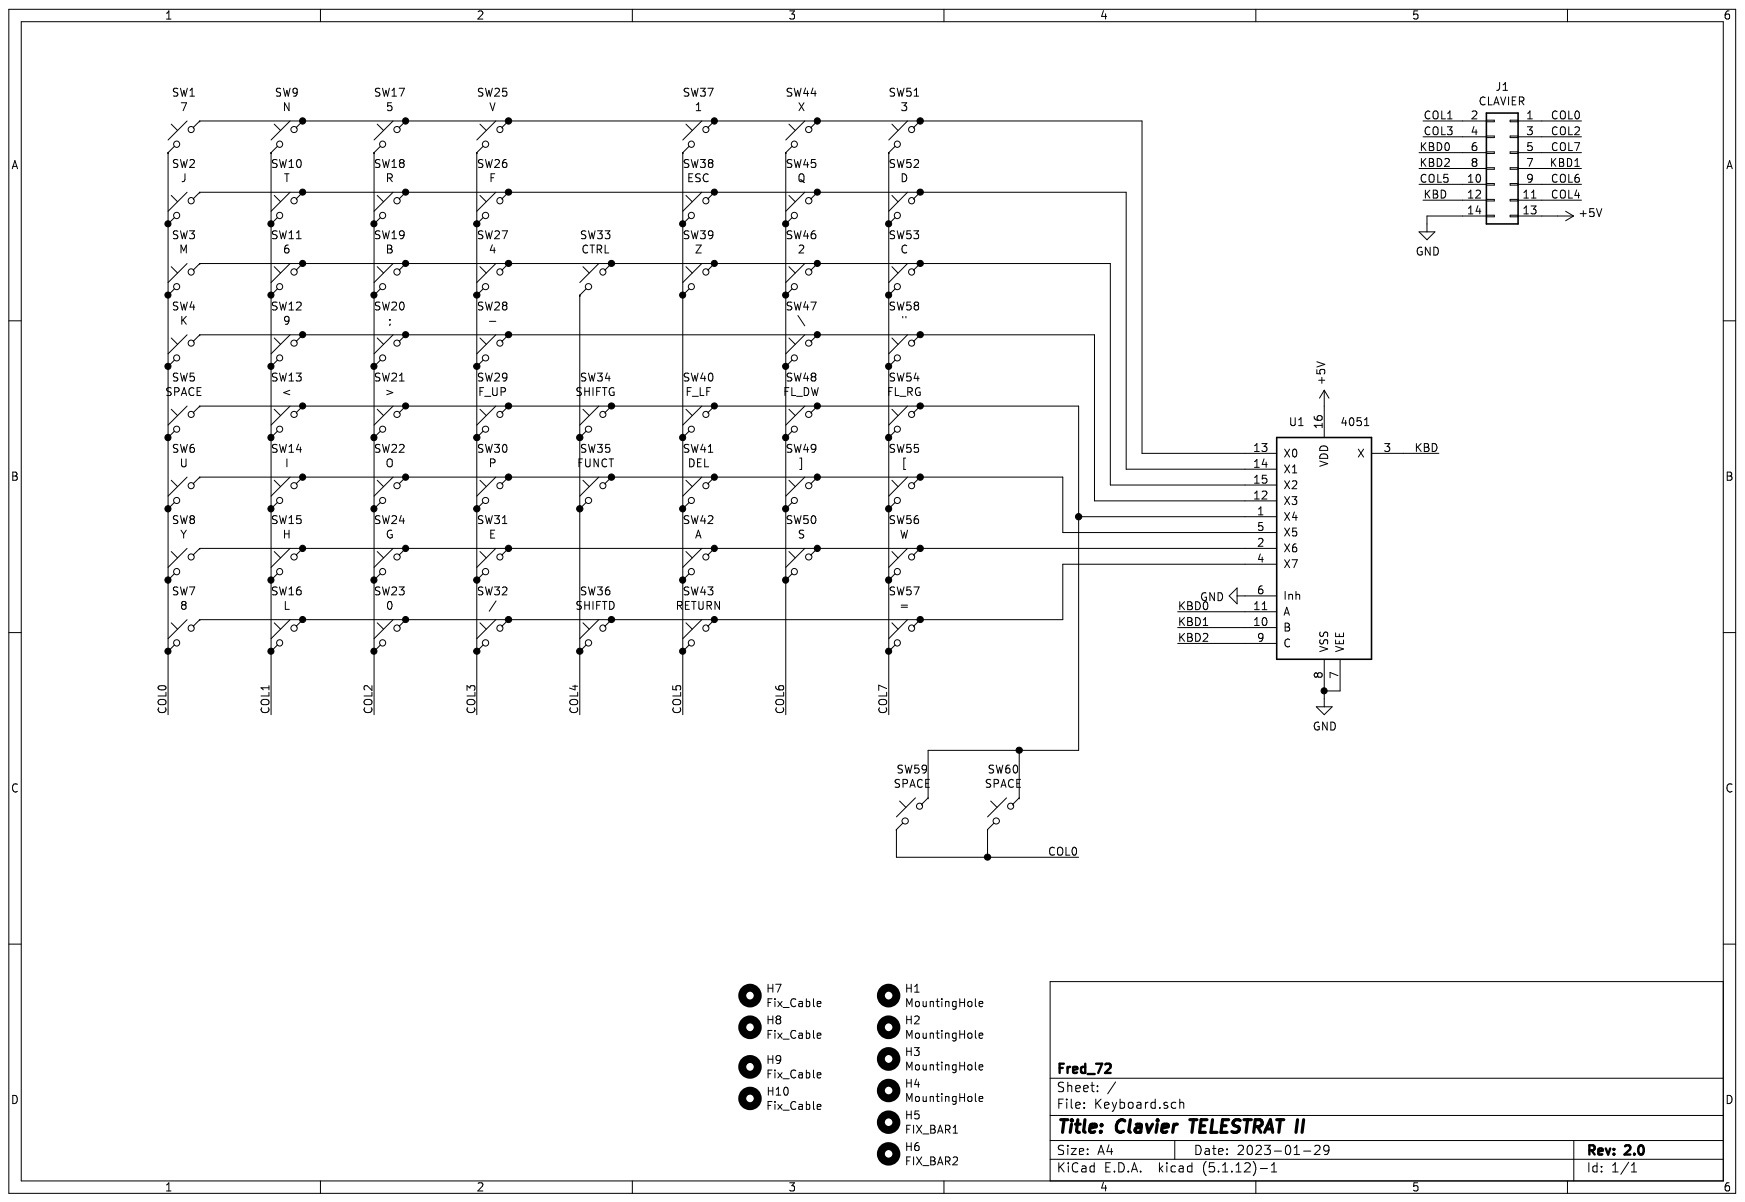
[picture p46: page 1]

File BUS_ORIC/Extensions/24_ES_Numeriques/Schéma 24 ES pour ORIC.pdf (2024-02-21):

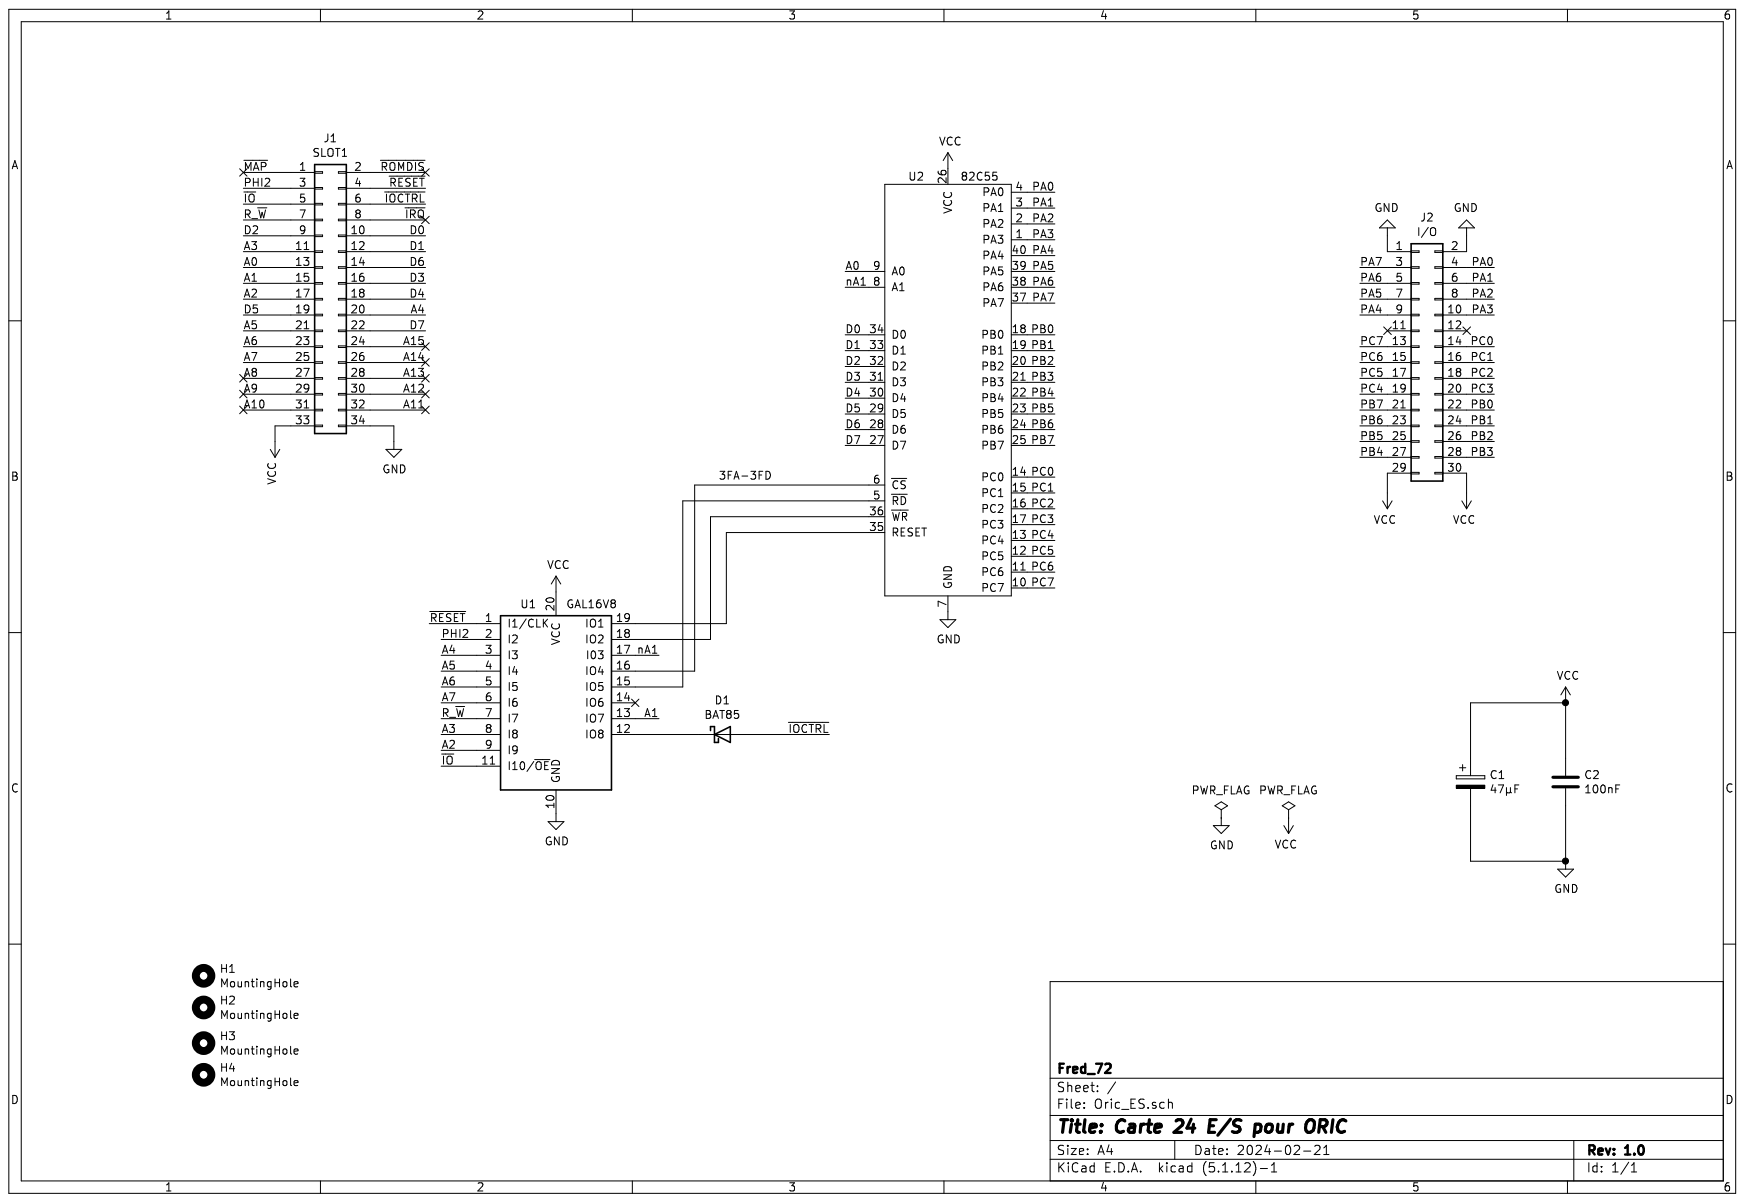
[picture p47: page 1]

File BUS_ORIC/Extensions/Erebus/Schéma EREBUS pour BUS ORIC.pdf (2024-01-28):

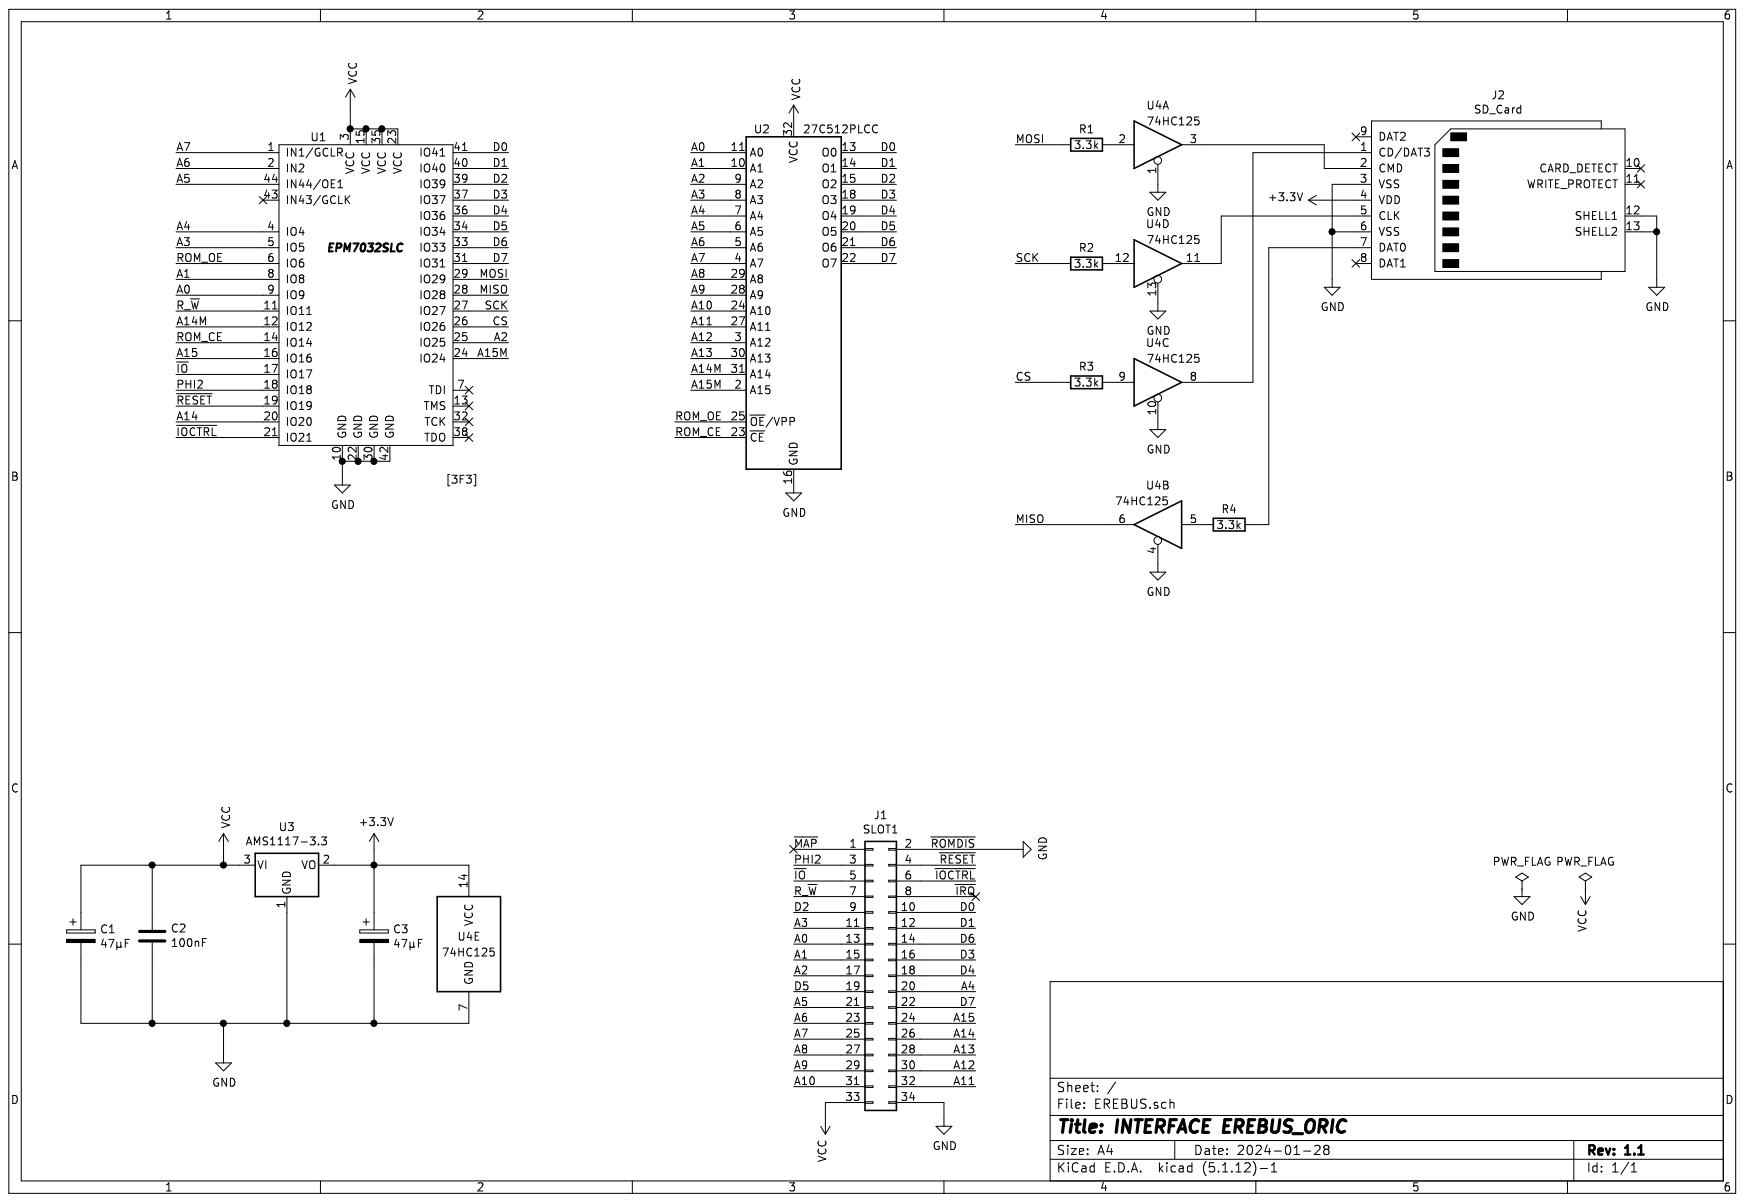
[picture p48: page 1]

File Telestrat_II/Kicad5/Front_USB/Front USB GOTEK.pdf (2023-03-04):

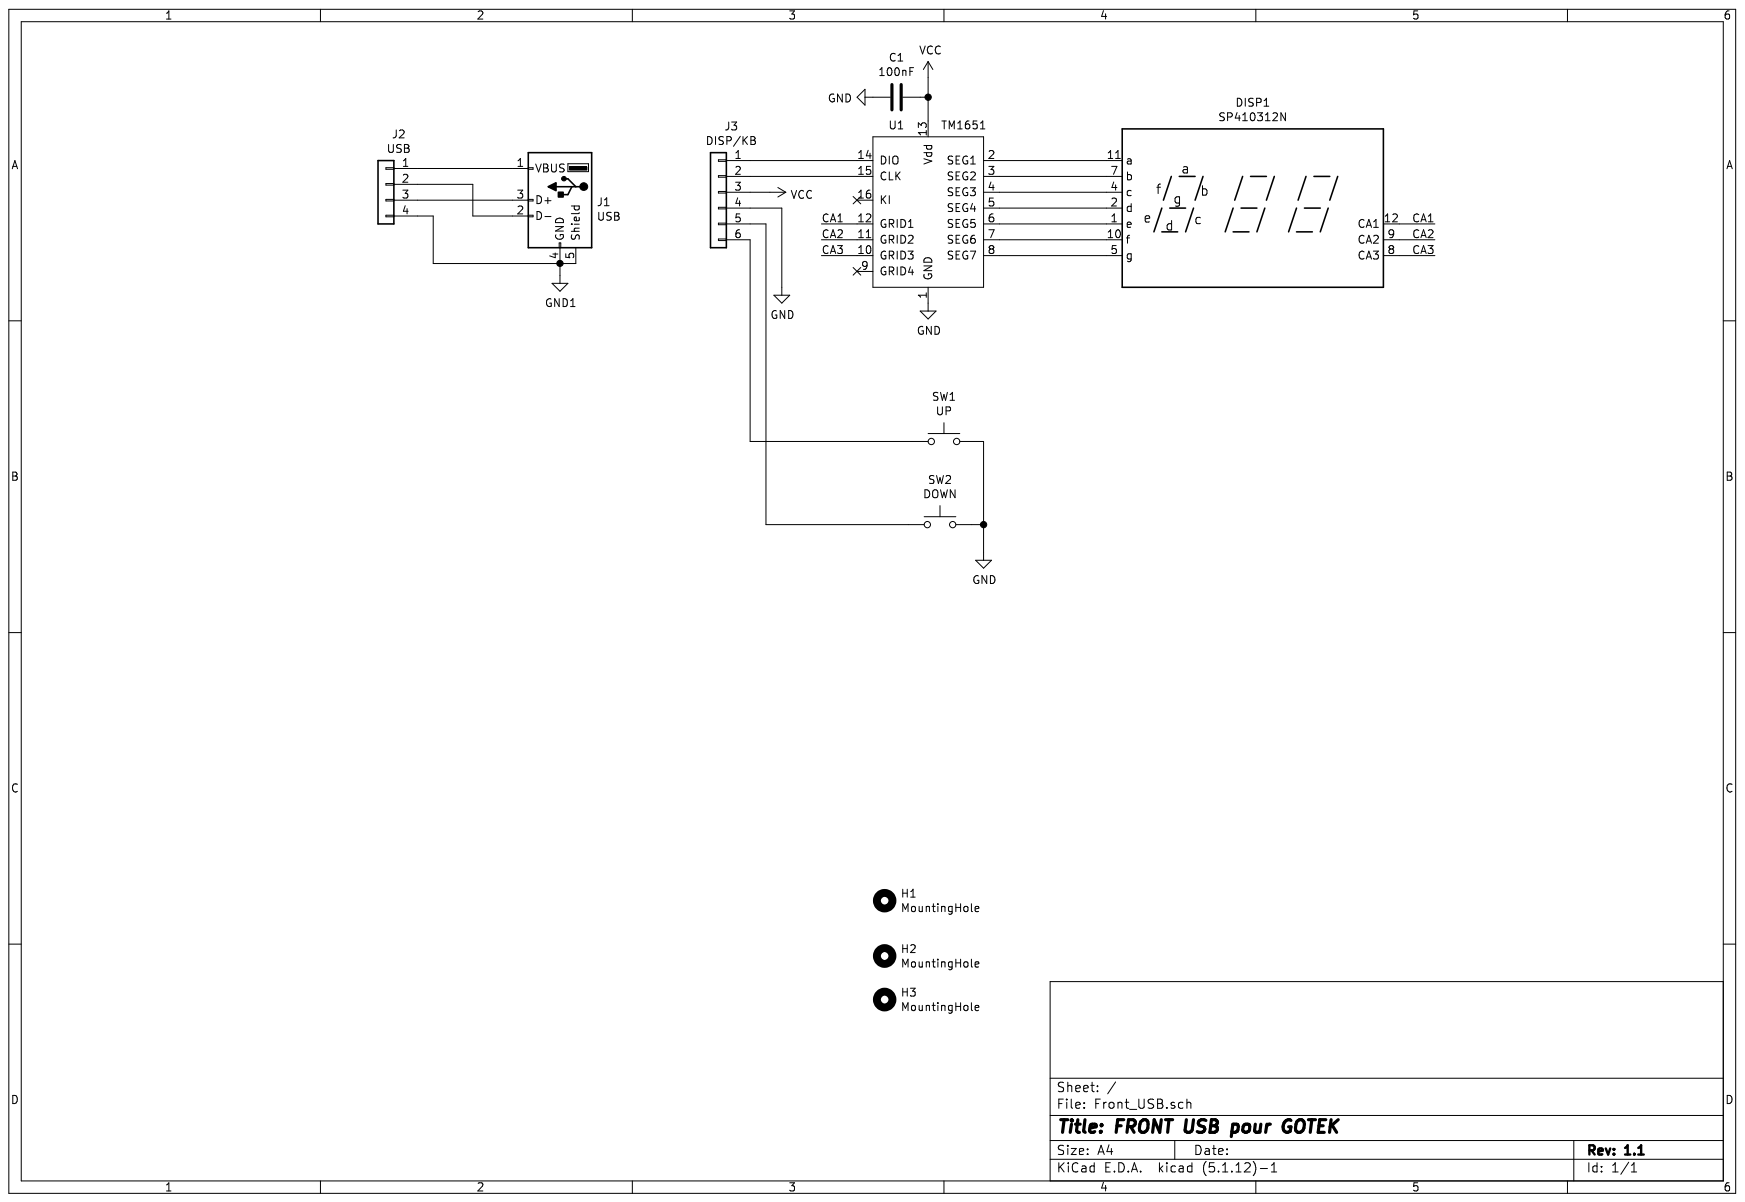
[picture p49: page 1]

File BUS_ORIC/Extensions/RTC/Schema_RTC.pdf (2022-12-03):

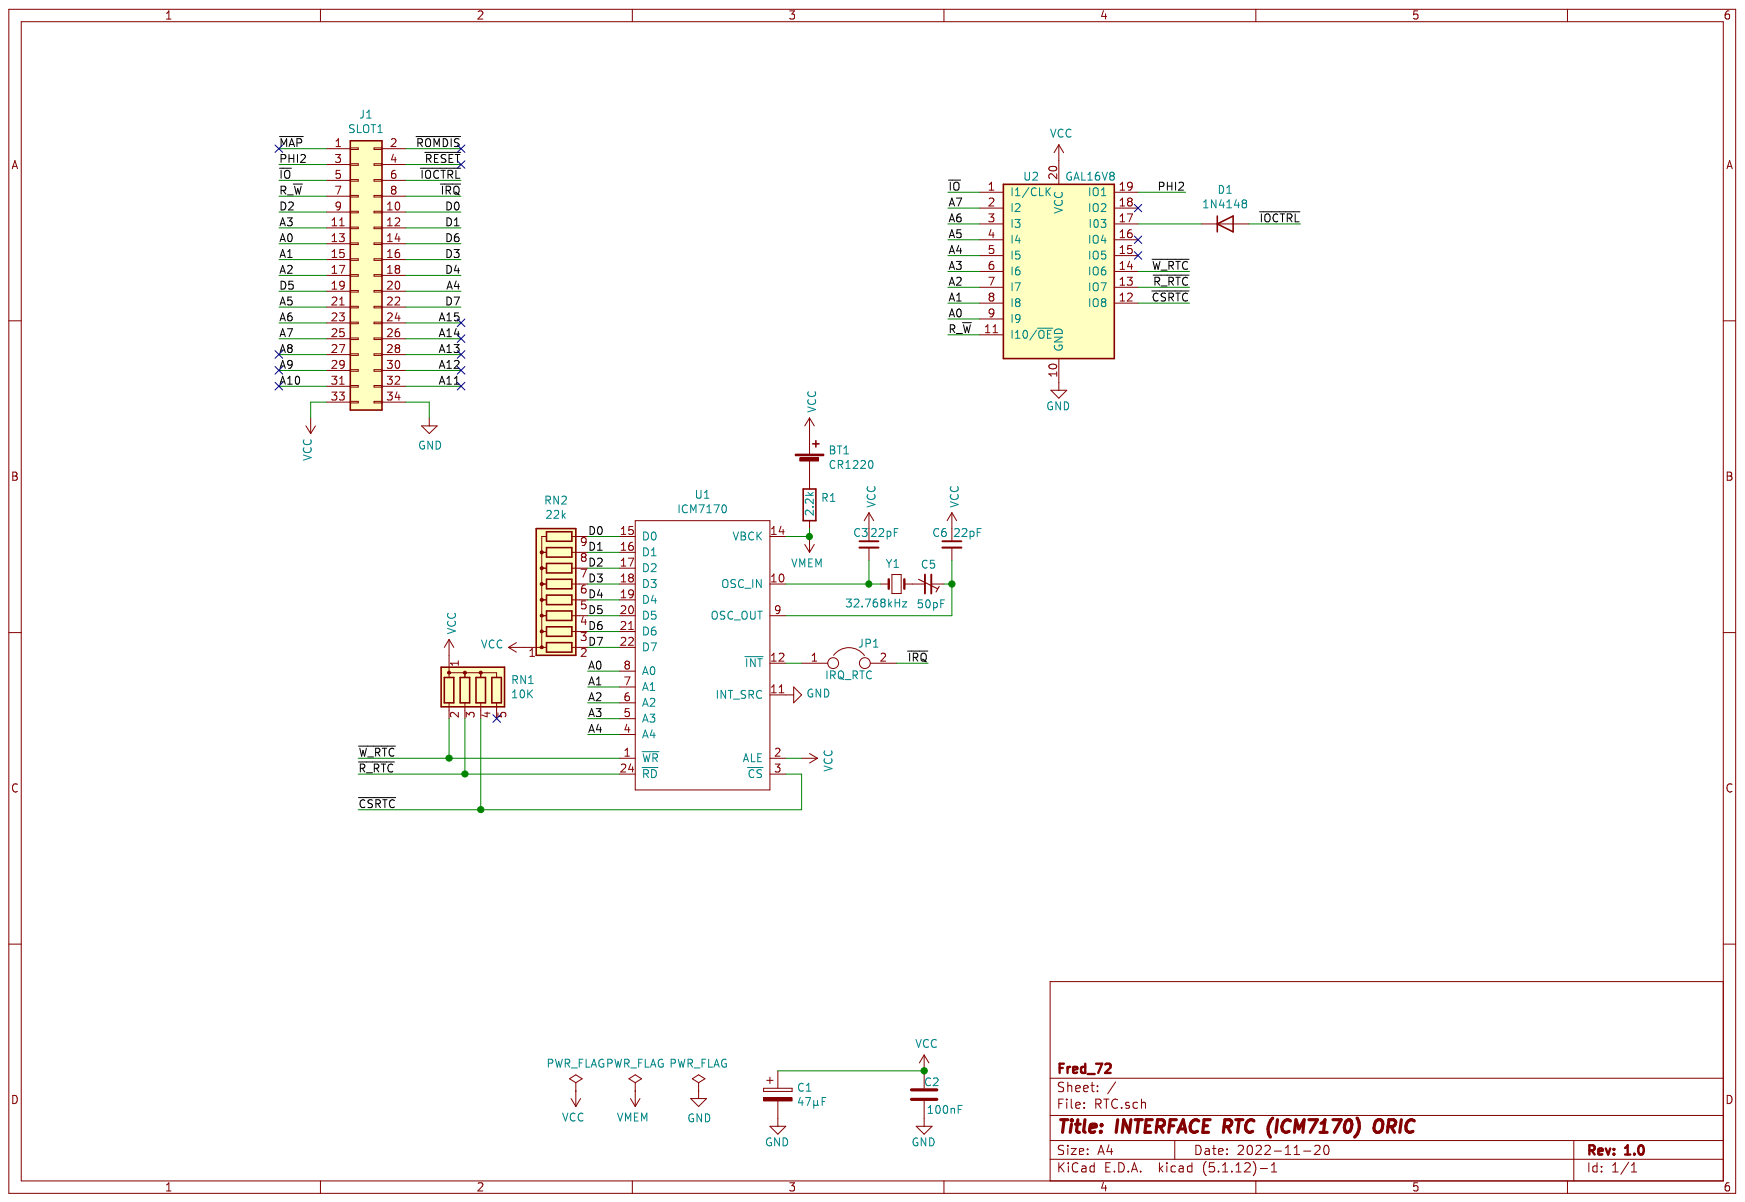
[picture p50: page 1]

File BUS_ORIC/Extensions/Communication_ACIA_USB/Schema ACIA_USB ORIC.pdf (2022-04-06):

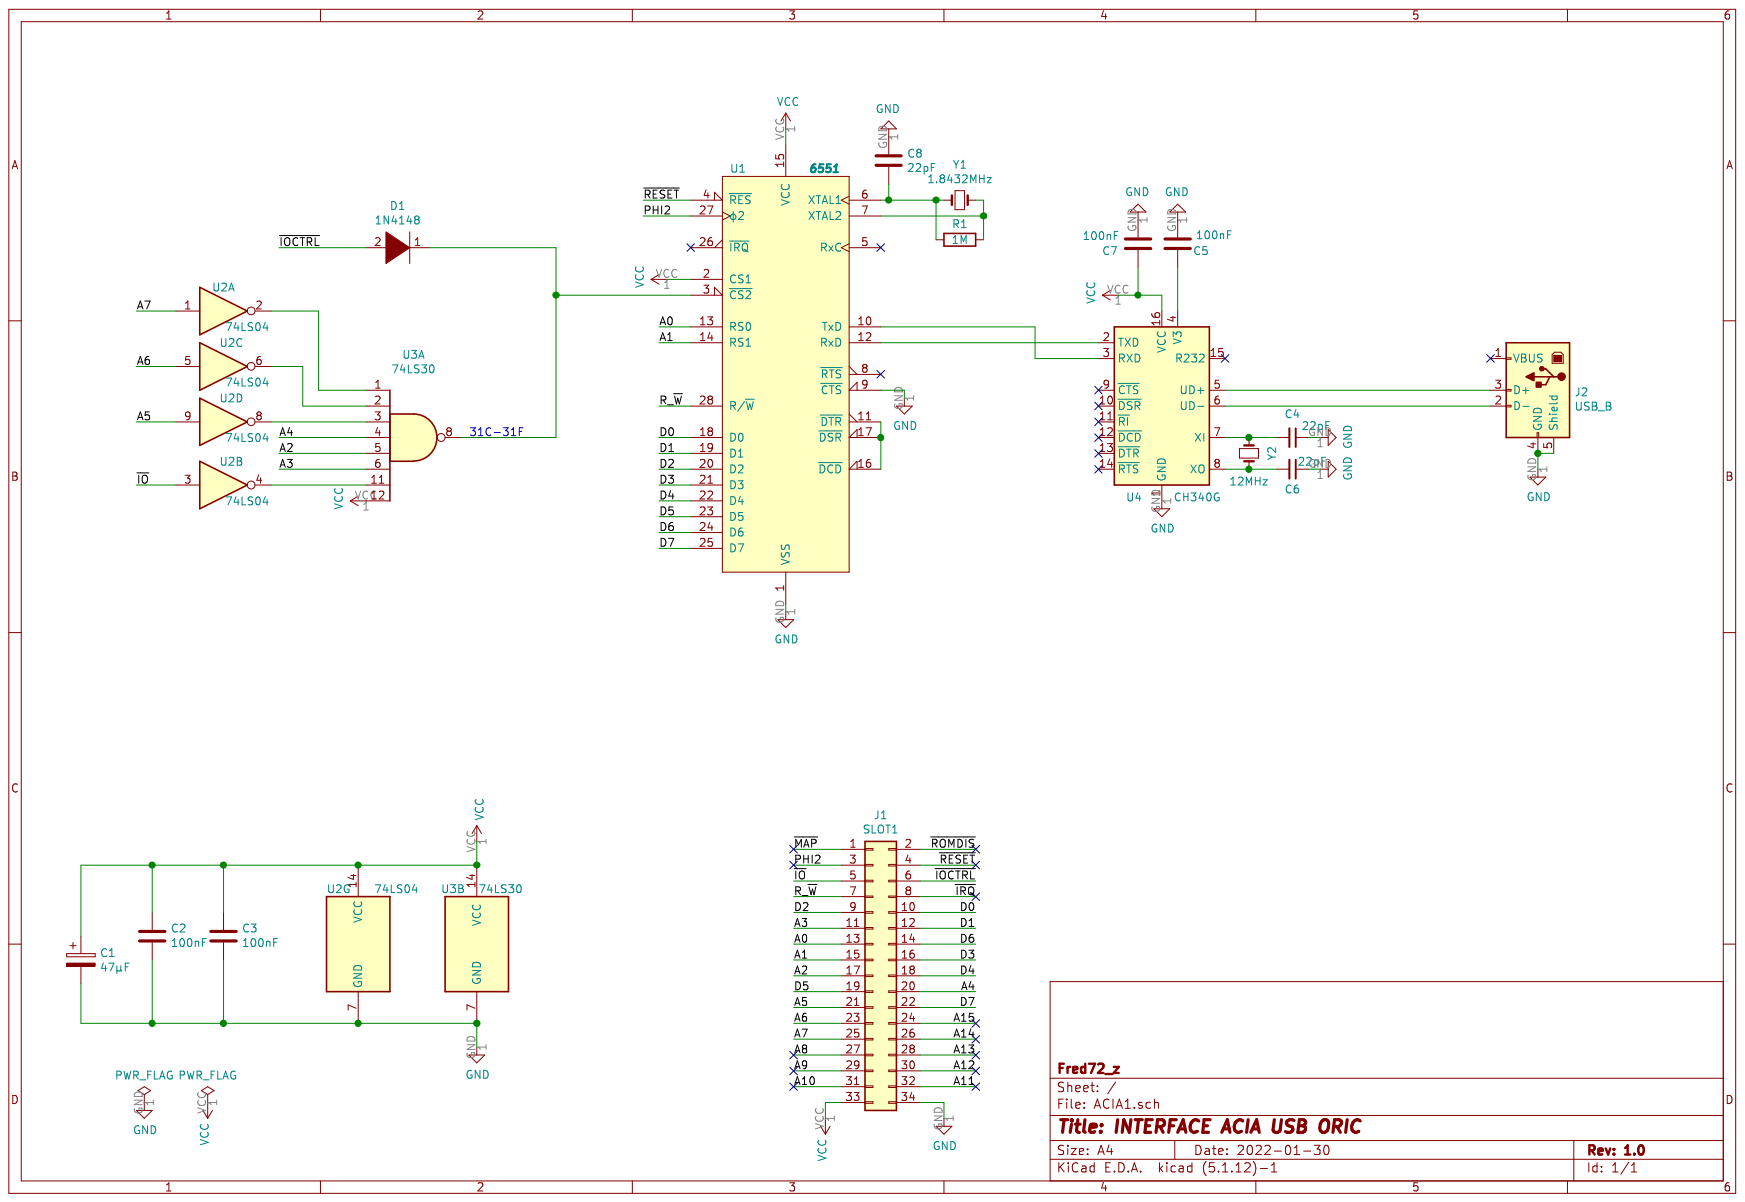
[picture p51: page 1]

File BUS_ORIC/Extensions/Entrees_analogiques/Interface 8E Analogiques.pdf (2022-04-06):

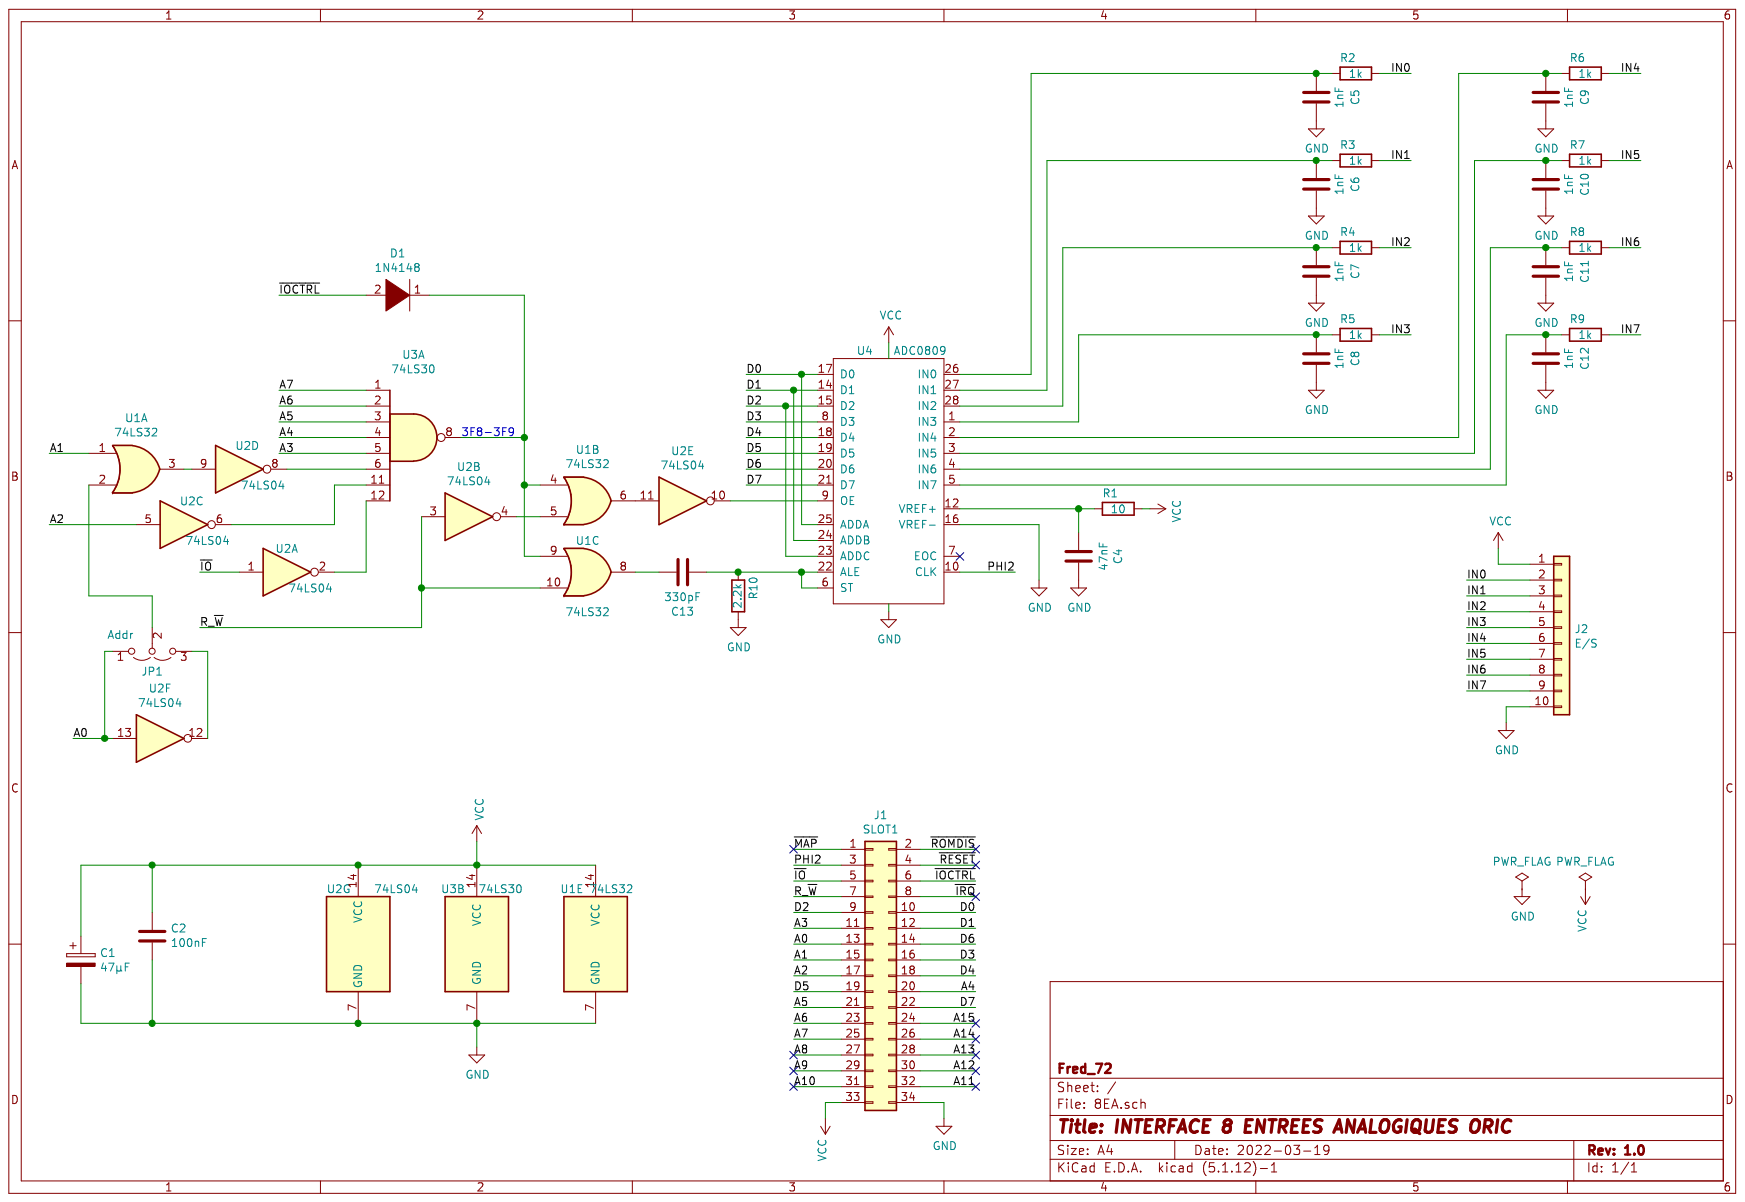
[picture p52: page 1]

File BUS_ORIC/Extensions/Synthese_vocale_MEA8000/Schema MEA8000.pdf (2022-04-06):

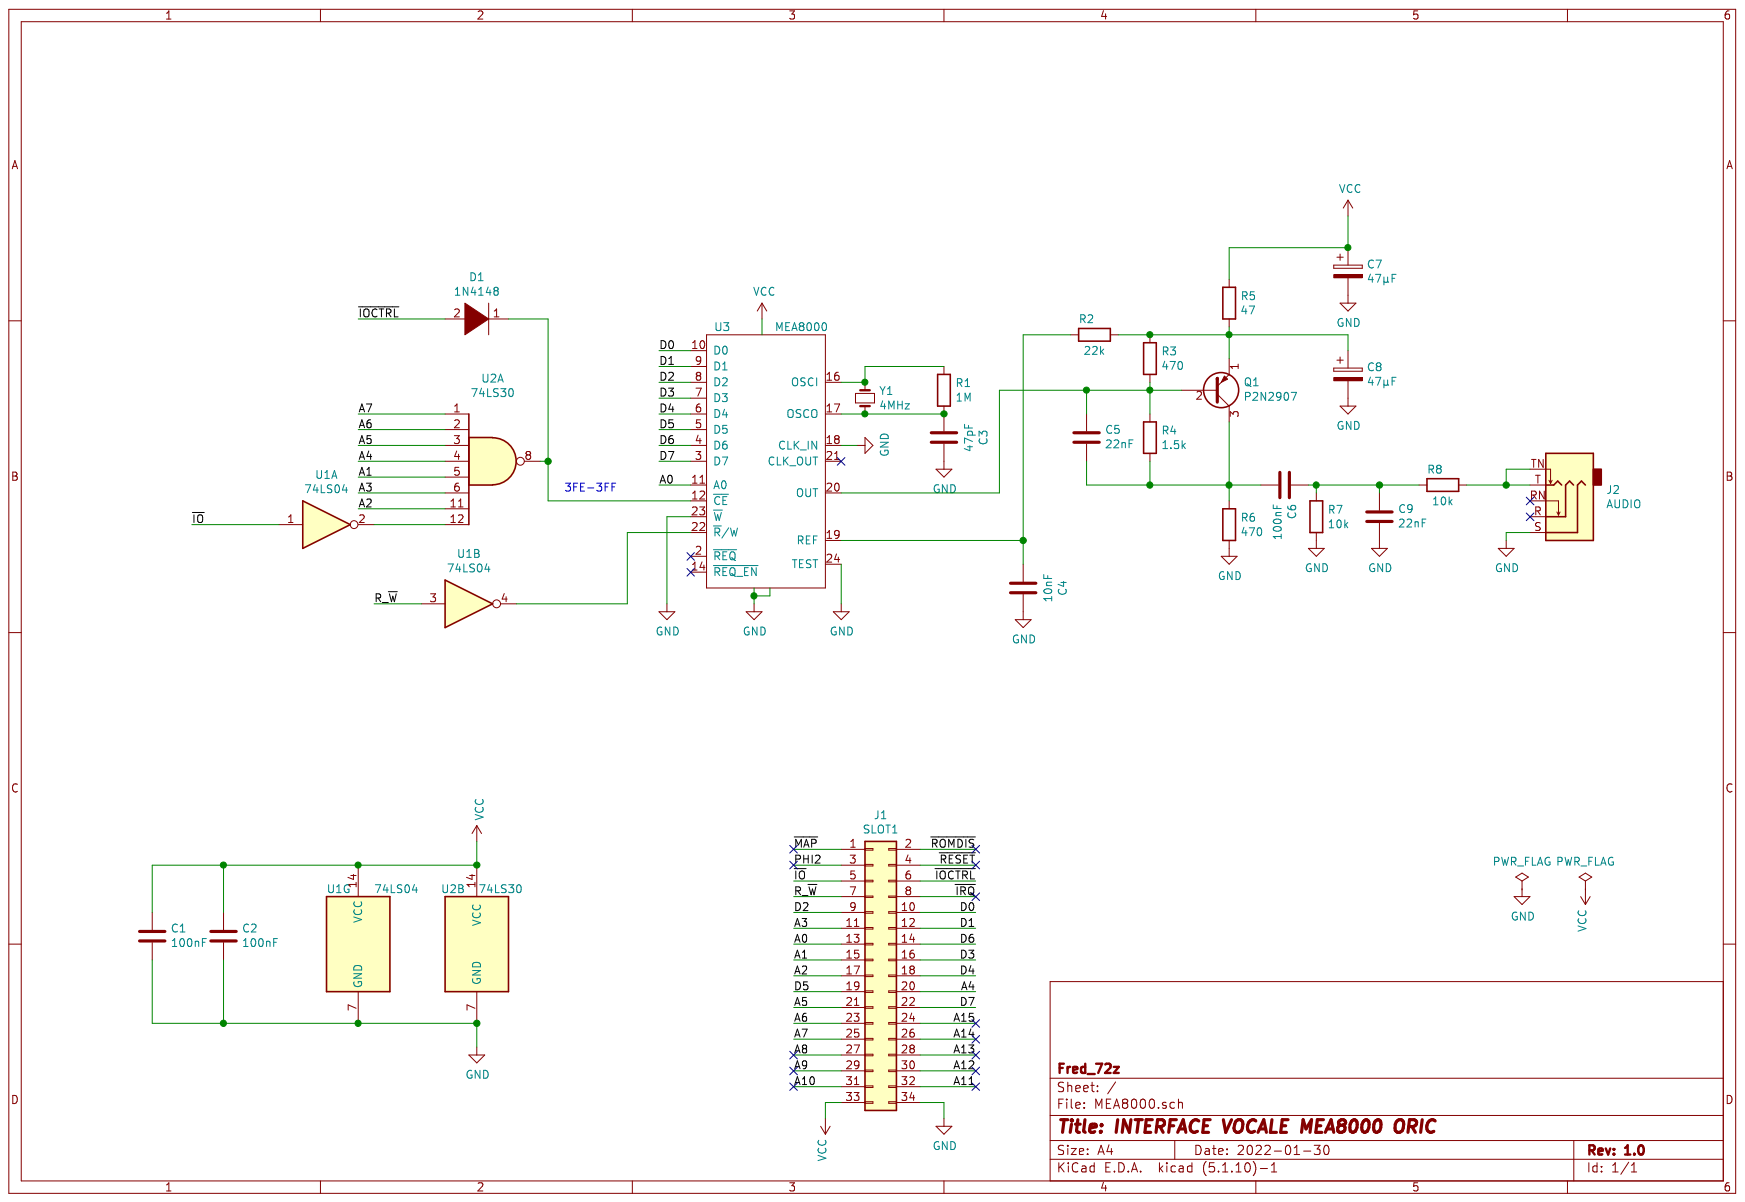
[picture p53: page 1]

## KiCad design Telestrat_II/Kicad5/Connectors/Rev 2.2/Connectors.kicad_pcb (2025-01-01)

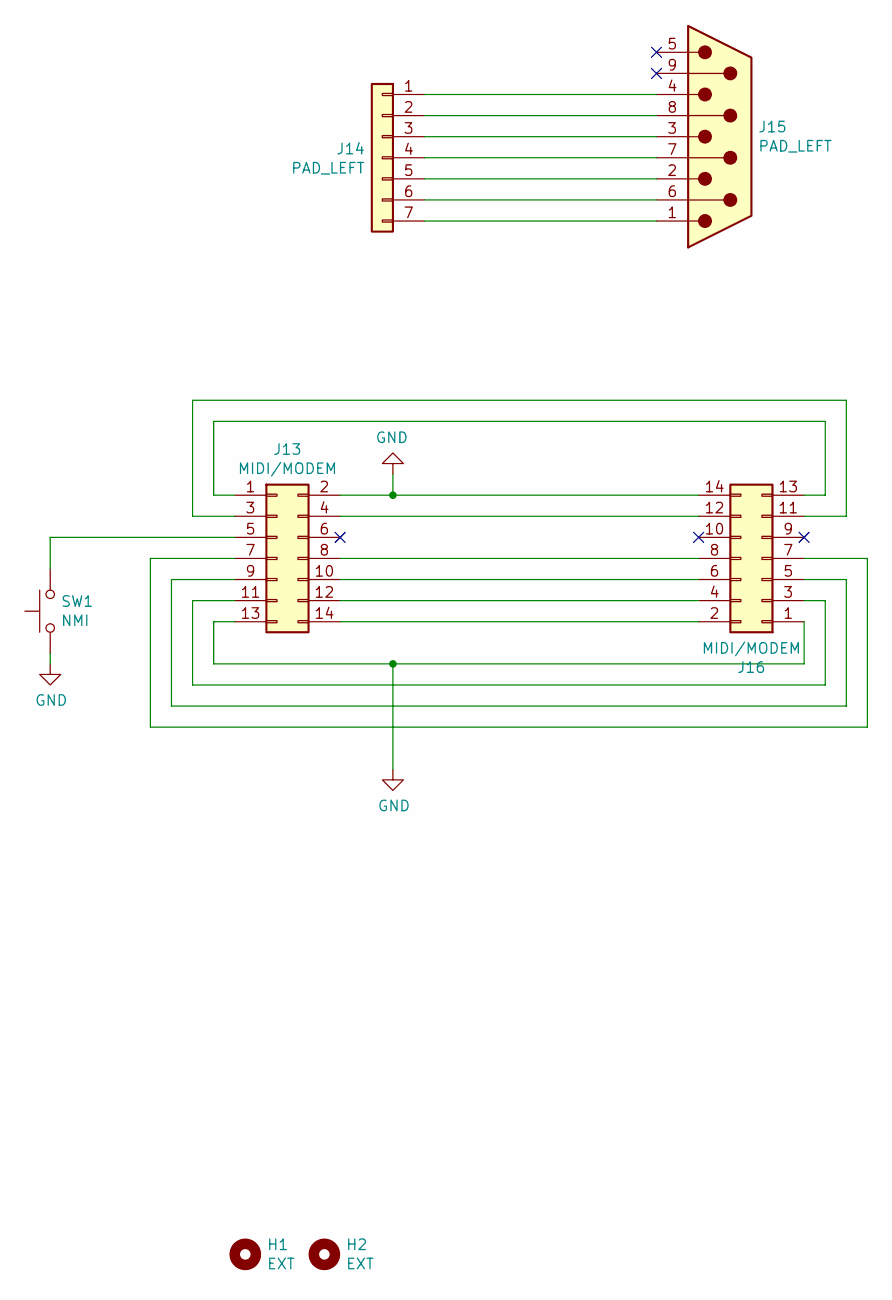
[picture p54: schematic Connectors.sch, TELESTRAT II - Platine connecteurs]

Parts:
H1, H2: EXT; MountingHole_3.2mm_M3_DIN965_Pad
J13: MIDI/MODEM; PinHeader_2x07_P2.54mm_Vertical
J14: PAD_LEFT; PinHeader_1x07_P2.54mm_Vertical
J15: PAD_LEFT; DSUB-9_Male_Horizontal_P2.77x2.84mm_EdgePinOffset8mm_Housed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
J16: MIDI/MODEM; IDC-Header_2x07_P2.54mm_Horizontal
SW1: NMI; SW_Tactile_SPST_Angled_PTS645Vx58-2LFS

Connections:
GND: J13.2, J13.13, J16.1, J16.14, SW1.1
unnamed: J13.1, J16.13
unnamed: J13.3, J16.11
unnamed: J13.4, J16.12
unnamed: J13.5, SW1.2
unnamed: J13.7, J16.7
unnamed: J13.8, J16.8
unnamed: J13.9, J16.5
unnamed: J13.10, J16.6
unnamed: J13.11, J16.3
unnamed: J13.12, J16.4
unnamed: J13.14, J16.2
unnamed: J14.1, J15.4
unnamed: J14.2, J15.8
unnamed: J14.3, J15.3
unnamed: J14.4, J15.7
unnamed: J14.5, J15.2
unnamed: J14.6, J15.6
unnamed: J14.7, J15.1

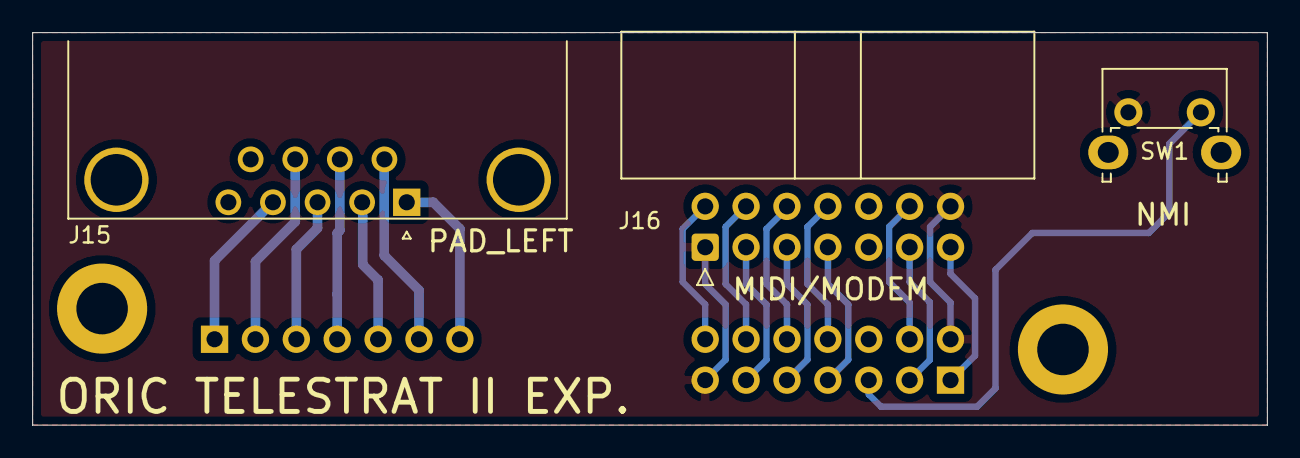
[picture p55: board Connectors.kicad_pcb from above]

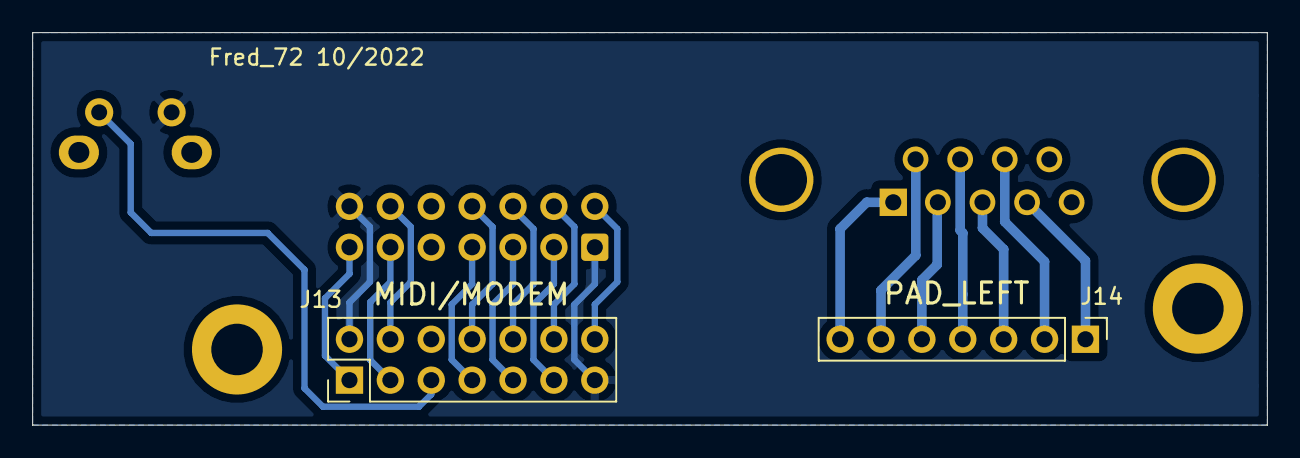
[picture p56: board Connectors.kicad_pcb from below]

Board: 2 copper layers, 76.7 x 24.4 mm, 7 parts (2 on the bottom side), 19 nets.

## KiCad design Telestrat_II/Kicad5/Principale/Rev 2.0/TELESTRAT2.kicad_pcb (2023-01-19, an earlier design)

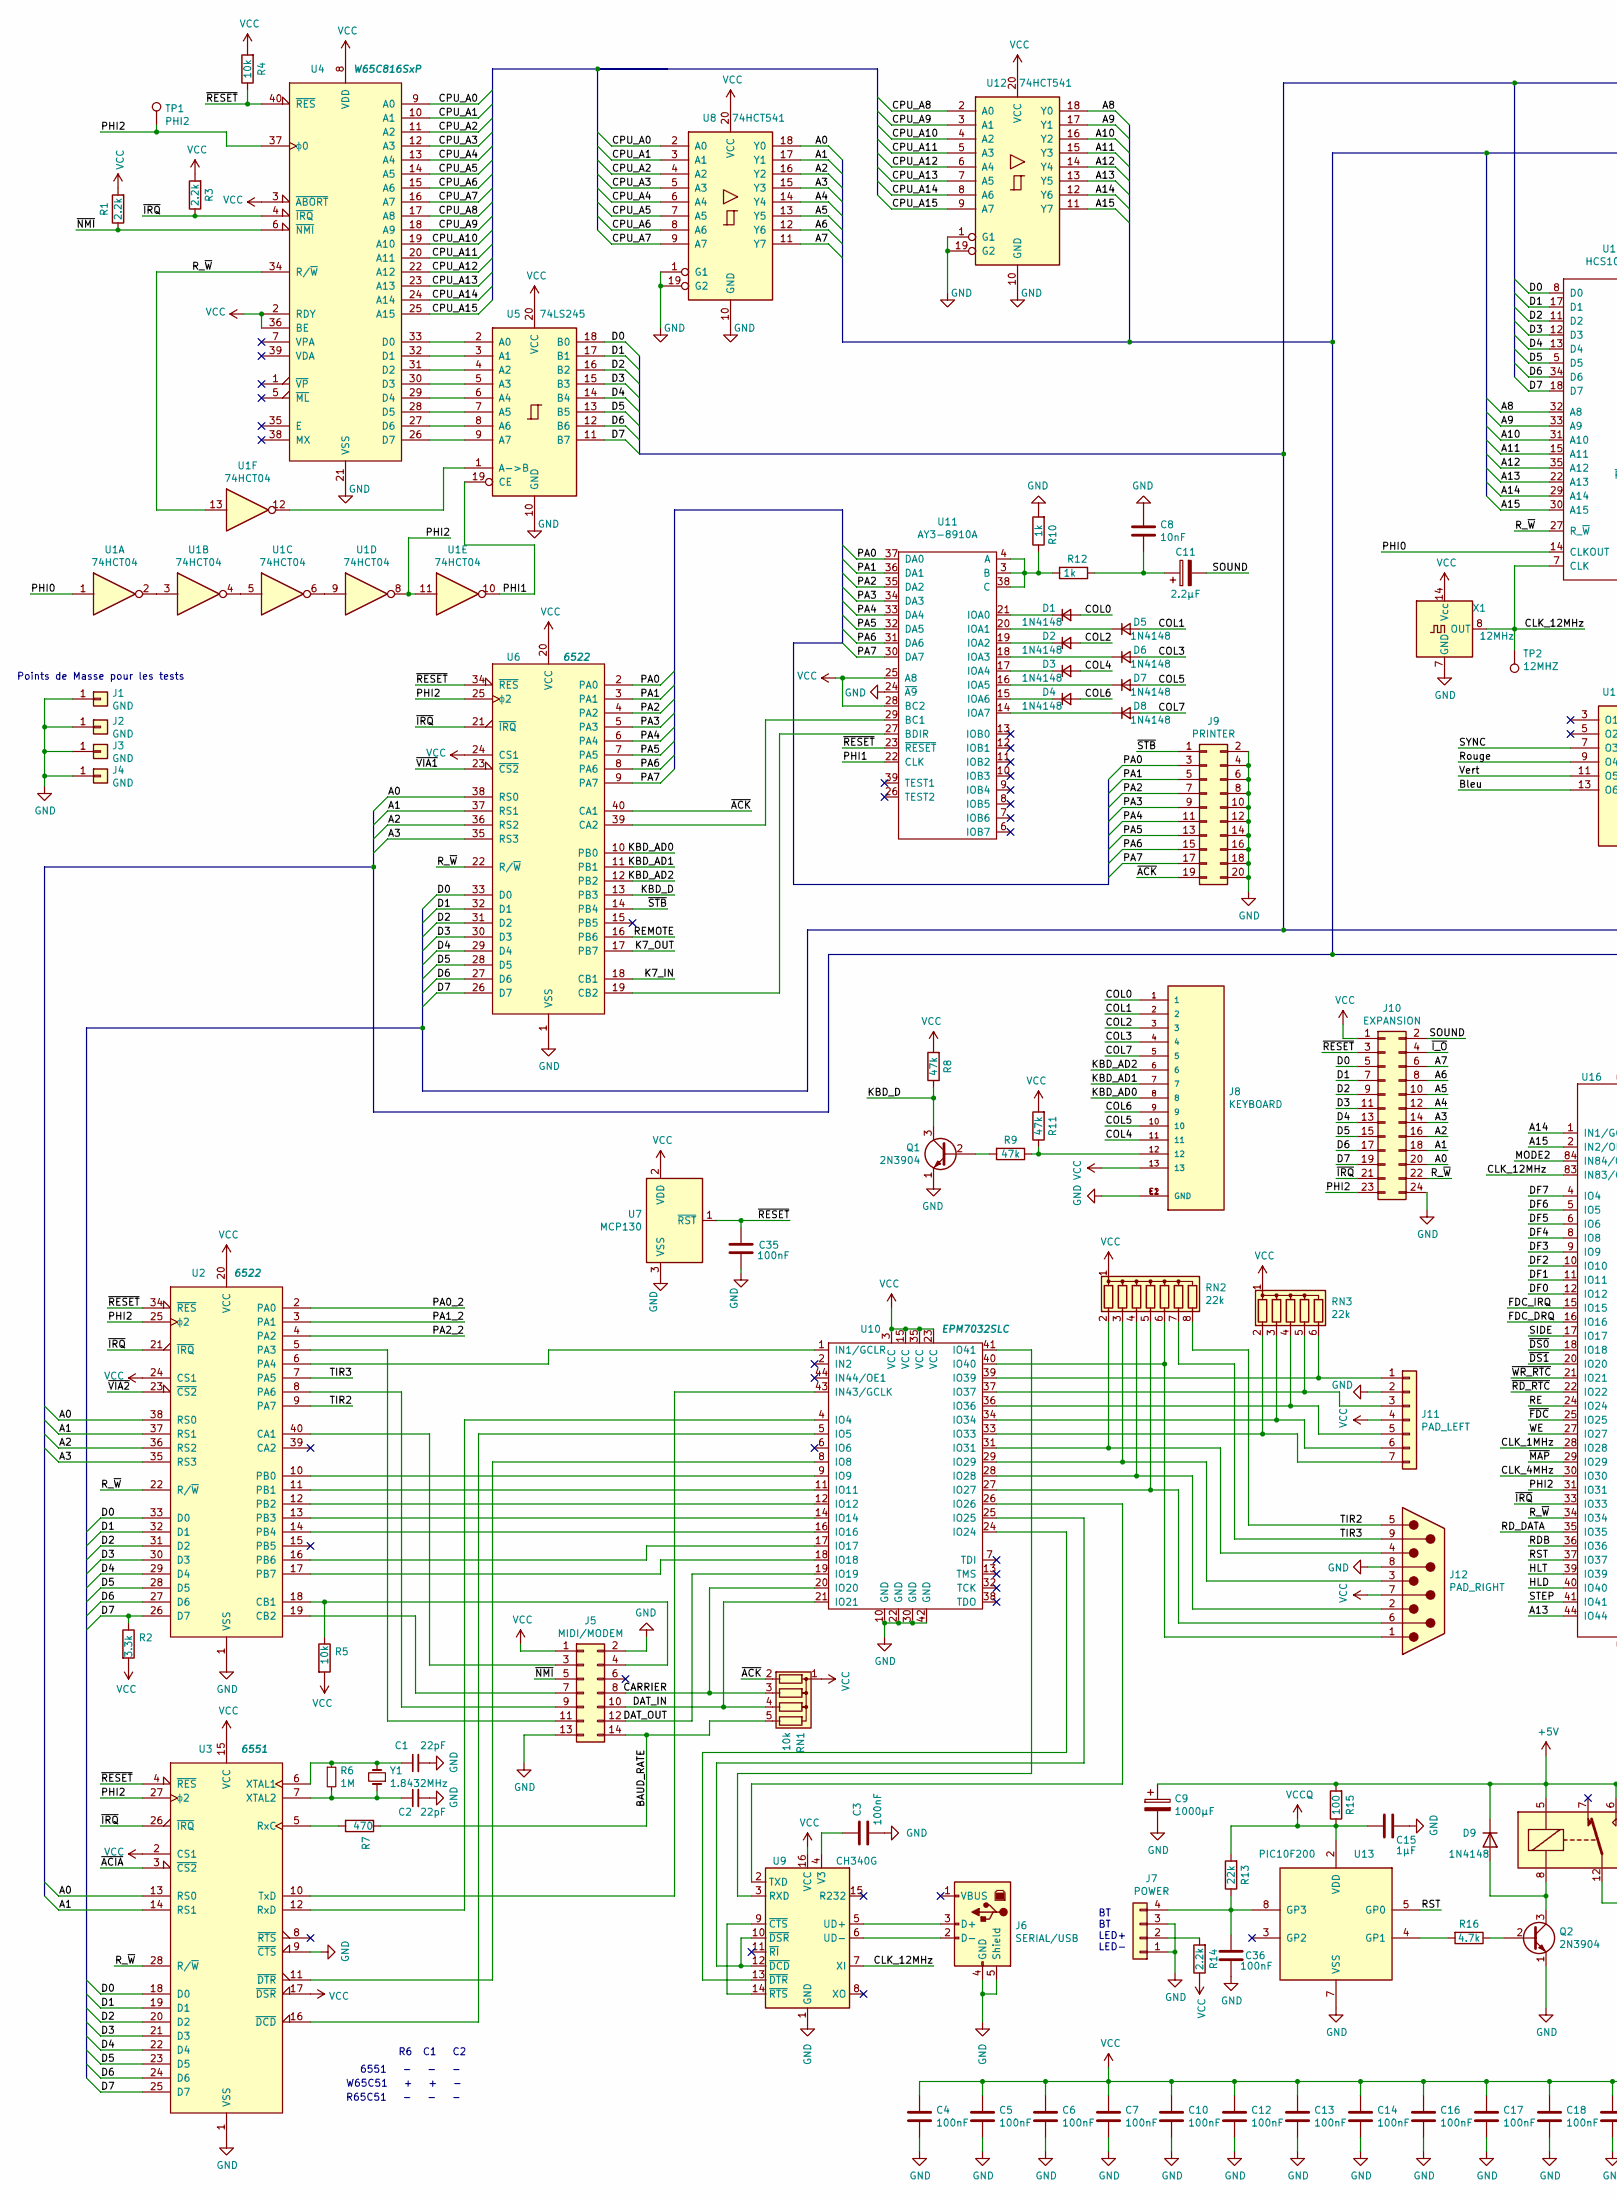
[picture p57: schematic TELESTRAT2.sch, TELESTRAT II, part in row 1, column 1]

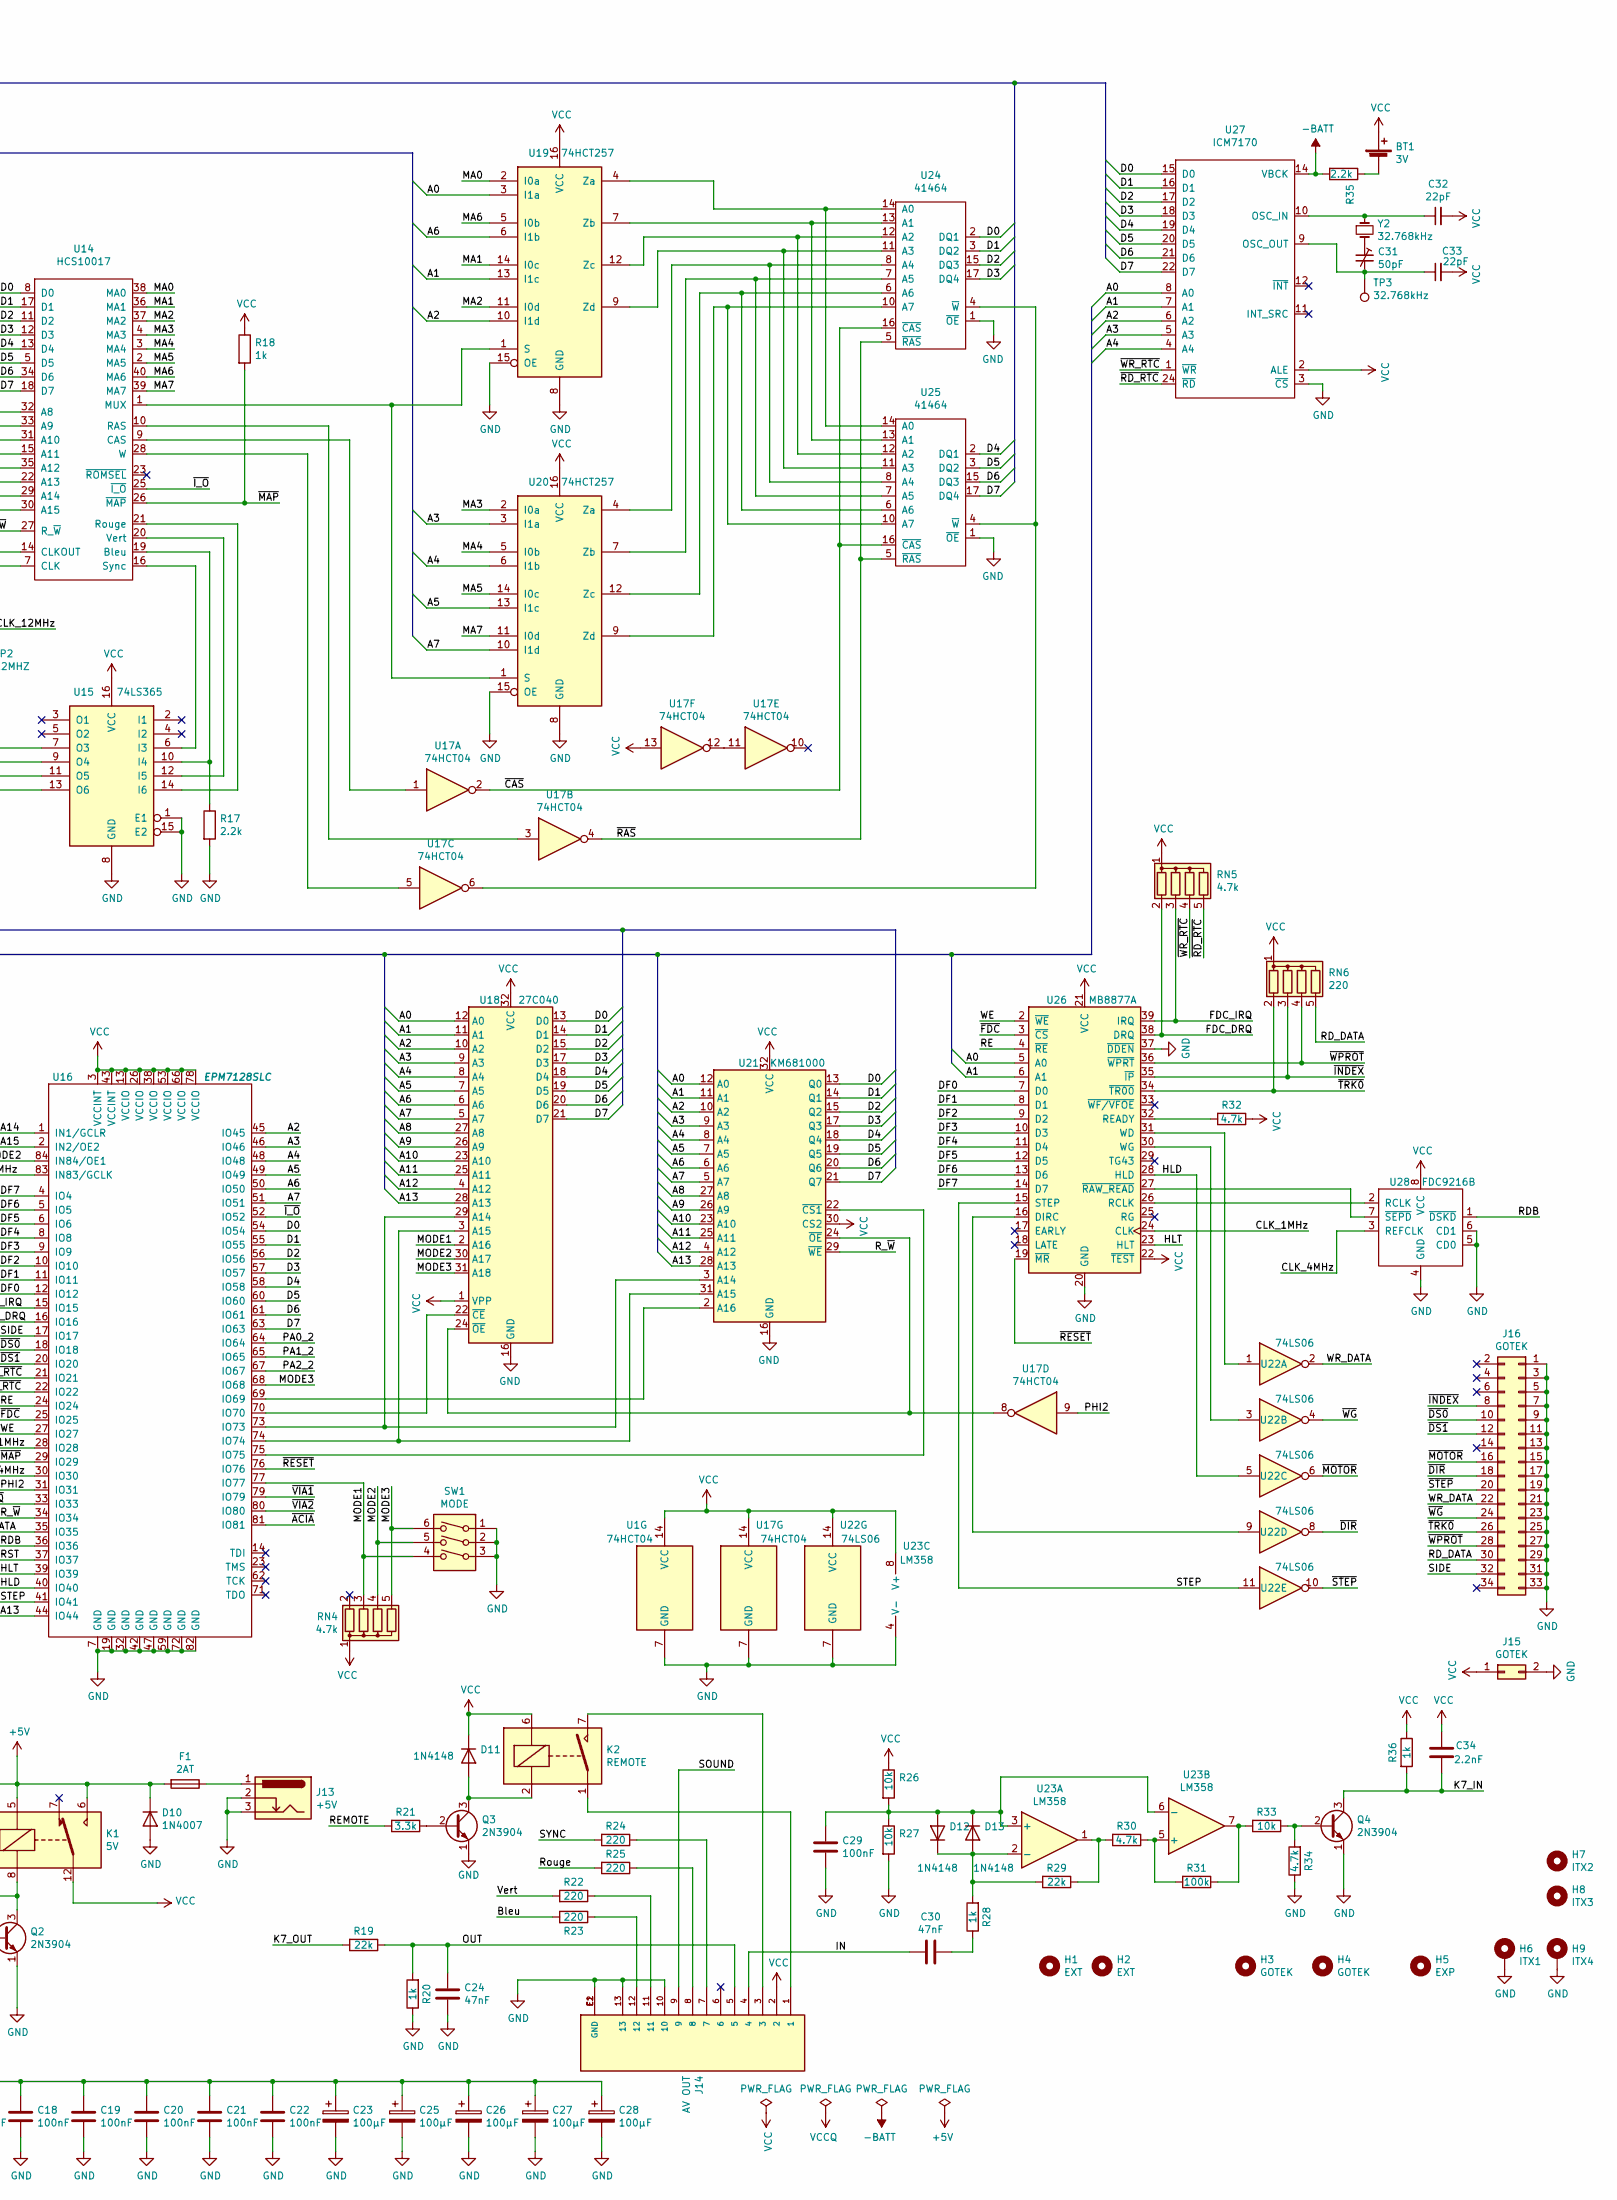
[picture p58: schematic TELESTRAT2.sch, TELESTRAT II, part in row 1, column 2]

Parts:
BT1: 3V; Battery_Holder_Half_Round_CR2032
C1, C2, C32, C33: 22pF; C_Disc_D3.4mm_W2.1mm_P2.50mm
C3, C4, C5, C6, C7, C10, C12, C13, C14, C16, C17, C18, C19, C20, C21, C22, C29, C35, C36: 100nF; C_Rect_L7.0mm_W2.0mm_P5.00mm
C8: 10nF; C_Rect_L7.0mm_W2.0mm_P5.00mm
C9: 1000µF; CP_Radial_D10.0mm_P2.50mm
C11: 2.2µF; CP_Radial_D5.0mm_P2.50mm
C15: 1µF; C_Rect_L7.0mm_W2.0mm_P5.00mm
C23, C25, C26, C27, C28: 100µF; CP_Radial_D5.0mm_P2.50mm
C24, C30: 47nF; C_Rect_L7.0mm_W2.0mm_P5.00mm
C31: 50pF; Trimmer_Cap_TZ03F
C34: 2.2nF; C_Rect_L7.0mm_W2.0mm_P5.00mm
D1, D2, D3, D4, D5, D6, D7, D8, D9, D11, D12, D13: 1N4148; D_DO-35_SOD27_P7.62mm_Horizontal
D10: 1N4007; D_DO-41_SOD81_P5.08mm_Vertical_KathodeUp
F1: 2AT; Fuse_Littelfuse_395Series
H1, H2: EXT; MountingHole_3.2mm_M3_DIN965_Pad
H3, H4: GOTEK; MountingHole_3.2mm_M3_DIN965_Pad
H5: EXP; MountingHole_3.2mm_M3_DIN965_Pad
H6: ITX1; MountingHole_3.2mm_M3_DIN965_Pad
H7: ITX2; MountingHole_3.2mm_M3_DIN965_Pad
H8: ITX3; MountingHole_3.2mm_M3_DIN965_Pad
H9: ITX4; MountingHole_3.2mm_M3_DIN965_Pad
J1, J2, J3, J4: GND; TestPoint_Loop_D2.54mm_Drill1.5mm_Beaded
J5: MIDI/MODEM; PinSocket_2x07_P2.54mm_Vertical
J6: SERIAL/USB; USB_B_Lumberg_2411_02_Horizontal
J7: POWER; PinHeader_1x04_P2.54mm_Vertical
J8: KEYBOARD; DIN-13
J9: PRINTER; IDC-Header_2x10_P2.54mm_Horizontal
J10: EXPANSION; PinSocket_2x12_P2.54mm_Vertical
J11: PAD_LEFT; PinSocket_1x07_P2.54mm_Vertical
J12: PAD_RIGHT; DSUB-9_Male_Horizontal_P2.77x2.84mm_EdgePinOffset8mm_Housed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
J13: +5V; BarrelJack_Horizontal
J14: AV OUT; DIN-13
J15: GOTEK; JST_EH_B2B-EH-A_1x02_P2.50mm_Vertical
J16: GOTEK; IDC-Header_2x17_P2.54mm_Vertical
K1: 5V; Relay_SPDT_HJR-4102
K2: REMOTE; Relay_StandexMeder_DIP_LowProfile
Q1, Q2, Q3, Q4: 2N3904; TO-92L_Inline_Wide
R1, R3, R14, R17, R35: 2.2k; R_Axial_DIN0204_L3.6mm_D1.6mm_P7.62mm_Horizontal
R2, R21: 3.3k; R_Axial_DIN0204_L3.6mm_D1.6mm_P7.62mm_Horizontal
R4, R5, R26, R27, R33: 10k; R_Axial_DIN0204_L3.6mm_D1.6mm_P7.62mm_Horizontal
R6: 1M; R_Axial_DIN0204_L3.6mm_D1.6mm_P7.62mm_Horizontal
R7: 470; R_Axial_DIN0204_L3.6mm_D1.6mm_P7.62mm_Horizontal
R8, R9, R11: 47k; R_Axial_DIN0204_L3.6mm_D1.6mm_P7.62mm_Horizontal
R10, R12, R18, R20, R28, R36: 1k; R_Axial_DIN0204_L3.6mm_D1.6mm_P7.62mm_Horizontal
R13, R19, R29: 22k; R_Axial_DIN0204_L3.6mm_D1.6mm_P7.62mm_Horizontal
R15: 100; R_Axial_DIN0204_L3.6mm_D1.6mm_P7.62mm_Horizontal
R16, R30, R32, R34: 4.7k; R_Axial_DIN0204_L3.6mm_D1.6mm_P7.62mm_Horizontal
R22, R23, R24, R25: 220; R_Axial_DIN0204_L3.6mm_D1.6mm_P7.62mm_Horizontal
R31: 100k; R_Axial_DIN0204_L3.6mm_D1.6mm_P7.62mm_Horizontal
RN1: 10k; R_Array_SIP5
RN2: 22k; R_Array_SIP8
RN3: 22k; R_Array_SIP6
RN4, RN5: 4.7k; R_Array_SIP5
RN6: 220; R_Array_SIP5
SW1: MODE; SW_DIP_SPSTx03_Piano_10.8x9.18mm_W7.62mm_P2.54mm
TP1: PHI2; TestPoint_Pad_1.5x1.5mm
TP2: 12MHZ; TestPoint_Pad_1.5x1.5mm
TP3: 32.768kHz; TestPoint_Pad_1.5x1.5mm
U1, U17: 74HCT04; DIP-14_W7.62mm
U2, U6: 6522; DIP-40_W15.24mm
U3: 6551; DIP-28_W15.24mm
U4: W65C816SxP; DIP-40_W15.24mm
U5: 74LS245; DIP-20_W7.62mm
U7: MCP130; TO-92L_Inline_Wide
U8, U12: 74HCT541; DIP-20_W7.62mm
U9: CH340G; SOIC-16_3.9x9.9mm_P1.27mm
U10: EPM7032SLC; PLCC-44_THT-Socket
U11: AY3-8910A; DIP-40_W15.24mm
U13: PIC10F200; DIP-8_W7.62mm
U14: HCS10017; DIP-40_W15.24mm
U15: 74LS365; DIP-16_W7.62mm
U16: EPM7128SLC; PLCC-84_THT-Socket
U18: 27C040; PLCC-32_THT-Socket
U19, U20: 74HCT257; DIP-16_W7.62mm
U21: KM681000; DIP-32_W15.24mm
U22: 74LS06; DIP-14_W7.62mm
U23: LM358; DIP-8_W7.62mm
U24, U25: 41464; DIP-18_W7.62mm
U26: MB8877A; DIP-40_W15.24mm
U27: ICM7170; DIP-24_W15.24mm
U28: FDC9216B; DIP-8_W7.62mm
X1: 12MHz; Oscillator_DIP-14
Y1: 1.8432MHz; Crystal_HC49-4H_Vertical
Y2: 32.768kHz; Crystal_C38-LF_D3.0mm_L8.0mm_Horizontal

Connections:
+5V: C9.1, D9.1 (K), D10.1 (K), F1.2, K1.5, K1.6, R15.2
-BATT: R35.2, U27.14 (VBCK)
/A0: J10.20, U2.38 (RS0), U3.13 (RS0), U6.38 (RS0), U8.18 (Y0), U18.12 (A0), U19.3 (I1a), U21.12 (A0), U26.5 (A0), U27.8 (A0)
/A1: J10.18, U2.37 (RS1), U3.14 (RS1), U6.37 (RS1), U8.17 (Y1), U18.11 (A1), U19.13 (I1c), U21.11 (A1), U26.6 (A1), U27.7 (A1)
/A2: J10.16, U2.36 (RS2), U6.36 (RS2), U8.16 (Y2), U16.45 (IO45), U18.10 (A2), U19.10 (I1d), U21.10 (A2), U27.6 (A2)
/A3: J10.14, U2.35 (RS3), U6.35 (RS3), U8.15 (Y3), U16.46 (IO46), U18.9 (A3), U20.3 (I1a), U21.9 (A3), U27.5 (A3)
/A4: J10.12, U8.14 (Y4), U16.48 (IO48), U18.8 (A4), U20.6 (I1b), U21.8 (A4), U27.4 (A4)
/A5: J10.10, U8.13 (Y5), U16.49 (IO49), U18.7 (A5), U20.13 (I1c), U21.7 (A5)
/A6: J10.8, U8.12 (Y6), U16.50 (IO50), U18.6 (A6), U19.6 (I1b), U21.6 (A6)
/A7: J10.6, U8.11 (Y7), U16.51 (IO51), U18.5 (A7), U20.10 (I1d), U21.5 (A7)
/A8: U12.18 (Y0), U14.32 (A8), U18.27 (A8), U21.27 (A8)
/A9: U12.17 (Y1), U14.33 (A9), U18.26 (A9), U21.26 (A9)
/A10: U12.16 (Y2), U14.31 (A10), U18.23 (A10), U21.23 (A10)
/A11: U12.15 (Y3), U14.15 (A11), U18.25 (A11), U21.25 (A11)
/A12: U12.14 (Y4), U14.35 (A12), U18.4 (A12), U21.4 (A12)
/A13: U12.13 (Y5), U14.22 (A13), U16.44 (IO44), U18.28 (A13), U21.28 (A13)
/A14: U12.12 (Y6), U14.29 (A14), U16.1 (IN1/GCLR)
/A15: U12.11 (Y7), U14.30 (A15), U16.2 (IN2/OE2)
/BAUD_RATE: J5.14, R7.1, RN1.5 (R4)
/Bleu: R23.2, U15.13 (O6)
/CARRIER: J5.8, RN1.3 (R2), U10.20 (IO20)
/CLK_1MHz: U16.28 (IO28), U26.24 (CLK)
/CLK_4MHz: U16.30 (IO30), U28.3 (REFCLK)
/CLK_12MHz: TP2.1, U9.7 (XI), U14.7 (CLK), U16.83 (IN83/GCLK), X1.8 (OUT)
/COL0: D1.2 (A), J8.1
/COL1: D5.2 (A), J8.2
/COL2: D2.2 (A), J8.3
/COL3: D6.2 (A), J8.4
/COL4: D3.2 (A), J8.11
/COL5: D7.2 (A), J8.10
/COL6: D4.2 (A), J8.9
/COL7: D8.2 (A), J8.5
/CPU_A0: U4.9 (A0), U8.2 (A0)
/CPU_A1: U4.10 (A1), U8.3 (A1)
/CPU_A2: U4.11 (A2), U8.4 (A2)
/CPU_A3: U4.12 (A3), U8.5 (A3)
/CPU_A4: U4.13 (A4), U8.6 (A4)
/CPU_A5: U4.14 (A5), U8.7 (A5)
/CPU_A6: U4.15 (A6), U8.8 (A6)
/CPU_A7: U4.16 (A7), U8.9 (A7)
/CPU_A8: U4.17 (A8), U12.2 (A0)
/CPU_A9: U4.18 (A9), U12.3 (A1)
/CPU_A10: U4.19 (A10), U12.4 (A2)
/CPU_A11: U4.20 (A11), U12.5 (A3)
/CPU_A12: U4.22 (A12), U12.6 (A4)
/CPU_A13: U4.23 (A13), U12.7 (A5)
/CPU_A14: U4.24 (A14), U12.8 (A6)
/CPU_A15: U4.25 (A15), U12.9 (A7)
/D0: J10.5, U2.33 (D0), U3.18 (D0), U5.18 (B0), U6.33 (D0), U14.8 (D0), U16.54 (IO54), U18.13 (D0), U21.13 (Q0), U24.2 (DQ1), U27.15 (D0)
/D1: J10.7, U2.32 (D1), U3.19 (D1), U5.17 (B1), U6.32 (D1), U14.17 (D1), U16.55 (IO55), U18.14 (D1), U21.14 (Q1), U24.3 (DQ2), U27.16 (D1)
/D2: J10.9, U2.31 (D2), U3.20 (D2), U5.16 (B2), U6.31 (D2), U14.11 (D2), U16.56 (IO56), U18.15 (D2), U21.15 (Q2), U24.15 (DQ3), U27.17 (D2)
/D3: J10.11, U2.30 (D3), U3.21 (D3), U5.15 (B3), U6.30 (D3), U14.12 (D3), U16.57 (IO57), U18.17 (D3), U21.17 (Q3), U24.17 (DQ4), U27.18 (D3)
/D4: J10.13, U2.29 (D4), U3.22 (D4), U5.14 (B4), U6.29 (D4), U14.13 (D4), U16.58 (IO58), U18.18 (D4), U21.18 (Q4), U25.2 (DQ1), U27.19 (D4)
/D5: J10.15, U2.28 (D5), U3.23 (D5), U5.13 (B5), U6.28 (D5), U14.5 (D5), U16.60 (IO60), U18.19 (D5), U21.19 (Q5), U25.3 (DQ2), U27.20 (D5)
/D6: J10.17, U2.27 (D6), U3.24 (D6), U5.12 (B6), U6.27 (D6), U14.34 (D6), U16.61 (IO61), U18.20 (D6), U21.20 (Q6), U25.15 (DQ3), U27.21 (D6)
/D7: J10.19, R2.1, U2.26 (D7), U3.25 (D7), U5.11 (B7), U6.26 (D7), U14.18 (D7), U16.63 (IO63), U18.21 (D7), U21.21 (Q7), U25.17 (DQ4), U27.22 (D7)
/DAT_IN: J5.10, RN1.4 (R3), U10.21 (IO21)
/DAT_OUT: J5.12, U10.19 (IO19)
/DF0: U16.12 (IO12), U26.7 (D0)
/DF1: U16.11 (IO11), U26.8 (D1)
/DF2: U16.10 (IO10), U26.9 (D2)
/DF3: U16.9 (IO9), U26.10 (D3)
/DF4: U16.8 (IO8), U26.11 (D4)
/DF5: U16.6 (IO6), U26.12 (D5)
/DF6: U16.5 (IO5), U26.13 (D6)
/DF7: U16.4 (IO4), U26.14 (D7)
/FDC_DRQ: RN5.2 (R1), U16.16 (IO16), U26.38 (DRQ)
/FDC_IRQ: RN5.3 (R2), U16.15 (IO15), U26.39 (IRQ)
/HLD: U16.40 (IO40), U22.5, U26.28 (HLD)
/HLT: U16.39 (IO39), U26.23 (HLT)
/IN: C30.2, J14.4
/K7_IN: C34.1, Q4.3 (C), R36.2, U6.18 (CB1)
/K7_OUT: R19.2, U6.17 (PB7)
/KBD_AD0: J8.8, U6.10 (PB0)
/KBD_AD1: J8.7, U6.11 (PB1)
/KBD_AD2: J8.6, U6.12 (PB2)
/KBD_D: Q1.3 (C), R8.1, U6.13 (PB3)
/MA0: U14.38 (MA0), U19.2 (I0a)
/MA1: U14.36 (MA1), U19.14 (I0c)
/MA2: U14.37 (MA2), U19.11 (I0d)
/MA3: U14.4 (MA3), U20.2 (I0a)
/MA4: U14.3 (MA4), U20.5 (I0b)
/MA5: U14.2 (MA5), U20.14 (I0c)
/MA6: U14.40 (MA6), U19.5 (I0b)
/MA7: U14.39 (MA7), U20.11 (I0d)
/MODE1: RN4.3 (R2), SW1.4, U16.77 (IO77), U18.2 (A16)
/MODE2: RN4.4 (R3), SW1.5, U16.84 (IN84/OE1), U18.30 (A17)
/MODE3: RN4.5 (R4), SW1.6, U16.68 (IO68), U18.31 (A18)
/OUT: C24.1, J14.5, R19.1, R20.2
/PA0: J9.3, U6.2 (PA0), U11.37 (DA0)
/PA0_2: U2.2 (PA0), U16.64 (IO64)
/PA1: J9.5, U6.3 (PA1), U11.36 (DA1)
/PA1_2: U2.3 (PA1), U16.65 (IO65)
/PA2: J9.7, U6.4 (PA2), U11.35 (DA2)
/PA2_2: U2.4 (PA2), U16.67 (IO67)
/PA3: J9.9, U6.5 (PA3), U11.34 (DA3)
/PA4: J9.11, U6.6 (PA4), U11.33 (DA4)
/PA5: J9.13, U6.7 (PA5), U11.32 (DA5)
/PA6: J9.15, U6.8 (PA6), U11.31 (DA6)
/PA7: J9.17, U6.9 (PA7), U11.30 (DA7)
/PHI0: U1.1, U14.14 (CLKOUT)
/PHI1: U1.10, U5.19 (CE), U11.22 (CLK)
/PHI2: J10.23, TP1.1, U1.8, U1.11, U2.25 (ϕ2), U3.27 (ϕ2), U4.37 (ϕ0), U6.25 (ϕ2), U16.31 (IO31), U17.9
/RDB: U16.36 (IO36), U28.1 (~DSKD)
/RD_DATA: J16.30, RN6.5 (R4), U16.35 (IO35)
/RE: U16.24 (IO24), U26.4 (~RE)
/REMOTE: R21.2, U6.16 (PB6)
/RST: U13.5 (GP0), U16.37 (IO37)
/R_~W: J10.22, U1.13, U2.22 (R/~W), U3.28 (R/~W), U4.34 (R/~W), U6.22 (R/~W), U14.27 (R_~W), U16.34 (IO34), U21.29 (~WE)
/Rouge: R25.2, U15.9 (O4)
/SIDE: J16.32, U16.17 (IO17)
/SOUND: C11.2, J10.2, J14.9
/STEP: U16.41 (IO41), U22.11, U26.15 (STEP)
/SYNC: R24.2, U15.7 (O3)
/TIR2: J12.5, RN2.8 (R7), U2.9 (PA7)
/TIR3: J12.9, RN2.7 (R6), U2.7 (PA5)
/Vert: R22.2, U15.11 (O5)
/WE: U16.27 (IO27), U26.2 (~WE)
/WR_DATA: J16.22, U22.2
/~ACIA: U3.3 (~CS2), U16.81 (IO81)
/~ACK: J9.19, RN1.2 (R1), U6.40 (CA1)
/~CAS: U17.2, U24.16 (~CAS), U25.16 (~CAS)
/~DIR: J16.18, U22.8
/~DS0: J16.10, U16.18 (IO18)
/~DS1: J16.12, U16.20 (IO20)
/~FDC: U16.25 (IO25), U26.3 (~CS)
/~INDEX: J16.8, RN6.3 (R2), U26.35 (~IP)
/~IRQ: J10.21, R3.1, U2.21 (~IRQ), U3.26 (~IRQ), U4.4 (~IRQ), U6.21 (~IRQ), U16.33 (IO33)
/~I_O: J10.4, U14.25 (~I_O), U16.52 (IO52)
/~MAP: R18.2, U14.26 (~MAP), U16.29 (IO29)
/~MOTOR: J16.16, U22.6
/~NMI: J5.5, R1.1, U4.6 (~NMI)
/~RAS: U17.4, U24.5 (~RAS), U25.5 (~RAS)
/~RD_RTC: RN5.5 (R4), U16.22 (IO22), U27.24 (~RD)
/~RESET: C35.2, J10.3, R4.1, U2.34 (~RES), U3.4 (~RES), U4.40 (~RES), U6.34 (~RES), U7.1 (~RST), U11.23 (~RESET), U16.76 (IO76), U26.19 (~MR)
/~STB: J9.1, U6.14 (PB4)
/~STEP: J16.20, U22.10
/~TRK0: J16.26, RN6.2 (R1), U26.34 (~TR00)
/~VIA1: U6.23 (~CS2), U16.79 (IO79)
/~VIA2: U2.23 (~CS2), U16.80 (IO80)
/~WG: J16.24, U22.4
/~WPROT: J16.28, RN6.4 (R3), U26.36 (~WPRT)
/~WR_RTC: RN5.4 (R3), U16.21 (IO21), U27.1 (~WR)
GND: C1.2, C2.2, C3.2, C4.2, C5.2, C6.2, C7.2, C8.1, C9.2, C10.2, C12.2, C13.2, C14.2, C15.1, C16.2, C17.2, C18.2, C19.2, C20.2, C21.2, C22.2, C23.2, C24.2, C25.2, C26.2, C27.2, C28.2, C29.2, C35.1, C36.1, D10.2 (A), H6.1, H9.1, J1.1, J2.1, J3.1, J4.1, J5.2, J5.13, J6.4 (GND), J6.5 (Shield), J7.1, J7.3, J8.E1 (GND), J8.E2 (GND), J9.2, J9.4, J9.6, J9.8, J9.10, J9.12, J9.14, J9.16, J9.18, J9.20, J10.24, J11.2, J12.8, J13.2, J13.3, J14.10, J14.13, J14.E1 (GND), J14.E2 (GND), J15.2, J16.1, J16.3, J16.5, J16.7, J16.9, J16.11, J16.13, J16.15, J16.17, J16.19, J16.21, J16.23, J16.25, J16.27, J16.29, J16.31, J16.33, Q1.1 (E), Q2.1 (E), Q3.1 (E), Q4.1 (E), R10.2, R17.2, R20.1, R27.2, R34.1, SW1.1, SW1.2, SW1.3, U1.7 (GND), U2.1 (VSS), U3.1 (VSS), U3.9 (~CTS), U4.21 (VSS), U5.10 (GND), U6.1 (VSS), U7.3 (VSS), U8.1 (G1), U8.10 (GND), U8.19 (G2), U9.1 (GND), U10.10 (GND), U10.22 (GND), U10.30 (GND), U10.42 (GND), U11.1 (GND), U11.24 (~A9), U12.1 (G1), U12.10 (GND), U12.19 (G2), U13.7 (VSS), U14.6 (GND), U15.1 (E1), U15.8 (GND), U15.15 (E2), U16.7 (GND), U16.19 (GND), U16.32 (GND), U16.42 (GND), U16.47 (GND), U16.59 (GND), U16.72 (GND), U16.82 (GND), U17.7 (GND), U18.16 (GND), U19.8 (GND), U19.15 (OE), U20.8 (GND), U20.15 (OE), U21.16 (GND), U22.7 (GND), U23.4 (V-), U24.1 (~OE), U24.18 (GND), U25.1 (~OE), U25.18 (GND), U26.20 (GND), U26.37 (~DDEN), U27.3 (~CS), U27.13 (GND), U28.4 (GND), U28.5 (CD0), U28.6 (CD1), X1.7 (GND)
unnamed: BT1.2 (-), R35.1
unnamed: C1.1, R6.1, U3.6 (XTAL1), Y1.2
unnamed: C2.1, R6.2, U3.7 (XTAL2), Y1.1
unnamed: C3.1, U9.4 (V3)
unnamed: C8.2, C11.1, R12.1
unnamed: C29.1, D12.2 (A), D13.1 (K), R26.2, R27.1, U23.3 (+), U23.6 (-)
unnamed: C30.1, R28.1
unnamed: C31.1, Y2.2
unnamed: C31.2, C33.1, TP3.1, U27.9 (OSC_OUT)
unnamed: C32.1, U27.10 (OSC_IN), Y2.1
unnamed: C36.2, J7.4, R13.1, U13.8 (GP3)
unnamed: D1.1 (K), U11.21 (IOA0)
unnamed: D2.1 (K), U11.19 (IOA2)
unnamed: D3.1 (K), U11.17 (IOA4)
unnamed: D4.1 (K), U11.15 (IOA6)
unnamed: D5.1 (K), U11.20 (IOA1)
unnamed: D6.1 (K), U11.18 (IOA3)
unnamed: D7.1 (K), U11.16 (IOA5)
unnamed: D8.1 (K), U11.14 (IOA7)
unnamed: D9.2 (A), K1.8, Q2.3 (C)
unnamed: D11.2 (A), K2.2, Q3.3 (C)
unnamed: D12.1 (K), D13.2 (A), R28.2, R29.2, U23.2 (-)
unnamed: F1.1, J13.1
unnamed: J5.3, U2.40 (CA1)
unnamed: J5.4, R5.1, U2.18 (CB1)
unnamed: J5.7, U2.19 (CB2)
unnamed: J5.9, U2.8 (PA6)
unnamed: J5.11, U2.5 (PA3)
unnamed: J6.2 (D-), U9.6 (UD-)
unnamed: J6.3 (D+), U9.5 (UD+)
unnamed: J7.2, R14.2
unnamed: J8.12, R9.1, R11.1
unnamed: J11.1, RN3.6 (R5), U10.39 (IO39)
unnamed: J11.3, RN3.5 (R4), U10.37 (IO37)
unnamed: J11.5, RN3.4 (R3), U10.36 (IO36)
unnamed: J11.6, RN3.3 (R2), U10.34 (IO34)
unnamed: J11.7, RN3.2 (R1), U10.33 (IO33)
unnamed: J12.1, RN2.6 (R5), U10.40 (IO40)
unnamed: J12.2, RN2.4 (R3), U10.28 (IO28)
unnamed: J12.3, RN2.3 (R2), U10.29 (IO29)
unnamed: J12.4, RN2.2 (R1), U10.31 (IO31)
unnamed: J12.6, RN2.5 (R4), U10.27 (IO27)
unnamed: J14.1, K2.1, K2.14
unnamed: J14.3, K2.7, K2.8
unnamed: J14.7, R24.1
unnamed: J14.8, R25.1
unnamed: J14.11, R22.1
unnamed: J14.12, R23.1
unnamed: Q1.2 (B), R9.2
unnamed: Q2.2 (B), R16.1
unnamed: Q3.2 (B), R21.1
unnamed: Q4.2 (B), R33.1, R34.2
unnamed: R7.2, U3.5 (RxC)
unnamed: R10.1, R12.2, U11.3 (B), U11.4 (A), U11.38 (C)
unnamed: R16.2, U13.4 (GP1)
unnamed: R17.1, U14.19 (Bleu), U15.10 (I4)
unnamed: R29.1, R30.2, U23.1
unnamed: R30.1, R31.2, U23.5 (+)
unnamed: R31.1, R33.2, U23.7
unnamed: R32.2, U26.32 (READY)
unnamed: U1.2, U1.3
unnamed: U1.4, U1.5
unnamed: U1.6, U1.9
unnamed: U1.12, U5.1 (A->B)
unnamed: U4.26 (D7), U5.9 (A7)
unnamed: U4.27 (D6), U5.8 (A6)
unnamed: U4.28 (D5), U5.7 (A5)
unnamed: U4.29 (D4), U5.6 (A4)
unnamed: U4.30 (D3), U5.5 (A3)
unnamed: U4.31 (D2), U5.4 (A2)
unnamed: U4.32 (D1), U5.3 (A1)
unnamed: U4.33 (D0), U5.2 (A0)
unnamed: U9.9 (~CTS), U9.14 (~RTS)
unnamed: U2.6 (PA4), U10.1 (IN1/GCLR)
unnamed: U3.12 (RxD), U10.4 (IO4)
unnamed: U3.16 (~DCD), U10.5 (IO5)
unnamed: U3.11 (~DTR), U10.8 (IO8)
unnamed: U2.10 (PB0), U10.9 (IO9)
unnamed: U2.11 (PB1), U10.11 (IO11)
unnamed: U2.12 (PB2), U10.12 (IO12)
unnamed: U2.13 (PB3), U10.14 (IO14)
unnamed: U2.14 (PB4), U10.16 (IO16)
unnamed: U2.16 (PB6), U10.17 (IO17)
unnamed: U2.17 (PB7), U10.18 (IO18)
unnamed: U9.13 (~DTR), U10.24 (IO24)
unnamed: U9.10 (~DSR), U9.12 (~DCD), U10.25 (IO25)
unnamed: U9.2 (TXD), U10.26 (IO26)
unnamed: U9.3 (RXD), U10.41 (IO41)
unnamed: U3.10 (TxD), U10.43 (IN43/GCLK)
unnamed: U6.19 (CB2), U11.27 (BDIR)
unnamed: U6.39 (CA2), U11.29 (BC1)
unnamed: U14.1 (MUX), U19.1 (S), U20.1 (S)
unnamed: U14.9 (CAS), U17.1
unnamed: U14.10 (RAS), U17.3
unnamed: U14.16 (Sync), U15.6 (I3)
unnamed: U14.20 (Vert), U15.12 (I5)
unnamed: U14.21 (Rouge), U15.14 (I6)
unnamed: U14.28 (W), U17.5
unnamed: U16.69 (IO69), U21.2 (A16)
unnamed: U16.70 (IO70), U18.22 (~CE)
unnamed: U16.73 (IO73), U18.29 (A14), U21.3 (A14)
unnamed: U16.74 (IO74), U18.3 (A15), U21.31 (A15)
unnamed: U16.75 (IO75), U21.22 (~CS1)
unnamed: U17.6, U24.4 (~W), U25.4 (~W)
unnamed: U17.8, U18.24 (~OE), U21.24 (~OE)
unnamed: U17.11, U17.12
unnamed: U19.4 (Za), U24.14 (A0), U25.14 (A0)
unnamed: U19.7 (Zb), U24.13 (A1), U25.13 (A1)
unnamed: U19.9 (Zd), U24.11 (A3), U25.11 (A3)
unnamed: U19.12 (Zc), U24.12 (A2), U25.12 (A2)
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

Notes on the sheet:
BT BT LED+ LED-
Points de Masse pour les tests
R6 C1 C2
6551 - - -
W65C51 + + -
R65C51 - - -

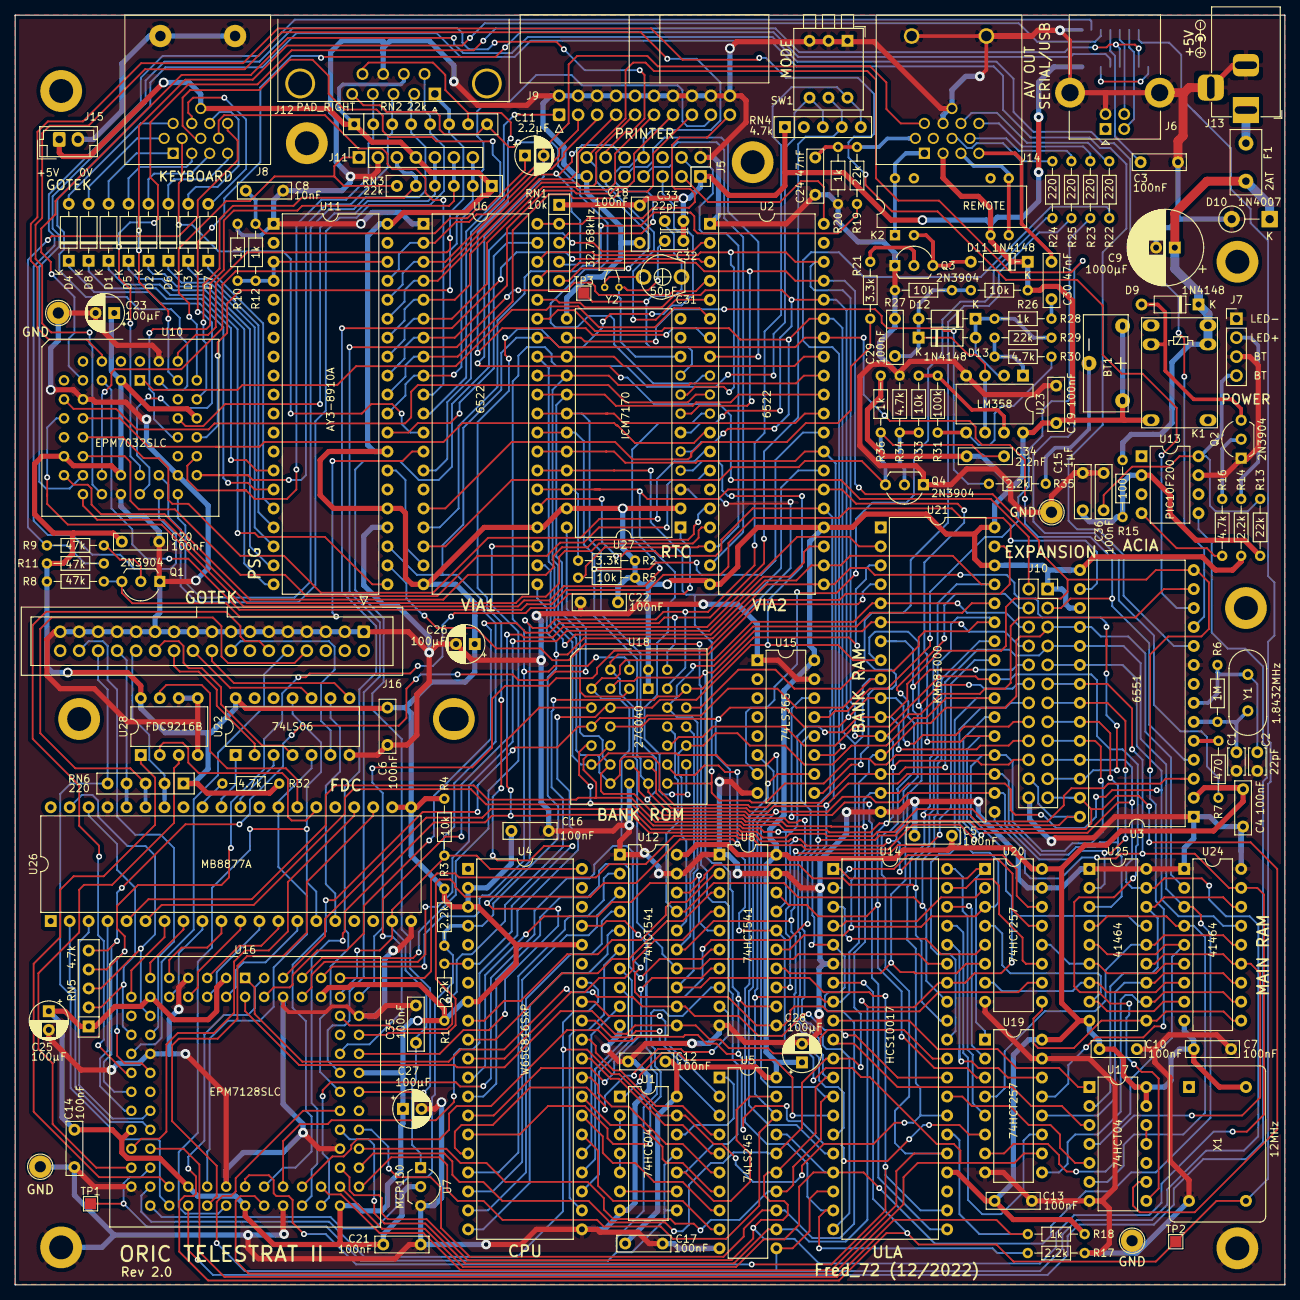
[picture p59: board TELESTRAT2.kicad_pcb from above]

Board: 2 copper layers, 170.0 x 170.0 mm, 159 parts (1 on the bottom side), 265 nets.

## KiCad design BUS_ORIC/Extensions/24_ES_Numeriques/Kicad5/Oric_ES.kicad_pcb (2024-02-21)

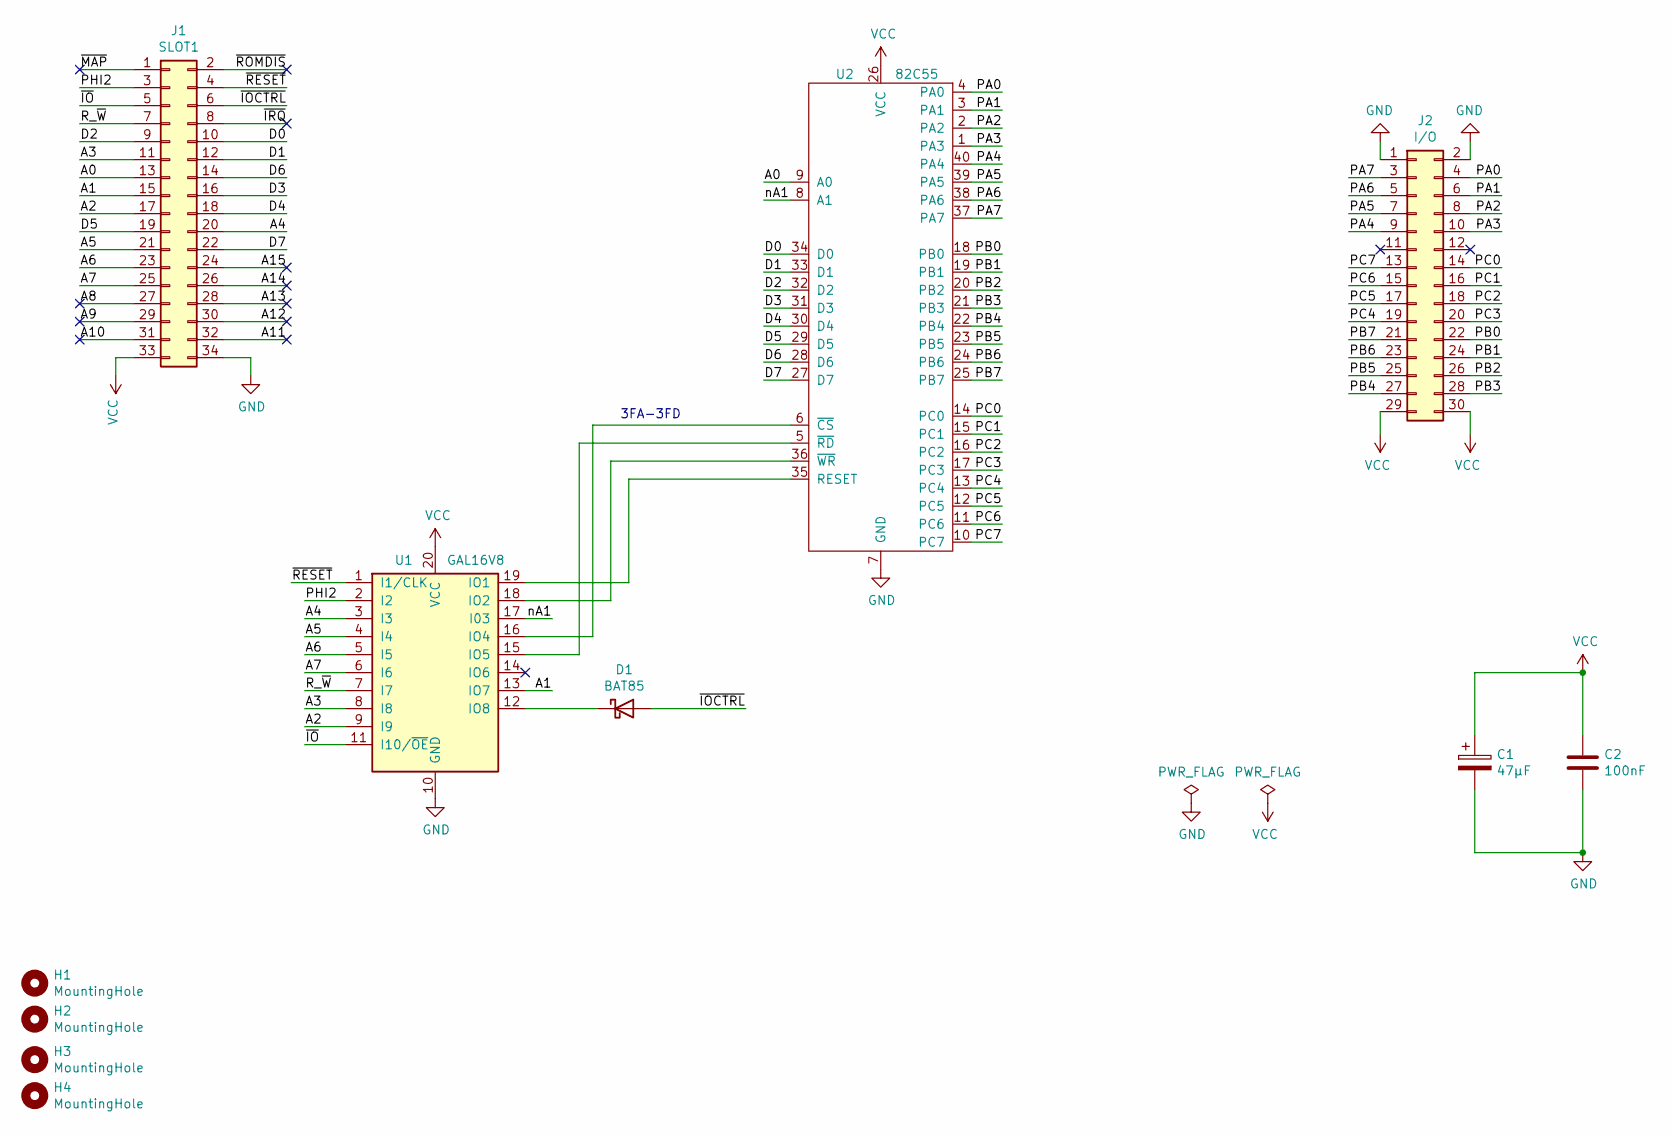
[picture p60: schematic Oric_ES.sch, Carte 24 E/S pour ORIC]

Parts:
C1: 47µF; CP_Radial_D5.0mm_P2.54mm_Horizontal
C2: 100nF; C_Ceramic_D5.5mm_W4mm_P5.00mm
D1: BAT85; D_DO-35_SOD27_P7.62mm_Horizontal
H1, H2, H3, H4: MountingHole; MountingHole_3.2mm_M3_DIN965_Pad
J1: SLOT1; IDC-Header_2x17_P2.54mm_Horizontal
J2: I/O; IDC-Header_2x15_P2.54mm_Horizontal
U1: GAL16V8; DIP-20_W7.62mm_LongPads
U2: 82C55; DIP-40_W15.24mm_LongPads

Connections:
/A0: J1.13, U2.9 (A0)
/A1: J1.15, U1.13 (IO7)
/A2: J1.17, U1.9 (I9)
/A3: J1.11, U1.8 (I8)
/A4: J1.20, U1.3 (I3)
/A5: J1.21, U1.4 (I4)
/A6: J1.23, U1.5 (I5)
/A7: J1.25, U1.6 (I6)
/A8: J1.27
/A9: J1.29
/A10: J1.31
/A11: J1.32
/A12: J1.30
/A13: J1.28
/A14: J1.26
/A15: J1.24
/D0: J1.10, U2.34 (D0)
/D1: J1.12, U2.33 (D1)
/D2: J1.9, U2.32 (D2)
/D3: J1.16, U2.31 (D3)
/D4: J1.18, U2.30 (D4)
/D5: J1.19, U2.29 (D5)
/D6: J1.14, U2.28 (D6)
/D7: J1.22, U2.27 (D7)
/PA0: J2.4, U2.4 (PA0)
/PA1: J2.6, U2.3 (PA1)
/PA2: J2.8, U2.2 (PA2)
/PA3: J2.10, U2.1 (PA3)
/PA4: J2.9, U2.40 (PA4)
/PA5: J2.7, U2.39 (PA5)
/PA6: J2.5, U2.38 (PA6)
/PA7: J2.3, U2.37 (PA7)
/PB0: J2.22, U2.18 (PB0)
/PB1: J2.24, U2.19 (PB1)
/PB2: J2.26, U2.20 (PB2)
/PB3: J2.28, U2.21 (PB3)
/PB4: J2.27, U2.22 (PB4)
/PB5: J2.25, U2.23 (PB5)
/PB6: J2.23, U2.24 (PB6)
/PB7: J2.21, U2.25 (PB7)
/PC0: J2.14, U2.14 (PC0)
/PC1: J2.16, U2.15 (PC1)
/PC2: J2.18, U2.16 (PC2)
/PC3: J2.20, U2.17 (PC3)
/PC4: J2.19, U2.13 (PC4)
/PC5: J2.17, U2.12 (PC5)
/PC6: J2.15, U2.11 (PC6)
/PC7: J2.13, U2.10 (PC7)
/PHI2: J1.3, U1.2 (I2)
/R_~W: J1.7, U1.7 (I7)
/nA1: U1.17 (I03), U2.8 (A1)
/~IO: J1.5, U1.11 (I10/~OE~)
/~IOCTRL: D1.2 (A), J1.6
/~IRQ: J1.8
/~MAP: J1.1
/~RESET: J1.4, U1.1 (I1/CLK)
/~ROMDIS: J1.2
GND: C1.2, C2.2, J1.34, J2.1, J2.2, U1.10 (GND), U2.7 (GND)
unnamed: D1.1 (K), U1.12 (IO8)
unnamed: U1.15 (IO5), U2.5 (~RD)
unnamed: U1.16 (IO4), U2.6 (~CS)
unnamed: U1.18 (IO2), U2.36 (~WR)
unnamed: U1.19 (IO1), U2.35 (RESET)
VCC: C1.1, C2.1, J1.33, J2.29, J2.30, U1.20 (VCC), U2.26 (VCC)

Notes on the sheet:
3FA-3FD

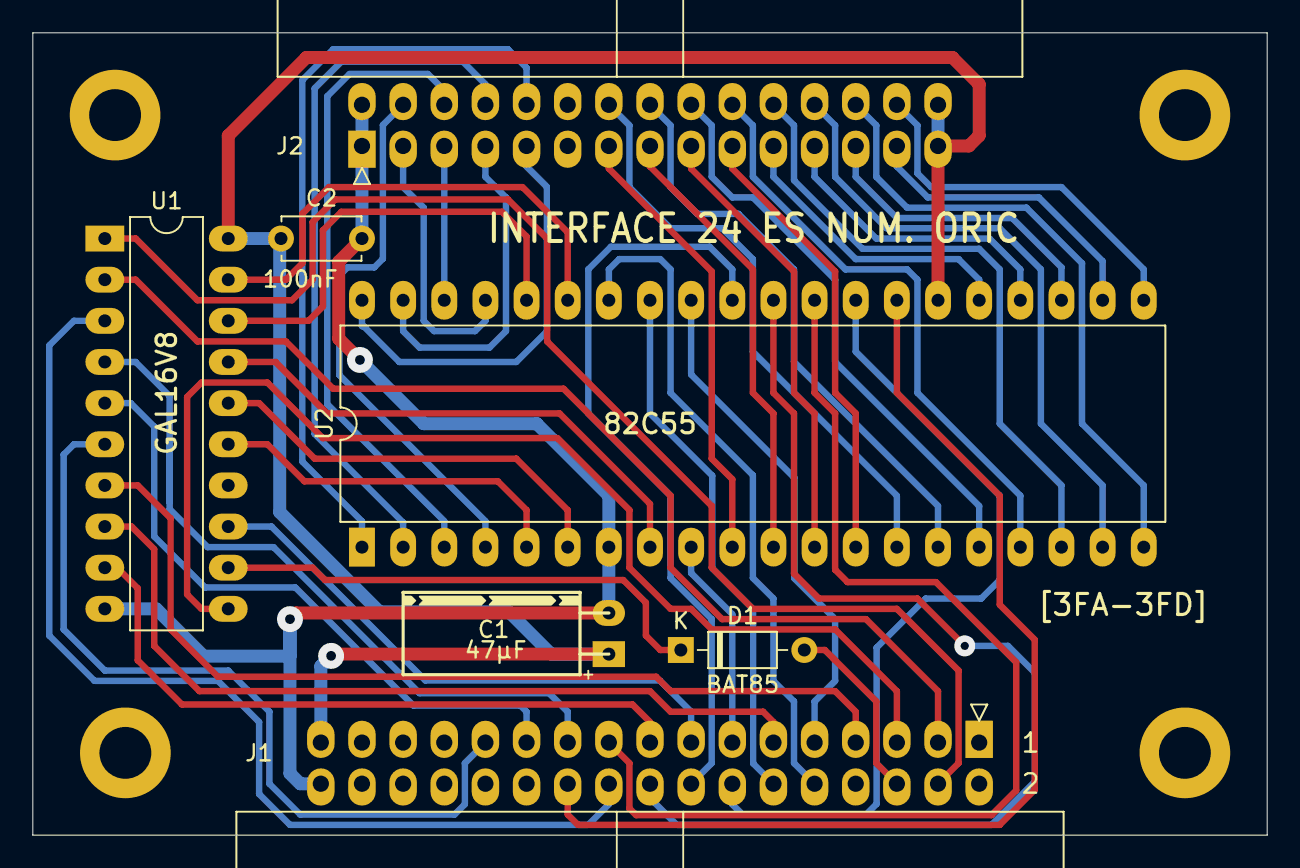
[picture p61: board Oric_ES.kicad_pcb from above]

Board: 2 copper layers, 76.2 x 49.5 mm, 11 parts (0 on the bottom side), 53 nets.

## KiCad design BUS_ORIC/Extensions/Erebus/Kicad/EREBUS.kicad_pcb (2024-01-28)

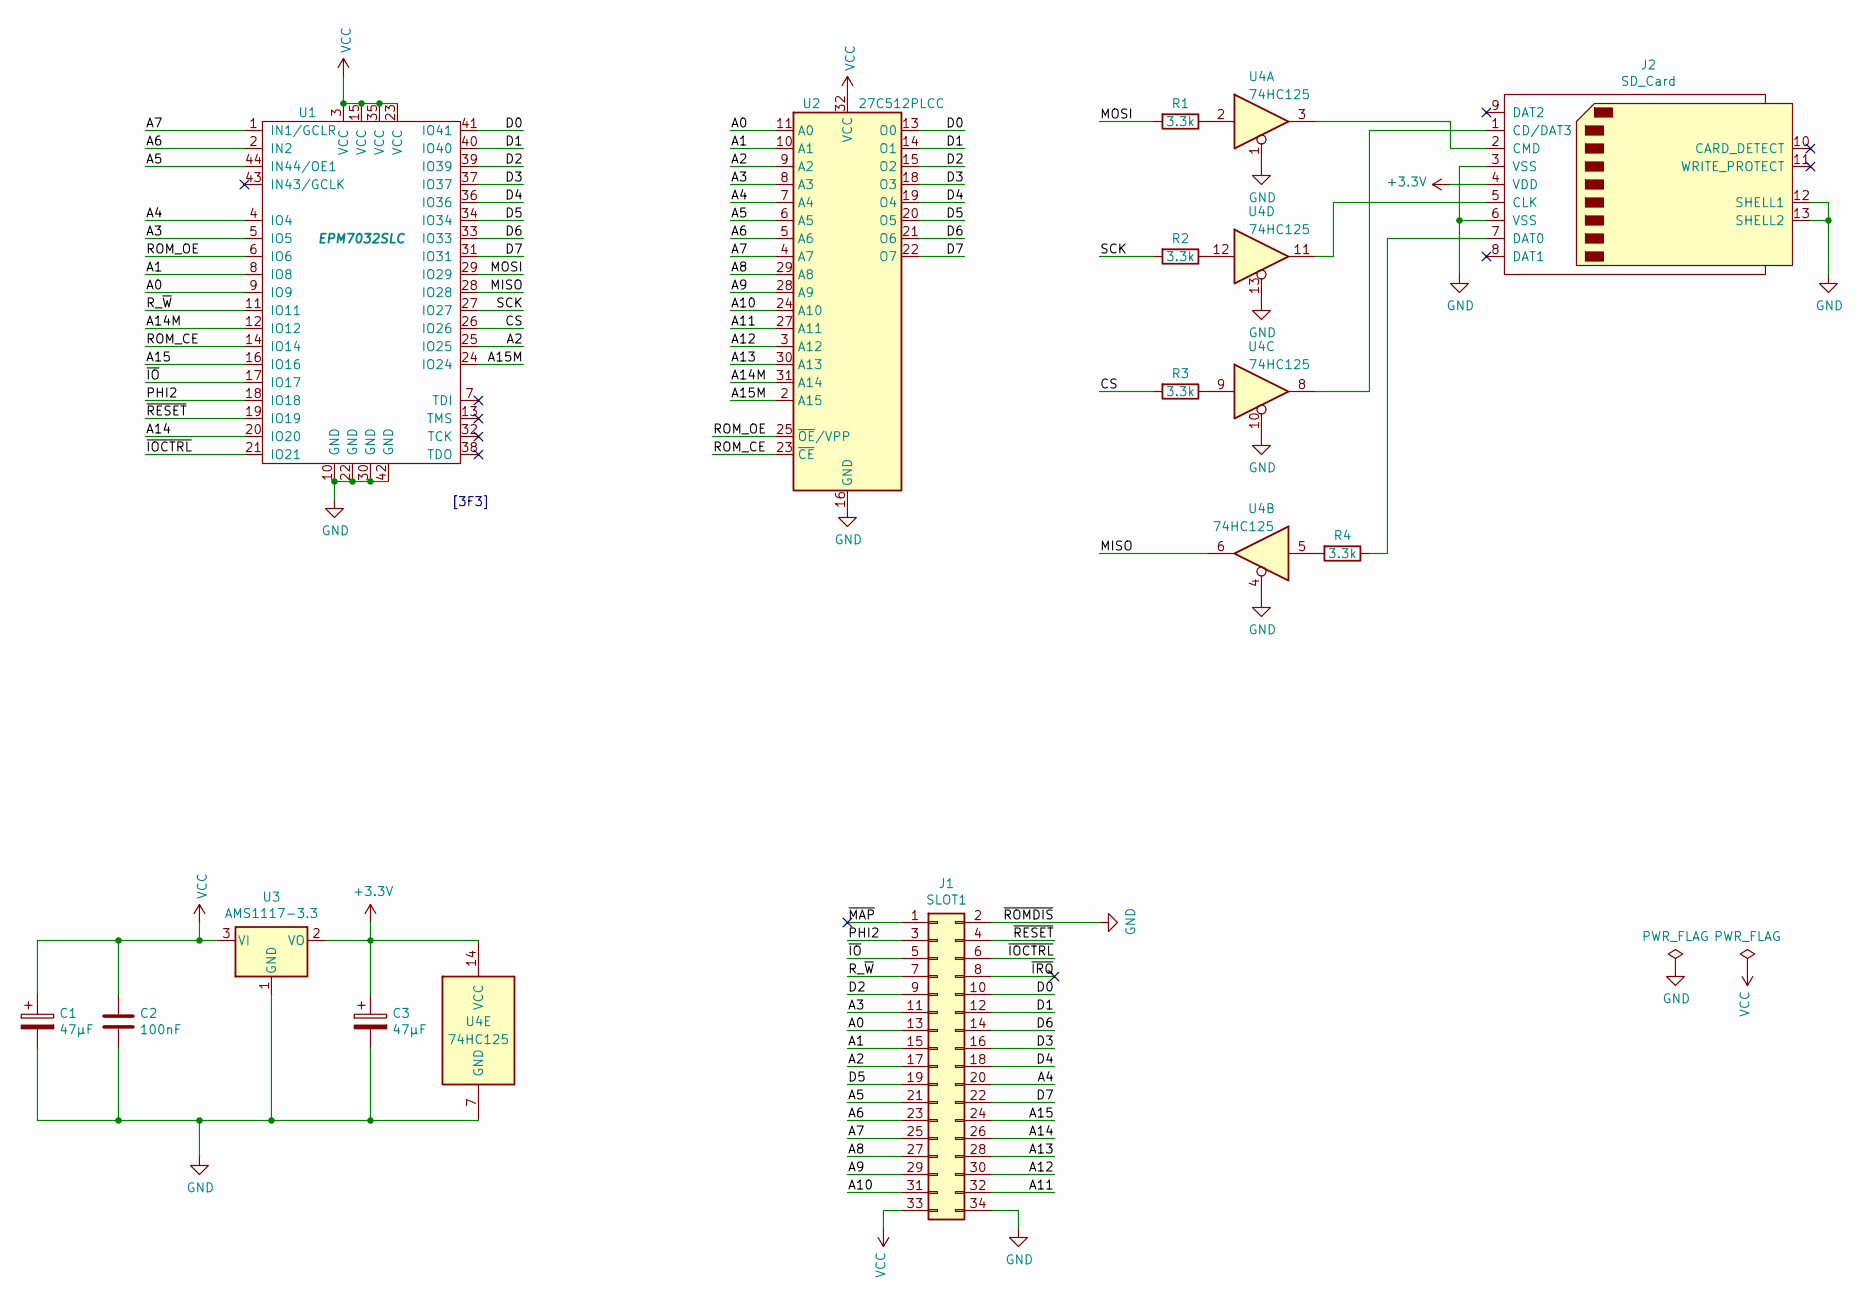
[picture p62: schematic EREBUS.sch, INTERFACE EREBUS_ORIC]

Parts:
C1, C3: 47µF; CP_Radial_D5.0mm_P2.00mm
C2: 100nF; C_Rect_L7.0mm_W2.0mm_P5.00mm
J1: SLOT1; IDC-Header_2x17_P2.54mm_Horizontal
J2: SD_Card; SD_Short
R1, R2, R3, R4: 3.3k; R_0805_2012Metric
U1: EPM7032SLC; PLCC-44_THT-Socket
U2: 27C512PLCC; PLCC-32_THT-Socket
U3: AMS1117-3.3; SOT-223-3_TabPin2
U4: 74HC125; SOIC-14_3.9x8.7mm_P1.27mm

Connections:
+3V3: C3.1, J2.4 (VDD), U3.2 (VO), U4.14 (VCC)
/A0: J1.13, U1.9 (IO9), U2.11 (A0)
/A1: J1.15, U1.8 (IO8), U2.10 (A1)
/A2: J1.17, U1.25 (IO25), U2.9 (A2)
/A3: J1.11, U1.5 (IO5), U2.8 (A3)
/A4: J1.20, U1.4 (IO4), U2.7 (A4)
/A5: J1.21, U1.44 (IN44/OE1), U2.6 (A5)
/A6: J1.23, U1.2 (IN2), U2.5 (A6)
/A7: J1.25, U1.1 (IN1/GCLR), U2.4 (A7)
/A8: J1.27, U2.29 (A8)
/A9: J1.29, U2.28 (A9)
/A10: J1.31, U2.24 (A10)
/A11: J1.32, U2.27 (A11)
/A12: J1.30, U2.3 (A12)
/A13: J1.28, U2.30 (A13)
/A14: J1.26, U1.20 (IO20)
/A14M: U1.12 (IO12), U2.31 (A14)
/A15: J1.24, U1.16 (IO16)
/A15M: U1.24 (IO24), U2.2 (A15)
/CS: R3.2, U1.26 (IO26)
/D0: J1.10, U1.41 (IO41), U2.13 (O0)
/D1: J1.12, U1.40 (IO40), U2.14 (O1)
/D2: J1.9, U1.39 (IO39), U2.15 (O2)
/D3: J1.16, U1.37 (IO37), U2.18 (O3)
/D4: J1.18, U1.36 (IO36), U2.19 (O4)
/D5: J1.19, U1.34 (IO34), U2.20 (O5)
/D6: J1.14, U1.33 (IO33), U2.21 (O6)
/D7: J1.22, U1.31 (IO31), U2.22 (O7)
/MISO: U1.28 (IO28), U4.6
/MOSI: R1.2, U1.29 (IO29)
/PHI2: J1.3, U1.18 (IO18)
/ROM_CE: U1.14 (IO14), U2.23 (~CE)
/ROM_OE: U1.6 (IO6), U2.25 (~OE~/VPP)
/R_~W: J1.7, U1.11 (IO11)
/SCK: R2.2, U1.27 (IO27)
/~IO: J1.5, U1.17 (IO17)
/~IOCTRL: J1.6, U1.21 (IO21)
/~IRQ: J1.8
/~MAP: J1.1
/~RESET: J1.4, U1.19 (IO19)
GND: C1.2, C2.1, C3.2, J1.2, J1.34, J2.3 (VSS), J2.6 (VSS), J2.12 (SHELL1), J2.13 (SHELL2), U1.10 (GND), U1.22 (GND), U1.30 (GND), U1.42 (GND), U2.16 (GND), U3.1 (GND), U4.1, U4.4, U4.7 (GND), U4.10, U4.13
unnamed: J2.1 (CD/DAT3), U4.8
unnamed: J2.2 (CMD), U4.3
unnamed: J2.5 (CLK), U4.11
unnamed: J2.7 (DAT0), R4.1
unnamed: R1.1, U4.2
unnamed: R2.1, U4.12
unnamed: R3.1, U4.9
unnamed: R4.2, U4.5
VCC: C1.1, C2.2, J1.33, U1.3 (VCC), U1.15 (VCC), U1.23 (VCC), U1.35 (VCC), U2.32 (VCC), U3.3 (VI)

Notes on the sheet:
[3F3]

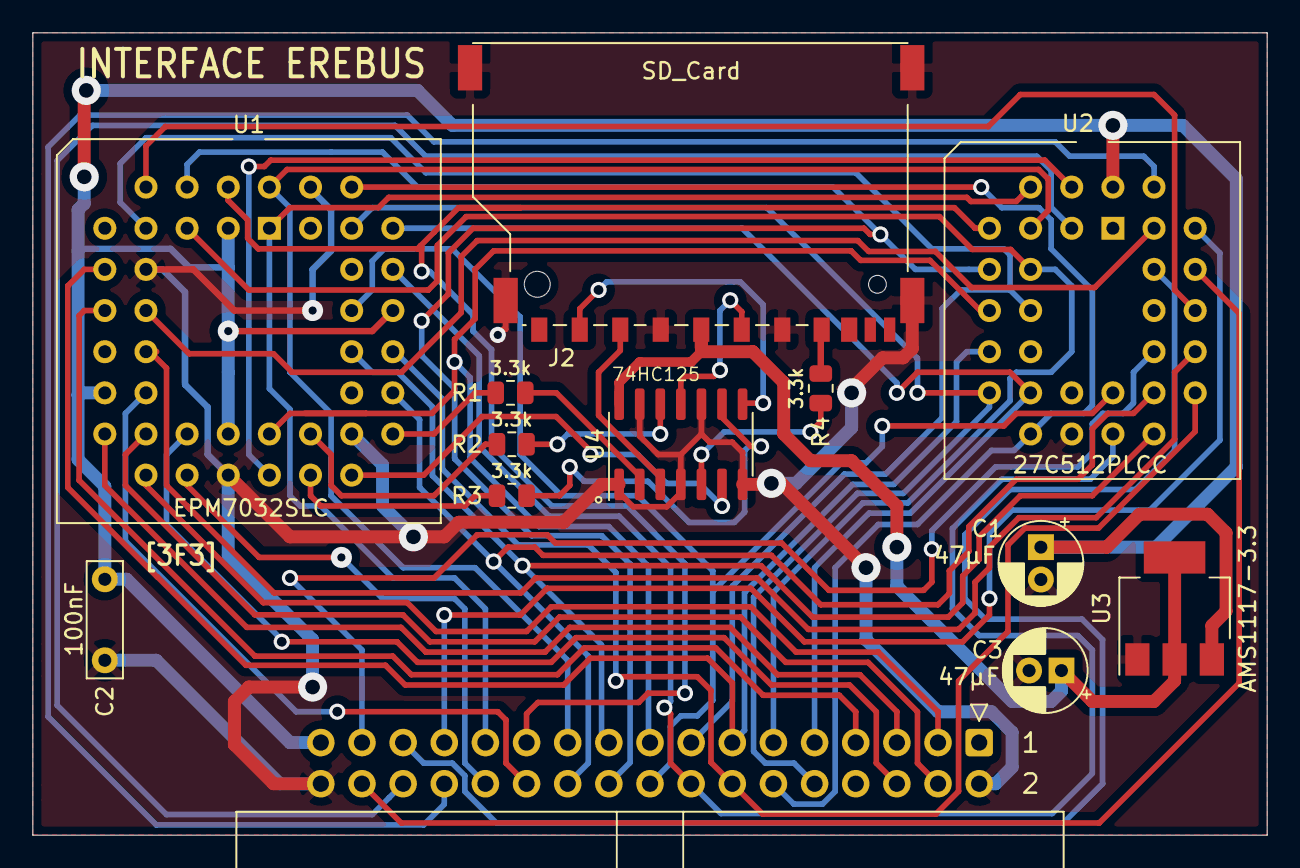
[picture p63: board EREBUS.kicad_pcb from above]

Board: 2 copper layers, 76.2 x 49.5 mm, 13 parts (0 on the bottom side), 48 nets.

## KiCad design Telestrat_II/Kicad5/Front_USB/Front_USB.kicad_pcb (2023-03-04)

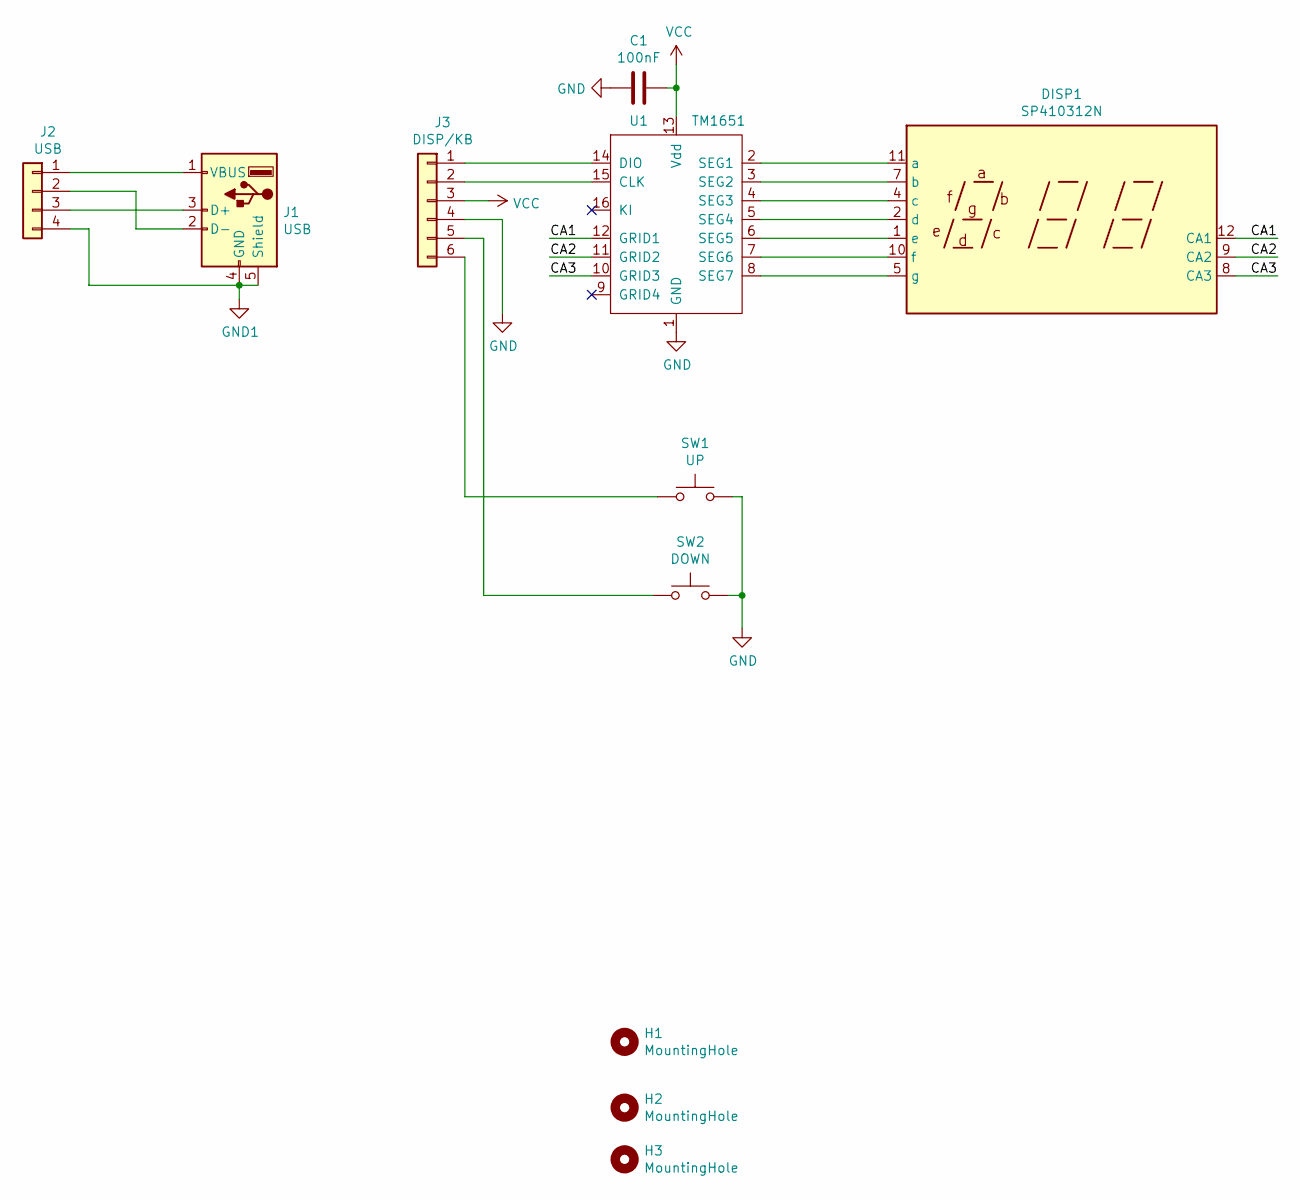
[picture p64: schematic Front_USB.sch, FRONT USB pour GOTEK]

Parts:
C1: 100nF; C_0805_2012Metric
DISP1: SP410312N; SP410312SPN
H1, H2: MountingHole; MountingHole_4.3mm_M4
H3: MountingHole; MountingHole_2.2mm_M2
J1: USB; USB_A_Vertical
J2: USB; PinHeader_1x04_P2.54mm_Vertical
J3: DISP/KB; PinHeader_1x06_P2.54mm_Vertical
SW1: UP; SW_PUSH_6mm
SW2: DOWN; SW_PUSH_6mm
U1: TM1651; SO-16_3.9x9.9mm_P1.27mm

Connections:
/CA1: DISP1.12 (CA1), U1.12 (GRID1)
/CA2: DISP1.9 (CA2), U1.11 (GRID2)
/CA3: DISP1.8 (CA3), U1.10 (GRID3)
GND: C1.2, J3.4, SW1.2, SW2.2, U1.1 (GND)
GND1: J1.4 (GND), J1.5 (Shield), J2.4
unnamed: DISP1.1 (e), U1.6 (SEG5)
unnamed: DISP1.2 (d), U1.5 (SEG4)
unnamed: DISP1.4 (c), U1.4 (SEG3)
unnamed: DISP1.5 (g), U1.8 (SEG7)
unnamed: DISP1.7 (b), U1.3 (SEG2)
unnamed: DISP1.10 (f), U1.7 (SEG6)
unnamed: DISP1.11 (a), U1.2 (SEG1)
unnamed: J1.1 (VBUS), J2.1
unnamed: J1.2 (D-), J2.2
unnamed: J1.3 (D+), J2.3
unnamed: J3.1, U1.14 (DIO)
unnamed: J3.2, U1.15 (CLK)
unnamed: J3.5, SW2.1
unnamed: J3.6, SW1.1
VCC: C1.1, J3.3, U1.13 (Vdd)

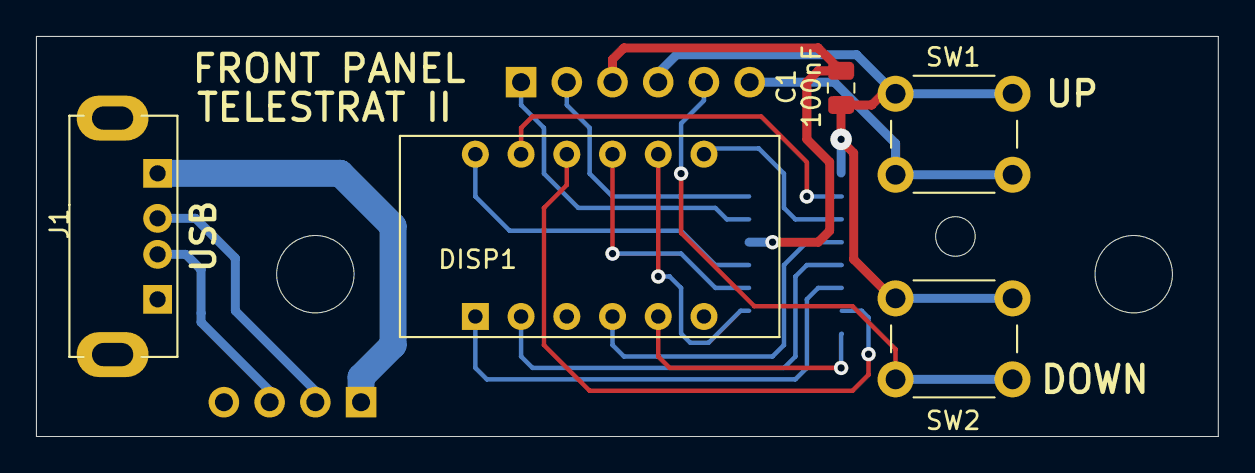
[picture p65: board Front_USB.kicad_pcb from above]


Board: 2 copper layers, 65.7 x 22.2 mm, 11 parts (3 on the bottom side), 20 nets.

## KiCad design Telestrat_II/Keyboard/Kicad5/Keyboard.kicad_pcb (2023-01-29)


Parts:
H1, H2, H3, H4: MountingHole; MountingHole_3.2mm_M3_DIN965_Pad
H5: FIX_BAR1; MountingHole_3.2mm_M3_DIN965_Pad
H6: FIX_BAR2; MountingHole_3.2mm_M3_DIN965_Pad
H7, H8, H9, H10: Fix_Cable; MountingHole_2.2mm_M2_DIN965_Pad
J1: CLAVIER; PinHeader_2x07_P2.54mm_Vertical
SW1: 7; SW_Gateron_MX_1.00u_Plate
SW2: J; SW_Gateron_MX_1.00u_Plate
SW3: M; SW_Gateron_MX_1.00u_Plate
SW4: K; SW_Gateron_MX_1.00u_Plate
SW5: SPACE; SW_Gateron_MX_6.25u_Plate
SW6: U; SW_Gateron_MX_1.00u_Plate
SW7: 8; SW_Gateron_MX_1.00u_Plate
SW8: Y; SW_Gateron_MX_1.00u_Plate
SW9: N; SW_Gateron_MX_1.00u_Plate
SW10: T; SW_Gateron_MX_1.00u_Plate
SW11: 6; SW_Gateron_MX_1.00u_Plate
SW12: 9; SW_Gateron_MX_1.00u_Plate
SW13: <; SW_Gateron_MX_1.00u_Plate
SW14: I; SW_Gateron_MX_1.00u_Plate
SW15: H; SW_Gateron_MX_1.00u_Plate
SW16: L; SW_Gateron_MX_1.00u_Plate
SW17: 5; SW_Gateron_MX_1.00u_Plate
SW18: R; SW_Gateron_MX_1.00u_Plate
SW19: B; SW_Gateron_MX_1.00u_Plate
SW20: ;; SW_Gateron_MX_1.00u_Plate
SW21: >; SW_Gateron_MX_1.00u_Plate
SW22: O; SW_Gateron_MX_1.00u_Plate
SW23: 0; SW_Gateron_MX_1.00u_Plate
SW24: G; SW_Gateron_MX_1.00u_Plate
SW25: V; SW_Gateron_MX_1.00u_Plate
SW26: F; SW_Gateron_MX_1.00u_Plate
SW27: 4; SW_Gateron_MX_1.00u_Plate
SW28: -; SW_Gateron_MX_1.00u_Plate
SW29: F_UP; SW_Gateron_MX_1.00u_Plate
SW30: P; SW_Gateron_MX_1.00u_Plate
SW31: E; SW_Gateron_MX_1.00u_Plate
SW32: /; SW_Gateron_MX_1.00u_Plate
SW33: CTRL; SW_Gateron_MX_1.25u_Plate
SW34: SHIFTG; SW_Gateron_MX_1.25u_Plate
SW35: FUNCT; SW_Gateron_MX_1.25u_Plate
SW36: SHIFTD; SW_Gateron_MX_2.25u_Plate
SW37: 1; SW_Gateron_MX_1.00u_Plate
SW38: ESC; SW_Gateron_MX_1.00u_Plate
SW39: Z; SW_Gateron_MX_1.00u_Plate
SW40: F_LF; SW_Gateron_MX_1.00u_Plate
SW41: DEL; SW_Gateron_MX_2.00u_Plate
SW42: A; SW_Gateron_MX_1.00u_Plate
SW43: RETURN; SW_Gateron_MX_2.25u_Plate
SW44: X; SW_Gateron_MX_1.00u_Plate
SW45: Q; SW_Gateron_MX_1.00u_Plate
SW46: 2; SW_Gateron_MX_1.00u_Plate
SW47: \\; SW_Gateron_MX_1.50u_Plate
SW48: FL_DW; SW_Gateron_MX_1.00u_Plate
SW49: ]; SW_Gateron_MX_1.00u_Plate
SW50: S; SW_Gateron_MX_1.00u_Plate
SW51: 3; SW_Gateron_MX_1.00u_Plate
SW52: D; SW_Gateron_MX_1.00u_Plate
SW53: C; SW_Gateron_MX_1.00u_Plate
SW54: FL_RG; SW_Gateron_MX_1.00u_Plate
SW55: [; SW_Gateron_MX_1.00u_Plate
SW56: W; SW_Gateron_MX_1.00u_Plate
SW57: =; SW_Gateron_MX_1.00u_Plate
SW58: \"; SW_Gateron_MX_1.00u_Plate
SW59, SW60: SPACE; SW_Gateron_MX_1.00u_Plate
U1: 4051; DIP-16_W7.62mm

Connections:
+5V: J1.13, U1.16 (VDD)
/COL0: J1.1, SW1.2, SW2.2, SW3.2, SW4.2, SW5.2, SW6.2, SW7.2, SW8.2, SW59.2, SW60.2
/COL1: J1.2, SW9.2, SW10.2, SW11.2, SW12.2, SW13.2, SW14.2, SW15.2, SW16.2
/COL2: J1.3, SW17.2, SW18.2, SW19.2, SW20.2, SW21.2, SW22.2, SW23.2, SW24.2
/COL3: J1.4, SW25.2, SW26.2, SW27.2, SW28.2, SW29.2, SW30.2, SW31.2, SW32.2
/COL4: J1.11, SW33.2, SW34.2, SW35.2, SW36.2
/COL5: J1.10, SW37.2, SW38.2, SW39.2, SW40.2, SW41.2, SW42.2, SW43.2
/COL6: J1.9, SW44.2, SW45.2, SW46.2, SW47.2, SW48.2, SW49.2, SW50.2
/COL7: J1.5, SW51.2, SW52.2, SW53.2, SW54.2, SW55.2, SW56.2, SW57.2, SW58.2
/KBD: J1.12, U1.3 (X)
/KBD0: J1.6, U1.11 (A)
/KBD1: J1.7, U1.10 (B)
/KBD2: J1.8, U1.9 (C)
GND: J1.14, U1.6 (Inh), U1.7 (VEE), U1.8 (VSS)
unnamed: SW1.1, SW9.1, SW17.1, SW25.1, SW37.1, SW44.1, SW51.1, U1.13 (X0)
unnamed: SW2.1, SW10.1, SW18.1, SW26.1, SW38.1, SW45.1, SW52.1, U1.14 (X1)
unnamed: SW3.1, SW11.1, SW19.1, SW27.1, SW33.1, SW39.1, SW46.1, SW53.1, U1.15 (X2)
unnamed: SW4.1, SW12.1, SW20.1, SW28.1, SW47.1, SW58.1, U1.12 (X3)
unnamed: SW5.1, SW13.1, SW21.1, SW29.1, SW34.1, SW40.1, SW48.1, SW54.1, SW59.1, SW60.1, U1.1 (X4)
unnamed: SW6.1, SW14.1, SW22.1, SW30.1, SW35.1, SW41.1, SW49.1, SW55.1, U1.5 (X5)
unnamed: SW8.1, SW15.1, SW24.1, SW31.1, SW42.1, SW50.1, SW56.1, U1.2 (X6)
unnamed: SW7.1, SW16.1, SW23.1, SW32.1, SW36.1, SW43.1, SW57.1, U1.4 (X7)


Board: 2 copper layers, 272.2 x 107.8 mm, 72 parts (0 on the bottom side), 22 nets.

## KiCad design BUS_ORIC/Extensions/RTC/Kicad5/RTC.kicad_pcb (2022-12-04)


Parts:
BT1: CR1220; BatteryHolder_BC501SM
C1: 47µF; CP_Radial_D5.0mm_P2.00mm
C2: 100nF; C_Rect_L7.0mm_W2.5mm_P5.00mm
C3, C6: 22pF; C_Disc_D4.3mm_W1.9mm_P5.00mm
C5: 50pF; Trimmer_Cap_TZ03F
D1: 1N4148; D_DO-35_SOD27_P7.62mm_Horizontal
J1: SLOT1; IDC-Header_2x17_P2.54mm_Horizontal
JP1: IRQ_RTC; PinHeader_1x02_P2.54mm_Vertical
R1: 2.2k; R_Axial_DIN0204_L3.6mm_D1.6mm_P7.62mm_Horizontal
RN1: 10K; R_Array_SIP5
RN2: 22k; R_Array_SIP9
U1: ICM7170; DIP-24_W15.24mm_LongPads
U2: GAL16V8; DIP-20_W7.62mm_LongPads
Y1: 32.768kHz; Crystal_AT310_D3.0mm_L10.0mm_Horizontal_1EP_style2

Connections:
/A0: J1.13, U1.8 (A0), U2.9 (I9)
/A1: J1.15, U1.7 (A1), U2.8 (I8)
/A2: J1.17, U1.6 (A2), U2.7 (I7)
/A3: J1.11, U1.5 (A3), U2.6 (I6)
/A4: J1.20, U1.4 (A4), U2.5 (I5)
/A5: J1.21, U2.4 (I4)
/A6: J1.23, U2.3 (I3)
/A7: J1.25, U2.2 (I2)
/A8: J1.27
/A9: J1.29
/A10: J1.31
/A11: J1.32
/A12: J1.30
/A13: J1.28
/A14: J1.26
/A15: J1.24
/D0: J1.10, RN2.9 (R8), U1.15 (D0)
/D1: J1.12, RN2.8 (R7), U1.16 (D1)
/D2: J1.9, RN2.7 (R6), U1.17 (D2)
/D3: J1.16, RN2.6 (R5), U1.18 (D3)
/D4: J1.18, RN2.5 (R4), U1.19 (D4)
/D5: J1.19, RN2.4 (R3), U1.20 (D5)
/D6: J1.14, RN2.3 (R2), U1.21 (D6)
/D7: J1.22, RN2.2 (R1), U1.22 (D7)
/PHI2: J1.3, U2.19 (IO1)
/R_~W: J1.7, U2.11 (I10/~OE~)
/~CSRTC: RN1.4 (R3), U1.3 (~CS), U2.12 (IO8)
/~IO: J1.5, U2.1 (I1/CLK)
/~IOCTRL: D1.2 (A), J1.6
/~IRQ: J1.8, JP1.2
/~MAP: J1.1
/~RESET: J1.4
/~ROMDIS: J1.2
/~R_RTC: RN1.3 (R2), U1.24 (~RD), U2.13 (IO7)
/~W_RTC: RN1.2 (R1), U1.1 (~WR), U2.14 (IO6)
GND: C1.2, C2.1, J1.34, U1.11 (INT_SRC), U1.13 (GND), U2.10 (GND)
unnamed: BT1.2 (-), R1.1
unnamed: C3.2, U1.10 (OSC_IN), Y1.2
unnamed: C5.1, C6.2, U1.9 (OSC_OUT)
unnamed: C5.2, Y1.1
unnamed: D1.1 (K), U2.17 (I03)
unnamed: JP1.1, U1.12 (~INT)
VCC: BT1.1 (+), C1.1, C2.2, C3.1, C6.1, J1.33, RN1.1 (common), RN2.1 (common), U1.2 (ALE), U1.23 (VCC), U2.20 (VCC)
VMEM: R1.2, U1.14 (VBCK)


Board: 2 copper layers, 76.2 x 49.5 mm, 15 parts (0 on the bottom side), 33 nets.

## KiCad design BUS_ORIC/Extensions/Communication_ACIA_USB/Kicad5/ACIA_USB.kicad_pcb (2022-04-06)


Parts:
C1: 47µF; CP_Radial_D5.0mm_P2.00mm
C2, C3: 100nF; C_Rect_L7.0mm_W2.0mm_P5.00mm
C4, C6: 22pF; C_Disc_D3.8mm_W2.6mm_P2.50mm
C5: 100nF; C_0805_2012Metric
C7: 100nF; C_Rect_L7.0mm_W2.5mm_P5.00mm
C8: 22pF; C_Disc_D3.4mm_W2.1mm_P2.50mm
D1: 1N4148; D_DO-35_SOD27_P7.62mm_Horizontal
J1: SLOT1; IDC-Header_2x17_P2.54mm_Horizontal
J2: USB_B; USB_B_Lumberg_2411_02_Horizontal
R1: 1M; R_Axial_DIN0207_L6.3mm_D2.5mm_P10.16mm_Horizontal
U1: 65C51; DIP-28_W15.24mm_LongPads
U2: 74LS04; DIP-14_W7.62mm_LongPads
U3: 74LS30; DIP-14_W7.62mm_LongPads
U4: CH340G; SOIC-16_3.9x9.9mm_P1.27mm
Y1: 1.8432MHz; Crystal_HC49-U_Horizontal
Y2: 12MHz; Crystal_HC49-U_Vertical

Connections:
/A0: J1.13, U1.13 (RS0)
/A1: J1.15, U1.14 (RS1)
/A2: J1.17, U3.5
/A3: J1.11, U3.6
/A4: J1.20, U3.4
/A5: J1.21, U2.9
/A6: J1.23, U2.5
/A7: J1.25, U2.1
/A8: J1.27
/A9: J1.29
/A10: J1.31
/A11: J1.32
/A12: J1.30
/A13: J1.28
/A14: J1.26
/A15: J1.24
/D0: J1.10, U1.18 (D0)
/D1: J1.12, U1.19 (D1)
/D2: J1.9, U1.20 (D2)
/D3: J1.16, U1.21 (D3)
/D4: J1.18, U1.22 (D4)
/D5: J1.19, U1.23 (D5)
/D6: J1.14, U1.24 (D6)
/D7: J1.22, U1.25 (D7)
/PHI2: J1.3, U1.27 (ϕ2)
/R_~W: J1.7, U1.28 (R/~W)
/~IO: J1.5, U2.3
/~IOCTRL: D1.2 (A), J1.6
/~IRQ: J1.8
/~MAP: J1.1
/~RESET: J1.4, U1.4 (~RES)
/~ROMDIS: J1.2
GND: C1.2, C2.1, C3.1, C4.1, C5.2, C6.1, C7.2, C8.1, J1.34, J2.4 (GND), J2.5 (Shield), U1.1 (VSS), U1.9 (~CTS), U2.7 (GND), U3.7 (GND), U4.1 (GND)
unnamed: C4.2, U4.7 (XI), Y2.1
unnamed: C5.1, U4.4 (V3)
unnamed: C6.2, U4.8 (XO), Y2.2
unnamed: C8.2, R1.2, U1.6 (XTAL1), Y1.1
unnamed: D1.1 (K), U1.3 (~CS2), U3.8
unnamed: J2.2 (D-), U4.6 (UD-)
unnamed: J2.3 (D+), U4.5 (UD+)
unnamed: R1.1, U1.7 (XTAL2), Y1.2
unnamed: U1.10 (TxD), U4.3 (RXD)
unnamed: U1.11 (~DTR), U1.16 (~DCD), U1.17 (~DSR)
unnamed: U1.12 (RxD), U4.2 (TXD)
unnamed: U2.2, U3.1
unnamed: U2.4, U3.11
unnamed: U2.6, U3.2
unnamed: U2.8, U3.3
VCC: C1.1, C2.2, C3.2, C7.1, J1.33, U1.2 (CS1), U1.15 (VCC), U2.14 (VCC), U3.12, U3.14 (VCC), U4.16 (VCC)

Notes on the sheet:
31C-31F


Board: 2 copper layers, 76.2 x 49.5 mm, 18 parts (0 on the bottom side), 38 nets.

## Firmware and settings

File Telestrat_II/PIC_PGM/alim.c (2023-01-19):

#pragma config |=0xFEB

# pragma bit RST @ GPIO.0
# pragma bit RELAY @ GPIO.1
# pragma bit BT @ GPIO.3

void tempo_131ms();


uns8 state;
uns8 n;

// etat du système
// 0 : OFF
// 1 : ON
// 2 : RESET
// 3 : OFF vers ON
// 4 : ON vers OFF

void main ()
{
   OSCCAL=W;
   OPTION=0x87;		// TMR0 : 65ms

   TRISGPIO=0xFC;
   GPIO=0;
   state=0;
   tempo_131ms();

	while (1)
{


  switch (state)
 {
	case 0:
			RELAY=0;
			RST=0;
			if (BT==0)
				{
				  tempo_131ms();
			   	  if (BT==0)
				 		state=3;
				}
			break;

	case 1:
			RELAY=1;
			if (BT==0) 
					{
						n=0;
						do
						  {
							tempo_131ms();
						    n++;
						  }
						while ((BT==0) && (n<12));

						if (n>10) 	state=4; else state=2;
					} 
			break;

	case 2:
			RELAY=1;
			RST=1;
			tempo_131ms();
			tempo_131ms();
			RST=0;
			state=1;
			break;
	case 3:
			RELAY=1;
			while (BT==0)  tempo_131ms();
		 	state=1;
			break;

	case 4:
			RELAY=0;
			do
				 tempo_131ms();
			while (BT==0);	// bouton appuyé
			state=0;
 }

}
}


void tempo_131ms()
{
TMR0=0;
while (TMR0<10);
while (TMR0!=0);
while (TMR0<10);
while (TMR0!=0);
}

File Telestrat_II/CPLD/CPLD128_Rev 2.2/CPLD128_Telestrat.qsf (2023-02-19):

# -------------------------------------------------------------------------- #
#
# Copyright (C) 1991-2013 Altera Corporation
# Your use of Altera Corporation's design tools, logic functions 
# and other software and tools, and its AMPP partner logic 
# functions, and any output files from any of the foregoing 
# (including device programming or simulation files), and any 
# associated documentation or information are expressly subject 
# to the terms and conditions of the Altera Program License 
# Subscription Agreement, Altera MegaCore Function License 
# Agreement, or other applicable license agreement, including, 
# without limitation, that your use is for the sole purpose of 
# programming logic devices manufactured by Altera and sold by 
# Altera or its authorized distributors.  Please refer to the 
# applicable agreement for further details.
#
# -------------------------------------------------------------------------- #
#
# Quartus II 64-Bit
# Version 13.0.1 Build 232 06/12/2013 Service Pack 1 SJ Web Edition
# Date created = 09:36:25  October 16, 2022
#
# -------------------------------------------------------------------------- #
#
# Notes:
#
# 1) The default values for assignments are stored in the file:
#		CPLD128_Telestrat_assignment_defaults.qdf
#    If this file doesn't exist, see file:
#		assignment_defaults.qdf
#
# 2) Altera recommends that you do not modify this file. This
#    file is updated automatically by the Quartus II software
#    and any changes you make may be lost or overwritten.
#
# -------------------------------------------------------------------------- #


set_global_assignment -name FAMILY MAX7000S
set_global_assignment -name DEVICE "EPM7128SLC84-10"
set_global_assignment -name TOP_LEVEL_ENTITY CPLD128_Telestrat
set_global_assignment -name ORIGINAL_QUARTUS_VERSION "13.0 SP1"
set_global_assignment -name PROJECT_CREATION_TIME_DATE "09:36:25  OCTOBER 16, 2022"
set_global_assignment -name LAST_QUARTUS_VERSION "13.0 SP1"
set_global_assignment -name PROJECT_OUTPUT_DIRECTORY output_files
set_global_assignment -name ERROR_CHECK_FREQUENCY_DIVISOR "-1"
set_global_assignment -name MAX7000_DEVICE_IO_STANDARD TTL
set_location_assignment PIN_83 -to 12MHz
set_location_assignment PIN_45 -to A2
set_location_assignment PIN_48 -to A4
set_location_assignment PIN_46 -to A3
set_location_assignment PIN_49 -to A5
set_location_assignment PIN_50 -to A6
set_location_assignment PIN_51 -to A7
set_location_assignment PIN_52 -to nIO
set_location_assignment PIN_28 -to CLK_1MHz
set_location_assignment PIN_30 -to CLK_4MHz
set_location_assignment PIN_37 -to RST
set_location_assignment PIN_31 -to PHI2
set_location_assignment PIN_79 -to nVIA1
set_location_assignment PIN_80 -to nVIA2
set_location_assignment PIN_81 -to nACIA
set_location_assignment PIN_1 -to A14
set_location_assignment PIN_2 -to A15
set_location_assignment PIN_73 -to A14M
set_location_assignment PIN_74 -to A15M
set_location_assignment PIN_75 -to nCSRAM
set_location_assignment PIN_70 -to nCSROM
set_location_assignment PIN_64 -to PA0
set_location_assignment PIN_65 -to PA1
set_location_assignment PIN_67 -to PA2
set_global_assignment -name USE_CONFIGURATION_DEVICE ON
set_global_assignment -name RESERVE_ALL_UNUSED_PINS_NO_OUTPUT_GND "AS INPUT TRI-STATED"
set_global_assignment -name OPTIMIZE_HOLD_TIMING OFF
set_global_assignment -name OPTIMIZE_MULTI_CORNER_TIMING OFF
set_global_assignment -name FITTER_EFFORT "STANDARD FIT"
set_location_assignment PIN_35 -to RD_DATA
set_location_assignment PIN_36 -to RDB
set_location_assignment PIN_29 -to nMAP
set_location_assignment PIN_25 -to nCS1793
set_location_assignment PIN_15 -to IRQ1793
set_location_assignment PIN_16 -to DRQ1793
set_location_assignment PIN_27 -to WE
set_location_assignment PIN_24 -to RE
set_location_assignment PIN_34 -to RW
set_location_assignment PIN_54 -to D0
set_location_assignment PIN_55 -to D1
set_location_assignment PIN_56 -to D2
set_location_assignment PIN_57 -to D3
set_location_assignment PIN_58 -to D4
set_location_assignment PIN_60 -to D5
set_location_assignment PIN_61 -to D6
set_location_assignment PIN_63 -to D7
set_location_assignment PIN_12 -to DF0
set_location_assignment PIN_11 -to DF1
set_location_assignment PIN_10 -to DF2
set_location_assignment PIN_9 -to DF3
set_location_assignment PIN_8 -to DF4
set_location_assignment PIN_6 -to DF5
set_location_assignment PIN_5 -to DF6
set_location_assignment PIN_4 -to DF7
set_location_assignment PIN_33 -to nIRQ
set_location_assignment PIN_18 -to DS0
set_location_assignment PIN_20 -to DS1
set_location_assignment PIN_17 -to SS
set_location_assignment PIN_40 -to HLD
set_location_assignment PIN_41 -to STEP
set_location_assignment PIN_39 -to HLT
set_location_assignment PIN_76 -to RESET
set_location_assignment PIN_84 -to MODE2
set_location_assignment PIN_77 -to MODE1
set_location_assignment PIN_68 -to MODE3
set_location_assignment PIN_44 -to A13
set_global_assignment -name VHDL_FILE monostable_900ms.vhd
set_global_assignment -name VHDL_FILE monostable_20ms.vhd
set_global_assignment -name BDF_FILE HLT_8877.bdf
set_global_assignment -name VHDL_FILE div_freq1000.vhd
set_global_assignment -name BDF_FILE Timer.bdf
set_global_assignment -name BDF_FILE sequenceur.bdf
set_global_assignment -name VHDL_FILE select_ROM.vhd
set_global_assignment -name BDF_FILE div_freq.bdf
set_global_assignment -name VHDL_FILE decodage.vhd
set_global_assignment -name BDF_FILE CPLD128_Telestrat.bdf
set_global_assignment -name BDF_FILE TR_245.bdf
set_global_assignment -name VHDL_FILE MB8877_logic.vhd
set_global_assignment -name BDF_FILE Reg_273.bdf
set_location_assignment PIN_69 -to A16M
set_location_assignment PIN_21 -to nWR_RTC
set_location_assignment PIN_22 -to nRD_RTC
